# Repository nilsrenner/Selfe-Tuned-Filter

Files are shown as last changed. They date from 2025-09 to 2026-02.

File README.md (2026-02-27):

# Self-Tuned-Filter

## Kontext
Diese Bachelorarbeit wurde im März 2026 an der **Hochschule Bremen** (Fakultät 4: Elektrotechnik und Informatik) abgegeben. Ziel war das Design, die Simulation und die messtechnische Verifizierung eines analogen, selbsteinstellenden Filters auf Basis eines spannungsgesteuerten Biquad-Filters.

## Projektbeschreibung
Das System passt seine Resonanzfrequenz eigenständig an die anliegende Eingangsfrequenz an. Die zentrale Steuerung übernimmt ein **Raspberry Pi Pico 2 W**, der als digitale Schnittstelle dient.

* **Wissenschaftlicher Kern:** Eigenständige Herleitung und Verifikation der Gleichungen zur Resonanzfrequenz (Korrektur fehlerhafter Angaben im ASLK-PRO Manual).
* **Hardware:** Entwicklung eines PCB für die Umsetzung des Self-Tuned Systems.
* **Software:** MicroPython-Skript zur Steuerung des Filters über eine webbasierte Oberfläche. Nulldurchgangszähler für die Eingangsfrequenzdetektion.
* **Ergebnis:** Für frequenzgebende Widerstände von 1 kΩ wurde die Funktionalität im Bereich von ca. **240 Hz bis über 12 kHz** nachgewiesen. 

---

## Struktur des Repositoriums
Die Quelldaten sind wie folgt strukturiert:

| Ordner / Datei | Inhalt |
| :--- | :--- |
| **`001_Simulation_und_Schaltungsentwurf`** | Datenblätter, Simulationen und PCB-Entwürfe (V1 & V2). |
| **`002_3D_Modell`** | 3D-Modell der PCB-Halterung für den Versuchsaufbau. |
| **`003_Messdaten`** | Rohdaten der Messungen (Oszilloskop und Red Pitaya). |
| **`004_Code`** | MicroPython-Skripts für den Raspberry Pi Pico 2 W. |
| **`005_Dokumentation`** | LaTeX-Quellcode der Arbeit. |
| **`Bachelor_Thesis_Renner_2026.pdf`** | Die Bachelorarbeit in digitaler Form. |

---

## Autor & Prüfer
* **Autor:** Nils Renner
* **Prüfer:** Prof. Dr.-Ing. Mirco Meiners & Prof. Dr. Sören Peik

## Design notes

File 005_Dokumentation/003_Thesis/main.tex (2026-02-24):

\documentclass[a4paper,11pt]{book}

% Sprach- und Zeichencodierung
\usepackage[T1]{fontenc}       % korrekte Darstellung von Umlauten
\usepackage[utf8]{inputenc}    % UTF-8 Eingabekodierung
\usepackage[german]{babel}    % deutsche Spracheinstellungen
\usepackage{microtype}

% Mathematik
\usepackage{amsmath, amssymb, mathtools} % erweiterte Matheumgebungen
\usepackage{siunitx}                     % SI-Einheiten und Zahlenformatierung
\sisetup{per-mode=symbol}

% Layout und Formatierung
\usepackage{geometry}          % Seitenränder einstellen
\usepackage{graphicx}          % Grafiken einbinden
\usepackage{pdfpages}

\usepackage{float}             % präzise Positionierung von Bildern
\usepackage{fancyhdr}          % Kopf- und Fußzeilen
\usepackage{titlesec}          % Überschriftenformatierung
\usepackage{tocloft}           % Inhaltsverzeichnis anpassen
\usepackage{makecell}          % Zeilenumbrüche in Tabellenzellen
\usepackage{array}             % erweiterte Tabellenspalten
\usepackage{booktabs,tabularx} % schöne Tabellen
\usepackage{longtable}         % Tabellen über mehrere Seiten
\usepackage{caption}           % bessere Bild-/Tabellenunterschriften
\usepackage{subcaption}        % Subfigures
\usepackage{enumitem}          % flexible Listen
\usepackage{subfiles}           % Kapitel einzeln kompilierbar
\usepackage{tikz}
\usepackage{circuitikz}
\usetikzlibrary{arrows.meta, positioning}

\usepackage{pgfplots}
\pgfplotsset{compat=1.18}
%\newcommand{\datapath}{../../003_Messdaten}
\usepgfplotslibrary{groupplots}

% Literatur
\usepackage{csquotes}                           % saubere Anführungszeichen
\usepackage[backend=biber, style=ieee]{biblatex} % IEEE-Stil mit Biber
\addbibresource{Literaturverzeichnis.bib}       % Literaturdatenbank einbinden
\usepackage[acronym]{glossaries-extra}
\setabbreviationstyle[acronym]{long-short}
\input{acronyms.tex}
\makeglossaries

% Zusatzfunktionen
\usepackage{lastpage}    % für "Seite X von Y"
\usepackage{xcolor}      % Farben (für Listings etc.)
\usepackage{listings}    % Codeblöcke
\usepackage[hidelinks]{hyperref} % Hyperlinks (immer zuletzt)

% Einstellungen für Code
\lstset{
    basicstyle=\ttfamily\scriptsize, % Sehr kleine Schrift für Platzersparnis
    breaklines=true,                 % Automatische Zeilenumbrüche
    frame=tb,                        % Linien oben und unten
    tabsize=2,
    literate={Ω}{{\textOmega}}1,     % Ersetzt das Omega-Zeichen durch LaTeX-Befehl
    extendedchars=true,
    inputencoding=utf8
}

% Seitenlayout
\geometry{
  top=2cm,
  bottom=3cm,
  left=2.5cm,
  right=2.5cm
}
\setlength\parindent{0pt} % kein Absatzeinzug

% Kopf- und Fußzeilen
\setlength\headheight{55pt}%26
\setlength\headsep{15pt}%35
\addtolength{\topmargin}{-12pt}

\pagestyle{fancy}
\fancyhf{}
\lhead{\raisebox{-0.2cm}{}}
\chead{Bachelor Thesis\par Nils Renner}
\rhead{\raisebox{-0.2cm}{}}
\cfoot{\thepage}

% Dokumentbeginn
\begin{document}

\frontmatter
\pagenumbering{roman}
\pagestyle{empty} % unterdrückung des headers
\setcounter{page}{1}

% Titelseite
\begin{titlepage}
    \begin{center}
    \\[1cm]
    \vspace{0.5cm}
    {\huge\bfseries Implementierung eines selbsteinstellenden Filters auf Basis eines spannungsgesteuerten Biquad-Filters\par}
    \vspace{1.5cm}
    {\large\bfseries Implementation of a Self-Tuned Filter Based on a Voltage-Controlled Biquad Filter\par}
    
    \vspace{2cm}
    {\Large\bfseries Bachelor Thesis\par}
    {\large Fakultät 4: Elektrotechnik und Informatik\par} 
    {\large Studiengang: Elektrotechnik B. Eng.\par}
    {\large Vertiefungsrichtung: Informationstechnik\par}
    %Presented for Attainment of the Academic Degree of \par
    %Bachelor of Engineering at the City University of Applied Sciences Bremen\par
    \end{center}
    \vspace{2cm}

    \begin{tabular}{l l}
            \textbf{Autor:} & Nils Renner, Wulfhoopstraße 34a, 28201 Bremen \\
            \textbf{Matr.-Nr.:} & 5197659 \\
            \textbf{Abgabetermin:} & 2. März, 2026 \\ \\ \\
            \textbf{Prüfer:} & Prof. Dr.-Ing. Mirco Meiners,\\ & \small{Hochschule Bremen,}\\ & \small{Concept Engineering SoCs and Design}\\ \\
            \textbf{} & Prof. Dr. Sören Peik,\\ & \small{Hochschule Bremen,}\\ & \small{Microwave Technology and Satellite Communications} \\
    \end{tabular}

    \vfill
\end{titlepage}

\newpage
\null
\thispagestyle{empty} 

% Erklärung zur selbstständigen Arbeit
\clearpage{\pagestyle{empty}\cleardoublepage}
%\cleardoublepage % Sorgt dafür, dass das Kapitel auf einer neuen (rechten) Seite beginnt
\phantomsection 
\addcontentsline{toc}{chapter}{Erklärung über das Eigenständige Erstellen der Arbeit} 

\includepdf[pages={1}, scale=1, pagecommand={}]{KI-Eigenständigkeitserklärung_Renner.pdf}

% Acknowledgements / Danksagung
\clearpage{\pagestyle{empty}\cleardoublepage}
\chapter*{Danksagung}
\addcontentsline{toc}{chapter}{Danksagung}

An dieser Stelle möchte ich mich bei all jenen bedanken, die mich während der Erstellung dieser Bachelorarbeit unterstützt haben.\par
\medskip
Mein besonderer Dank gilt Herrn Prof. Dr.-Ing. Mirco Meiners für die Übernahme der Erstbetreuung sowie für die wertvollen Anregungen und konstruktiven Vorschläge während der Bearbeitungszeit.\par
\medskip
Ebenso bedanke ich mich herzlich bei Herrn Dipl.-Ing. Tim Ziemann für das Layout-Review und die damit verbundene Beratung.\par
\medskip
Für die technische Unterstützung danke ich Simon Cossens, der mir bei allen Fragen rund um die hardwaretechnischen Anforderungen stets als kompetenter Ansprechpartner zur Seite stand.\par
\medskip
Ein großes Dankeschön für das gründliche Korrekturlesen und das hilfreiche Feedback gebührt zudem Ali Mert Ackey, Alicia von Ahlen, Daniel Albinger, Janik Holland, Melia Keil, Finn Ringelsiep, Julian Scheeler und Jana Vogt.\par
\medskip
Abschließend möchte ich mich noch bei meinem Vater für den kontinuierlichen Austausch über meine Ideen und Pläne sowie für die wertvolle kritische Reflexion während des gesamten Prozesses bedanken. 

% Abstract
\clearpage{\pagestyle{empty}\cleardoublepage}
\chapter*{Abstrakt}
\addcontentsline{toc}{chapter}{Abstrakt}
Die vorliegende Bachelorarbeit befasst sich mit dem Design, der Simulation und der messtechnischen Verifizierung eines analogen, selbsteinstellenden Filters (Self-Tuned Filter). Ziel der Arbeit war die Entwicklung eines Systems, das seine Resonanzfrequenz eigenständig an die anliegende Eingangsfrequenz anpasst. \par
\medskip

Im Rahmen der Arbeit wurde ein PCB entwickelt, auf dem ein Raspberry Pi Pico 2 W als zentrale Steuereinheit und digitale Schnittstelle dient. Über eine webbasierte Benutzeroberfläche können die Filterparameter über Digitalpotentiometer gesteuert und die mithilfe des Nulldurchgangszählers ermittelte Frequenz systematisch erfasst und visualisiert werden. Ein wesentlicher Teil der Arbeit bestand in der eigenständigen Herleitung und Verifikation der Gleichungen zur Resonanzfrequenz des Systems, wodurch ein umfassendes Verständnis der physikalischen Zusammenhänge innerhalb des Self-Tuned Filters aufgebaut werden konnte.\par
\medskip

Ein zentrales Ergebnis der Arbeit ist der Nachweis der Funktionalität des Systems in einem Frequenzbereich von ca. \SI{240}{\hertz} bis über \SI{12}{\kilo\hertz}. Dabei konnte gezeigt werden, dass die Stabilität der Regelung maßgeblich von der Amplitude des Eingangssignals abhängt. Durch eine gezielte Pegelanpassung auf \SI{0.5}{\volt} wurde der störende AC-Anteil auf der Steuerspannung um über \SI{80}{\percent} reduziert, was den operativen Arbeitsbereich des Filters signifikant erweiterte. Die Arbeit belegt somit die erfolgreiche Realisierung eines stabilen, selbsteinstellenden Filtersystems.\par
\medskip

\section*{Abstract}
This bachelor thesis deals with the design, simulation, and metrological verification of an analog, self-tuning filter. The aim of the thesis was to develop a system that independently adjusts its resonance frequency to the applied input frequency. \par
\medskip

As part of the thesis, a PCB was developed on which a Raspberry Pi Pico 2 W serves as the central control unit and digital interface. Via a web-based user interface, the filter parameters can be controlled via digital potentiometers and the frequency determined using the zero-crossing counter can be systematically recorded and visualized. A significant part of the work consisted of independently deriving and verifying the equations for the resonance frequency of the system, which enabled a comprehensive understanding of the physical relationships within the self-tuned filter to be established.\par
\medskip

A key result of the work is the verification of the system's functionality in a frequency range from approximately \SI{240}{\hertz} to over \SI{12}{\kilo\hertz}. It was shown that the stability of the control depends significantly on the amplitude of the input signal. By specifically adjusting the level to \SI{0.5}{\volt}, the disruptive AC component on the control voltage was reduced by over \SI{80}{\percent}, which significantly expanded the filter's operational range. The work thus demonstrates the successful implementation of a stable, self-adjusting filter system.\par
\medskip

% Inhaltsverzeichnis
\clearpage{\pagestyle{empty}\cleardoublepage}
\tableofcontents

% Abbildungsverzeichnis
\clearpage{\pagestyle{empty}\cleardoublepage}
\listoffigures
\addcontentsline{toc}{chapter}{Abbildungsverzeichnis}

% Tabellenverzeichnis 
\clearpage{\pagestyle{empty}\cleardoublepage}
\listoftables
\addcontentsline{toc}{chapter}{Tabellenverzeichnis}

% Abkürzungsverzeichnis
\clearpage{\pagestyle{empty}\cleardoublepage}
\printglossary[type=\acronymtype, title=Abkürzungsverzeichnis, nonumberlist]
%\addcontentsline{toc}{chapter}{Abkürzungsverzeichnis}

\mainmatter
\pagestyle{fancy}
% Haupttext
% \newpage  
\pagenumbering{arabic}  
\setcounter{page}{1}

\subfile{Einleitung/Einleitung.tex}

% \newpage
\subfile{Tools/Tools.tex}

% \newpage
\subfile{Theorie/Theorie_alt.tex}
% \newpage
\subfile{Theorie/Theorie_neu.tex}

% \newpage
\subfile{Simulation/Simulation.tex}

% \newpage
\subfile{systemdesign/systemdesign.tex}

% \newpage
\subfile{Messung/Messung.tex}

% \newpage
\subfile{Auswertung/Auswertung.tex}

% \newpage
\subfile{Fazit/Fazit.tex}

\backmatter
\appendix
% \newpage
\printbibliography

\newpage
\chapter{Messmittel}
\begin{table}[h]
    \centering
    \begin{tabular}{c|c|c|c}
        \textbf{Messmittel} & \textbf{Hersteller} & \textbf{Bezeichnung} & \textbf{Gerätenummer} \\ \hline
        Oszilloskop & Rohde \& Schwarz & RTB2002 & 75669148 \\
        Signalgenerator & RIGOL & DG1032 & 75001816 \\
        Red Pitaya & Red Pitaya & STEMlab 125-14 & - \\
        Multimeter & Fluke & 175 & 1600 5357 \\
    \end{tabular}
\end{table}

\newpage
\chapter{KI-Prompt-Engineering}

\section{Erstellung einer python Simulation eines Slef-Tuned Filters anhand einer diskreten und proportionalen Regelung}

Für diesen Prompt wurde Le Chat von Mistral verwendet. \par
\medskip

\begin{enumerate}
\item \textbf{Rolle:} Experte für Python-Programmierung und Signalverarbeitung.
\item \textbf{Ziel:} Erstelle eine Python-Simulation eines Self-Tuned Filters (VCF), die exakt das Verhalten einer diskreten Stufenregelung auf Basis der Phasenlage abbildet.
\item \textbf{Logik:} Erzeuge ein Referenz-Sinussignal (\SI{1000}{\hertz}) und ein VCF-Signal (Start: \SI{1050}{\hertz}). Prüfe die Phase des VCF-Signals exakt an den positiven Nulldurchgängen der Referenz.
\item \textbf{Regelgesetz:} Befindet sich die Phase im Bereich von \SI{-90}{\degree} bis \SI{90}{\degree}, wird die Frequenz um \SI{10}{\hertz} erhöht; andernfalls wird sie um \SI{10}{\hertz} verringert.
\item \textbf{Implementierung:} Das VCF-Signal muss durch fortlaufende Integration der Phase berechnet werden , um Phasensprünge bei Frequenzänderungen zu vermeiden.
\end{enumerate}

Anschließend wird der Code erweitert, sodass die Frequenzsprünge proportional anhand der Phasenlage verändert werden.\par
\medskip

\begin{enumerate}
\item \textbf{Ziel:} Modifiziere die vorherige Simulation hin zu einer proportionalen Regelung (P-Regler).
\item \textbf{Setup:} Erhöhe die Simulationsdauer auf \SI{0.5}{\second}.
\item \textbf{Logik:} Die Frequenzänderung soll nun kontinuierlich erfolgen. Die Stärke der Korrektur  wird über eine trigonometrische Gewichtung (z. B. Absolutwert des Cosinus der Phase) gesteuert.
\item \textbf{Verhalten:} Dies stellt sicher, dass in der Umgebung von \SI{0}{\degree} und \SI{180}{\degree} maximale Frequenzänderungen resultieren, während die Korrektur an den Arbeitspunkten \SI{90}{\degree} und \SI{270}{\degree} gegen Null strebt.
\item \textbf{Richtung:} Ist die Phase im Bereich von \SI{-90}{\degree} bis \SI{90}{\degree} soll die Frequenz erhöht werden, andernfalls wird die Frequenz verringert.
\end{enumerate}

\newpage

\section{Erstellung des HTTP-Server und Erweiterung des Frequenzzählers}
\label{sec:prompt3}

Dieser Prompt dient der finalen Migration des Projekts auf Hardware-gestützte Frequenzmessung. Für diesen Prompt wurde Gemini 3 Flash von Google verwendet. \par
\medskip

\begin{enumerate}
    \item \textbf{Rolle:} Experte für Embedded Systems (RP2350) und Python-Webentwicklung.
    \item \textbf{Ziel:} Erweitere mein Python-Skript für einen Raspberry Pi Pico (RP2040). Der aktuelle Code enthält eine SPI-Ansteuerung für Digitalpotentiometer, einen Webserver im AP-Modus und einen IRQ-Frequenzzähler.
    \item \textbf{Upgrade:} Ersetze den IRQ-Zähler durch einen PIO-Zähler (Pin 21). Die CPU darf nicht blockiert werden. Implementiere einen \texttt{machine.Timer} (2s Intervall), der den Wert ausliest und auf 1 Hz rundet. Speichere die letzten 5 Messwerte.
    \item \textbf{UI:} Erstelle ein zweispaltiges HTML-Layout. Links: Eingabefelder für Frequenz, Güte und Verstärkung sowie aktuelle Zustände. Rechts: Tabelle der letzten 5 Messwerte. Auto-Refresh: 15s.
    \item \textbf{Performance:} Der Webserver muss sofort reagieren (Nutzung globaler Variablen).
    \item \textbf{Basis-Code:}
\end{enumerate}

\lstset{
    basicstyle=\ttfamily\scriptsize,
    breaklines=true,
    extendedchars=true,
    literate={-}{{-}}1 % Verhindert Probleme mit Bindestrichen
}

\begin{lstlisting}[caption={Basis-Code Teil 1: Setup und Logik}]
import math
from machine import Pin, SPI
import network, socket, time

led = Pin("LED", Pin.OUT)
for _ in range(5):
    led.value(1); time.sleep(0.1)
    led.value(0); time.sleep(0.1)
led.value(1)

# Parameter und Berechnungen
freq0, Q_val, H0_val = 160, 1, 1
max_step, r_ges, wiper_r = 255, 9650, 4

def clamp_and_round(x):
    return int(round(max(0, min(255, x))))

def freq_2_bit(f0):
    w0 = f0 * 2 * 3.14159
    r = 1/(w0 * 1e-6)
    wiper = max_step * (1 - r/r_ges) + wiper_r
    return clamp_and_round(wiper), r

def Q_2_bit(Q_val):
    r_opv = 1000
    Q_r = Q_val * r_opv
    Q_wiper = max_step * (1 - Q_r/r_ges) + wiper_r
    return clamp_and_round(Q_wiper), Q_r

def H0_2_bit(H0_val):
    r_opv = 1000
    H0_r = r_opv/H0_val
    H0_wiper = max_step * (1 - H0_r/r_ges) + wiper_r
    #H0_wiper = int(round(H0_wiper))
    return clamp_and_round(H0_wiper), H0_r

def bit_2_res(bit):
    res = r_ges * (1 - (bit-wiper_r)/max_step) 
    return res

\end{lstlisting}

\begin{lstlisting}[caption={Basis-Code Teil 2: Hardware-Schnittstellen}]
def update_filter(f, q, h):
    fw, fr = freq_2_bit(f)
    set_wiper0(cs1, fw); set_wiper1(cs1, fw)

# Hardware Konfiguration (SPI & Pins)
spi = SPI(0, baudrate=1000000, sck=Pin(18), mosi=Pin(19), miso=Pin(16))
cs1, cs2 = Pin(17, Pin.OUT, value=1), Pin(20, Pin.OUT, value=1)

def mcp_write(cs, cmd, val):
    cs.value(0)
    spi.write(bytes([cmd & 0xFF, val & 0xFF]))
    cs.value(1)

def set_wiper0(c, v): mcp_write(c, 0, v)
def set_wiper1(c, v): mcp_write(c, 16, v)

# WLAN Access Point starten
ap = network.WLAN(network.AP_IF)
ap.active(True)
ap.config(essid="Pico-Filter", password="filter123")
ap.ifconfig(("192.168.4.1", "255.255.255.0", "192.168.4.1", "8.8.8.8"))
\end{lstlisting}

\end{document}

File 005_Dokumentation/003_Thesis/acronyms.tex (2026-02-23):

\newacronym{pll}{PLL}{Phase-Locked Loop}%

%\newacronym{digipot}{DP}{Digitalpotentiometer}

\newacronym{opv}{OPV}{Operationsverstärker}%fertig

\newacronym{pd}{PD}{Phasendetektor}%

\newacronym{vco}{VCO}{Voltage-Controlled Oscillator}%

\newacronym{vcf}{VCF}{Voltage-Controlled Filter}%

\newacronym{pcb}{PCB}{Printed Circuit Board}%

\newacronym{mcu}{MCU}{Microcontroller Unit}%

\newacronym{gpio}{GPIO}{General Purpose Input Output}

\newacronym{spi}{SPI}{Serial Peripheral Interface}

\newacronym{adc}{ADC}{Analog Digital Converter}%

\newacronym{ui}{UI}{User Interface}

\newacronym{wlan}{WLAN}{Wireless Local Area Network}

\newacronym{eeprom}{EEPROM}{Electrically Erasable Programmable Read-Only Memory}

\newacronym{http}{HTTP}{Hypertext Transfer Protocol}

\newacronym{html}{HTML}{Hypertext Markup Language}

\newacronym{ip}{IP}{Internet Protocol}

\newacronym{ram}{RAM}{Random Access Memory}

\newacronym{gbw}{GBW}{Gain Bandwidth Product}

%\newacronym{sf}{SF}{Scale Factor}

\newacronym{ic}{IC}{Integrated Circuit}

\newacronym{dut}{DUT}{Device Under Test}

\newacronym{smd}{SMD}{Surface Mounted Device}

\newacronym{tht}{THT}{Through Hole Technology}

\newacronym{bnc}{BNC}{Bayonet Neill Concelman}

\newacronym{moscow}{MoSCoW}{Must-have, Should-have, Could-have, Won't-have}

\newacronym{llm}{LLM}{Large Language Model}

\newacronym{ecad}{ECAD}{Electronic Computer-Aided Design}

\newacronym{pio}{PIO}{Programmable Input/Output}

\newacronym{fsk}{FSK}{Frequency Shift Keying}

%fft

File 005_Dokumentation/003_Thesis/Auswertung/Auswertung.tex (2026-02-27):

\documentclass[../main_config.tex]{subfiles}
\begin{document}

\chapter{Auswertung}

In diesem Kapitel werden die Ergebnisse der Endmessungen präsentiert und analysiert. Da die zweite Platineniteration erst zwei Wochen vor der Abgabe eintraf, beziehen sich alle nachfolgenden Messwerte auf die Version 1 des \gls{pcb}.\par
\medskip

Die vorgestellten Ergebnisse basieren somit auf der erste Iteration, welche mit einer Versorgungsspannung von \SI{\pm11}{\volt} betrieben wird. Die resultierende Referenzspannung der Multiplizierer beträgt dabei anstatt der angestrebten \SI{10}{\volt} nur etwa \SI{9.74}{\volt}. Die Ergebnisse der zweiten Platineniteration werden im Rahmen der Verteidigung vorgestellt.\par
\medskip

\section{Kleinsingnalanalyse des Gesamtsystems}
Die Kleinsignalanalyse über den Red Pitaya liefert auch nach der Optimierung der einzelnen Bauteile des Systems keine neuen Ergebnisse. Der bisher ungeklährte Verlauf bleibt konsistent und ist in Abbildung \ref{fig:ac_final} dargestellt.\par
\medskip

\begin{figure} [H]
  \centering
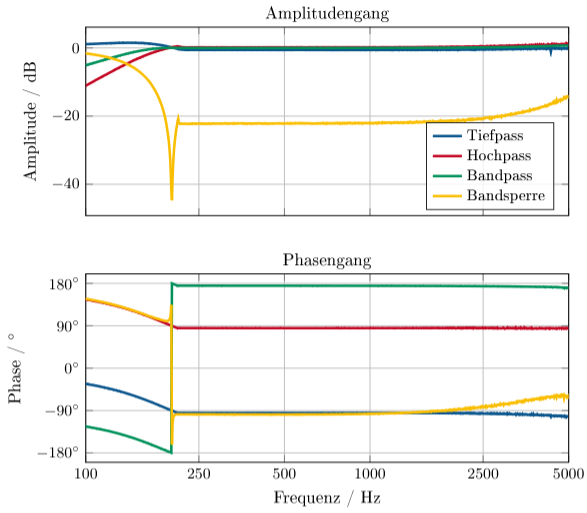
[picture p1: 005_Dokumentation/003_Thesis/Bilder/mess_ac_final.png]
    
    \caption{ac-Final}
    \label{fig:ac_final}
\end{figure}

%\begin{figure} [H]
%  \centering
%    \includegraphics[width=0.9\linewidth]{../Bilder/ac_final.png}
%    \caption{ac-Final}
%    \label{fig:ac_final}
%\end{figure}

Wie bereits in Kapitel \ref{sec:mess_ac} erläutert, stagnieren die Amplituden- und Phasenverläufe kurz nach Erreichen der Resonanzfrequenz. Eine Vermutung für dieses Verhalten hängt mit der Arbeitsweise des Self-Tuned Filters zusammen, der versucht seine Resonanzfrequenz immer auf die eingehende Frequenz einzustellen. \par
\medskip

Wird nun ein in der Frequenz kontinuierlich steigendes Eingangssignal angelegt, stellt sich der Filter erst in Richtung der geringen Startfrequenz ein. In Abbldung \ref{fig:ac_final} ist bei etwa \SI{200}{\hertz} zu sehen, wie Resonanzfrequenz und Eingangsfrequenz übereinstimmen. Anschließend versucht der Fitler der steigenden Eingangsfrequenz zu folgen, bleibt aber aufgrund der gerineren Änderungsrate hinter der Eingangsfrequenz zurück. In diesem Fall wäre die Kleinsignalanalyse nicht zur Charakterisierung des Filters geeignet.\par
\medskip

Um diese Hypothese zu überprüfen, wird die Anzahl der Messpunkte von \num{100} auf \num{1000} erhöht. Die höhere Anzahl führt zu einer langsameren Veränderung der Eingangsspannung, da der Red Pitaya die Frequenzpunkte nacheinander abarbeitet und jeder eine bestimmte Aufnahmezeit benötigt. Die dabei aufgenommenen Ergebnisse zeigen keine Veränderung zu vorherigen Messungen. Das Problem besteht also nicht in der zu geringen Änderungsrate des Systems. \par
\medskip

Das genaue Verhalten des Systems bei der Kleinsignalanalyse kann durch diese alleinige Beobachtung also nicht genau geklärt werden. \par
\medskip

\section{Frequenz-Sprungantworten des Gesamtsystems}
Um die Erkenntnisse aus Theorie und Simulation zu validieren, werden in diesem Abschnitt die experimentellen Ergebnisse der Sprungantwort ausgewertet und mit der Simulation verglichen.\par
\medskip

Dabei soll zunächst untersucht werden, inwieweit die Resonanzfrequenz des Filters der eingehenden Frequenz im stationären Zustand (ohne \gls{fsk}-Modulation) folgt. In Tabelle \ref{tab:ausw_mess_mfreq2} ist die gemessene Steuerspannung $V_c$ sowie die daraus berechnete Resonanzfrequenz $f_0$ für verschiedene Eingangsfrequenzen bei einer Eingangsamplitude von $V_{in_{pp}} = \SI{2}{\volt}$ aufgelistet.\par
\medskip

\begin{table}[h]
    \centering
    \begin{tabular}{c|c|c|c}
        \textbf{Eingang $f_{in}$ / \si{\hertz}} & \textbf{Messung $V_c$ / \si{\volt}} & \textbf{$f_0$ / \si{\hertz}} & \textbf{Abweichung / \%}  \\ \hline
        %230 & 8.9 & 174 & - \\
        250 & 7.61 & 204 & -18.4 \\
        500 & 3.62 & 428 & -14.4 \\
        750 & 2.42 & 641 & -14.5 \\
        1000 & 1.82 & 852 & -14.8 \\
        2000 & 0.92 & 1685 & -15.8 \\
        3000 & 0.6 & 2584 & -13,9 \\
        4000 & 0.42 & 3690 & -7,8 \\
    \end{tabular}
    \caption{Vergleich der Mittenfrequenz bei Variation von $f_{in}$}
    \label{tab:ausw_mess_mfreq2}
\end{table}

Die Ergebnisse zeigen eindeutig, dass das System über die Steuerspannung auf die eingehende Frequenz reagiert. Auffällig ist dabei die fast konstante Abweichung von etwa \SI{14}{\percent} bis \SI{16}{\percent} im Bereich zwischen \SI{500}{\hertz} und \SI{3000}{\hertz}. Dieser stabile Offset könnte bedeuten, dass kein Fehler in der Regelung vorliegt, sondern ein unbekannter systematischer Skalierungsfehler kompensiert wird. So werden auftretende Bauteiltolleranzen oder Abweichungen der realen Multipliziererkonstante von den theoretischen Idealwerten mit in das Regelverhalten einbezogen. Demnach weißt das System ein stabiles Einschwingverhalten auf, regelt sich selbst aufgrund von unbekannten Einflussfaktoren auf einen Arbeitspunkt mit konstantem Offset ein.\par
\medskip

\subsection{Analyse des AC-Anteils auf der Steuerspannung}
In Abbildung \ref{fig:sprung_mess_vc} ist das Einschwingverhalten über den Frequenzsprung von \SI{750}{\hertz} nach \SI{3}{\kilo\hertz} sowie den Rücksprung abgebildet. Dabei ist ersichtlich, dass der Gleichspannungsanteil von $V_c$ mit einer Wechselspannung hoher Amplitude überlagert wird. \par
\medskip

\begin{figure} [H]
  \centering
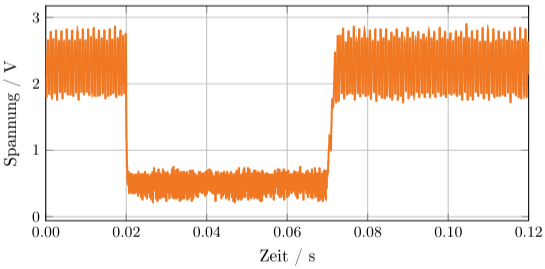
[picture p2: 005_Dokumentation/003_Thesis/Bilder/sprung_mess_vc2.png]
    
    \caption{Einschwingverhalten der Steuerspannung $V_c$ für $V_{in_{pp}} = \SI{2}{\volt}$}
    \label{fig:sprung_mess_vc}
\end{figure}

%\begin{figure} [H]
%  \centering
%    \includegraphics[width=0.9\linewidth]{../Bilder/sprung_mess_vc.png}
%    \caption{Einschwingverhalten der Steuerspannung $V_c$ für $V_{in_{pp}} = \SI{2}{\volt}$}
%    \label{fig:sprung_mess_vc}
%\end{figure}

Bei der Betrachtung der Tabelle \ref{tab:ausw_mess_vc} fällt auf, dass die Amplitude des AC-Anteils für geringe Eingangsfrequenzen deutlich zunimmt. Diese Beobachtung lässt sich anhand der Multiplikation im \gls{pd} erklären, da bei höheren Eingangsfrequenzen höherfrequente Mischprodukte erzeugt werden. Der Integrator im \gls{pd} weist Tiefpassverhalten auf, wodurch diese höheren Frequenzen deutlich besser unterdrückt werden können. Eine hohe AC-Komponente ist für das Filterverhalten ungünstig, da die nutzbare Bandbreite des Systems einschränkt wird.\par
\medskip

\begin{table}[h]
    \centering
    \begin{tabular}{c|c|c|c}
        \textbf{Eingang: $f_{in}$ / \si{\hertz}} & \textbf{$V_p+$ / \si{\volt}} & \textbf{$V_p-$ / \si{\volt}} & \textbf{AC-Anteil / \si{\volt}}  \\ \hline
        240 & 10.06 & 6.9 & 3.16 \\
        500 & 4.47 & 2.92 & 1.55 \\
        1000 & 2.28 & 1.37 & 0.91 \\
        2000 & 1.18 & 0.6 & 0.58 \\
        4000 & 0.66 & 0.16 & 0.5 \\
        4250 & 0.65 & 0.12 & 0.53 \\
    \end{tabular}
    \caption{Vergleich des AC-Anteils der Mittenfrequenz bei Variation von $f_{in}$}
    \label{tab:ausw_mess_vc}
\end{table}

Im Verlauf der Messungen wurde festgestellt, dass die Höhe der AC-Komponente direkt von der Amplitude des Eingangssignals abhängt. Da $V_{in}$ eine der beiden Eingangsgrößen des \gls{pd} ist, sinkt bei Verringerung der Amplitude somit auch der Pegel der AC-Komponente. Um die Stabilität zu erhöhen, wird für die finalen Messungen eine geringere Spitze-Spitze-Spannung von $V_{in_{pp}} = \SI{0.5}{\volt}$ gewählt. Einen Spannungswert unterhalb von \SI{0.3}{\volt} kann vom System nicht mehr als Eingangssignal detektieren. (System verhält sich als läge kein Signal an.)\par
\medskip

Bei der Gegenüberstellung der Messdaten fällt eine gewaltige Reduktion der AC-Komponente durch die Anpassung der Eingangsfrequenz auf. Die prozenzuale Reduktion dieses Störfaktors liegt bei den Vergleichsfrequenzen von \SI{240}{\hertz}, \SI{1000}{\hertz} und \SI{2000}{\hertz} konsistent bei über \SI{80}{\percent}. \par
\medskip

\begin{table}[h]
    \centering
    \begin{tabular}{c|c|c|c}
        \textbf{Eingang: $f_{in}$ / \si{\hertz}} & \textbf{$V_p+$ / \si{\volt}} & \textbf{$V_p-$ / \si{\volt}} & \textbf{AC-Anteil / \si{\volt}}  \\ \hline
        240 & 10.22 & 9.7 & 520 \\
        500 & 3.9 & 3.67 & 230 \\
        1000 & 1.99 & 1.84 & 150 \\
        2000 & 1 & 0.89 & 110 \\
        5000 & 0.42 & 0.33 & 90 \\
    \end{tabular}
    \caption{AC-Anteil bei reduzierter Eingangsspannung $V_{in_{pp}}=\SI{0.5}{\volt}$}
    \label{tab:ausw_mess_mfreq05}
\end{table}

%Für die Bestimmung der unteren Frequenzgrenze des Systems wird beobachtet, ab welcher Frequenz die positiven Spitzen der AC-Komponente $V_p+$ die Sättigungsgrenze des Integrators erreichen. Bei einer Versorgungsspannung von \SI{\pm11}{\volt} wird die Spannung bei etwa \SI{10.44}{\volt} gekappt. Demnach ist \SI{240}{\hertz} die unterste einstellbare Frequenz, die nicht durch die Sättigungsgrenze verfälscht wird. Interessanter weise gilt diese Frequenz sowohl für eine Eingangsspannung von $V_{in_{pp}}= \SI{2}{\volt}$ als auch für $V_{in_{pp}}= \SI{0.5}{\volt}$. \par
\medskip

%Auch für die Ermittlung der oberen Frequenzgrenze spielt die Größe der AC-Komponente eine wichtige Rolle. Da das System nicht beliebig kleine Spannungswerte für $V_c$ verarbeiten kann, ist es von Vorteil die untere Grenze der AC-Schwingung soweit wie möglich zu reduzieren. Der geringste stabile Wert liegt sowohl in der Simulation als auch in der Messung bei ca. \SI{90}{\milli\volt}. Durch die Anpassung der Eingangsspannung kann das System nun eine Frequenz von über \SI{12}{\kilo\hertz} erreichen. Oberhalb dieser Grenze treten ab \SI{12.3}{\kilo\hertz} massive Amplitudenüberhöhungen auf, die das System instabil werden lassen.\par
\medskip

Die Veränderung der Eingangsspannung stablisiert die Regelung also erheblich, da die Steuerspannung $V_c$ nun erst bei deutlich höheren Frequenzen in die Sättigungsgrenzen des Integrators läuft.

%Auch die Amplitude der AC-Anteile wird durch die verringerung der Eingangsspannung stark verringert. Das ist eideutig darauf zu erklären, dass Vin ein eingangssignal des PD ist und bei kleinerer Amplitude auch die Amplitude der ausgehenden hochfrequenzen geringer ausfallen. Dabei wird der Anteil bei hohen frequeunzen wieder sichtbar kleiner, startet aber auch schon bei einem deutlich geringeren wert. ab etwa \SI{5}{\kilo\hertz} treten kurzzeitig stärkerer Spannungsspitzen auf, die meisten werte der AC sind dabei aber um etwa 1/3 kleiner. Das könnte die Stagnation der kleiner werdenen AC-Amplitude erklären. 

Bei Vergleich des Einschwingverhaltens des realen Systems mit der optimierten Eingangsspannung mit der Simulation zeigt sich ein signifikanter Unterschied in der Einschwingzeit. Wie in Abbildung \ref{fig:sprung_mess_vc2} zusehen ist die Einschwingzeit der Messung beim positiven Sprung mit etwa \SI{20}{\milli\second} etwa doppelt so schnell wie die Simulation. Noch größer ist der Unterschied für den negativen Sprung von \SI{3000}{\hertz} auf \SI{750}{\hertz}. Hier ist das \gls{dut} ebenfalls nach etwa \SI{22}{\milli\second} eingeschwungen, die Simulation benötigt jedoch ca. \SI{80}{\milli\second}. \textbf{warum?}\par
\medskip
%Diese Abweichung deutet darauf hin, dass die reale Regelverstärkung des Systems, welche maßgeblich durch die Verstärkungskonstanten der analogen Multiplizierer im Phasendetektor bestimmt wird, höher ausfällt als im idealisierten Simulationsmodell hinterlegt. Zudem könnten parasitäre Effekte oder eine abweichende Charakteristik des Integrators in der Realität zu dieser beschleunigten Anpassung führen.

\begin{figure} [H]
  \centering
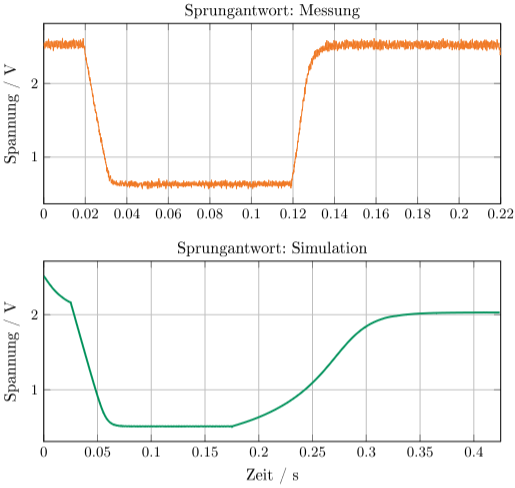
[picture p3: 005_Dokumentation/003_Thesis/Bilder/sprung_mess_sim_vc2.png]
    
    \caption{Verlauf der Steuerspannung $V_c$}
    \label{fig:sprung_mess_vc2}
\end{figure}

%\begin{figure} [H]
%  \centering
%    \includegraphics[width=0.9\linewidth]{../Bilder/sprung_mess_sim_vc.png}
%    \caption{Verlauf der Steuerspannung $V_c$}
%    \label{fig:sprung_mess_vc2}
%\end{figure}

\subsection{Betrachtung der Filterausgänge}
Nach der Untersuchung der Steuerspannung soll nun die Einschwingreaktion der einzelnen Filterausgänge analysiert werden.\par
\medskip

Der zuerst betrachtete Filtertyp ist der in Abbildung \ref{fig:sprung_mess_hp} zu sehende Hochpass. Beim positiven Frequenzsprung knickt die Amplitude interessanterweise kurzzeitig ein. Auch kann die in der Simulation sehr ausgeprägte Resonanzüberhöhung hier nicht detektert werden. Beim Rücksprung auf \SI{750}{\hertz} ist der Amplitudeneinbruch eindeutig erkennbar, da das Signal kurzzeitig im Sperrbereich des Filters liegt, bevor die Grenzfrequenz nachgeführt wird.\par
\medskip

\begin{figure} [H]
  \centering
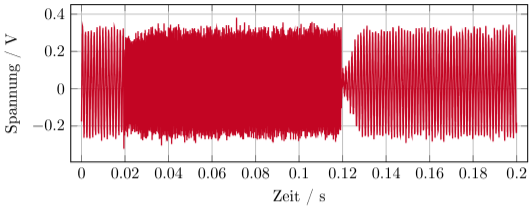
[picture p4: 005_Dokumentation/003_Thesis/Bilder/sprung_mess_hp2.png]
    
    \caption{HP}
    \label{fig:sprung_mess_hp}
\end{figure}

%\begin{figure} [H]
%  \centering
%    \includegraphics[width=0.9\linewidth]{../Bilder/sprung_mess_hp.png}
%    \caption{HP}
%    \label{fig:sprung_mess_hp}
%\end{figure}

Der Verlauf des Tiefpasses in Abbildung (Abb. \ref{fig:sprung_mess_tp}) verhält sich komplementär zum Hochpass. Der zu sehende Verlauf ist hierbei, abgesehen von der Einschwingzeit, sehr ähnlich zur Simulation. Durch den positiven Sprung erfährt die Amplitude eine starke Dämpfung. Beim negativen Sprung zeigt sich eine Amplitudenüberhöhung die ebenfalls an die in der Simulation zusehende Resonanzüberhöhung erinnert. \par
\medskip

\begin{figure} [H]
  \centering
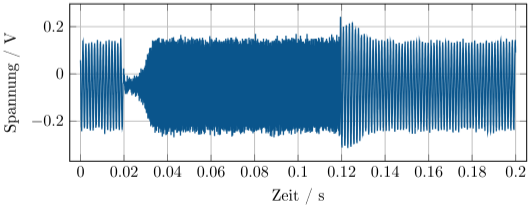
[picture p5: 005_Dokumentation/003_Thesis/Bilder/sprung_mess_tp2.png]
    
    \caption{TP}
    \label{fig:sprung_mess_tp}
\end{figure}

%\begin{figure} [H]
%  \centering
%    \includegraphics[width=0.9\linewidth]{../Bilder/sprung_mess_tp.png}
%    \caption{TP}
%    \label{fig:sprung_mess_tp}
%\end{figure}

Wie schon in der Simulation gesehen, erfährt der Bandpass (Abb. \ref{fig:sprung_mess_bp}) bei jedem Sprung einen kurzzeitigen Amplitudeneinbruch, da die Mittenfrequenz erst auf die neue Eingangsfrequenz einschwingen muss. Interessanterweise sind die Unterschiede in der Anpassungsgeschwindigkeit in der Realen Messung umgekehrt zu der in der Simulation prognostiziert. Der zweite, negative Sprung scheint in diesem Verlauf etwas schneller zu sein als der negative. Ein Zusammenhang kann dazu momentan nicht geschlossen werden aber vielleich hat das etwas mit dem kleinen Dent im HP Verlauf zutun\par
\medskip

\begin{figure} [H]
  \centering
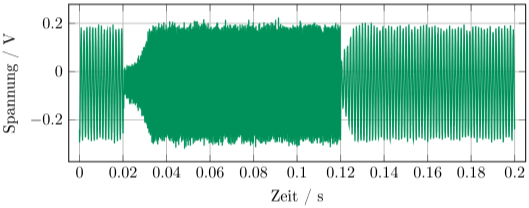
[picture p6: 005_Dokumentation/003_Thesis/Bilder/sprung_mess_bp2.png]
    
    \caption{BP}
    \label{fig:sprung_mess_bp}
\end{figure}

%\begin{figure} [H]
%  \centering
%    \includegraphics[width=0.9\linewidth]{../Bilder/sprung_mess_bp.png}
%    \caption{BP}
%    \label{fig:sprung_mess_bp}
%\end{figure}

Die Bandsperre in Abbildung \ref{fig:sprung_mess_bs} zeigt ein zum Bandpass komplementäres Verhalten. Bei Auftreten eines Sprungs wird die Amplitude des Signals erst stark erhöht und erst im Verlauf der Frequenzanpassung wieder gedämpft. Interessant ist hier der zweite Sprung bei dem die Amplitude nach dem einschwingen erst sehr klein wird, nur um im weiteren Einschwingverlauf wieder anzusteigen. (vielleich ist pendelt sich das system nicht auf den exakt richtigen wert ein sondern hat einen leichten offset zur eigendlichen Mittenfrequenz)\par
\medskip

\begin{figure} [H]
  \centering
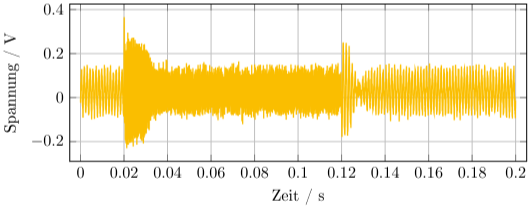
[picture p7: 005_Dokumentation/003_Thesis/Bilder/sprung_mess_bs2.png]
    
    \caption{BS}
    \label{fig:sprung_mess_bs}
\end{figure}

%\begin{figure} [H]
%  \centering
%    \includegraphics[width=0.9\linewidth]{../Bilder/sprung_mess_bs.png}
%    \caption{BS}
%    \label{fig:sprung_mess_bs}
%\end{figure}

Nach der Optimierung des Eingangsspannungslevels ähnlen alle Filterausgänge den Prognostizierten Verläufen sehr und die Signale sind sehr sauber. \par
\medskip

\subsection{Filterbereich des Gesamtsystems}
\label{sec:ausw_sprung}
\textbf{was zum sweep?}

Abschließend wird untersucht, innerhalb welcher Grenzen die Regelung des Gesamtsystems zuverlässig arbeitet und ab welchen Punkten das System versagt. Um den funktionierenden Frequenzbereich des Systems zu bestimmen, wird die Eingangsfrequenz über den Singalgenerator händisch verändert bis eine Grenze /Artefakte/ kappung der Steuerspannung zu erkennen sind. Die Ergebnisse sind in Tabelle \ref{tab:ausw_mess_grenz05} zusammengefasst. \par
\medskip

\begin{table}[h]
    \centering
    \begin{tabular}{c|c|c|c}
        \textbf{Eingang $f_{in}$ / \si{\hertz}} & \textbf{Messung $V_c$ / \si{\volt}} & \textbf{$f_0(V_c)$ / \si{\hertz}} & \textbf{Abweichung / \%} \\ \hline
        240 & 9.96 & 155 & -38  \\
        500 & 3.78 & 410 & -18 \\
        1000 & 1.9 & 816 & -18.4 \\
        2000 & 0.95 & 1637 & -18.2 \\
        5000 & 0.38 & 4101 & -18 \\
        7500 & 0.24 & 6596 & -12.1 \\
        10000 & 0.17 & 9338 & -6.6 \\
        12000 & 0.14 & 10765 & -10.3 \\
    \end{tabular}
    \caption{Optimierte Messreihe bei reduzierter Eingangsspannung $V_{in_{pp}}=\SI{0.5}{\volt}$}
    \label{tab:ausw_mess_grenz05}
\end{table}

Wie auch schon bei einer Eingangsspannung von $V_{in_{pp}}=\SI{2}{\volt}$ lässt sich auch an diesen Messwerten eine Konstante Abweichung von \SI{18}{\percent} zwischen \SI{500}{\hertz} und \SI{5000}{\hertz} beobachten. Im höheren Frequenzbereich wird die Abweichung geringer, verhält sich dabei aber nicht mehr so konsistent. Ausreißer bei dieser Messung ist die Aufnahme der Frequenz von \SI{240}{\hertz}, bei der eine Abweichung von \SI{-38}{\percent} festgestellt werden kann. \par
\medskip

Die Ursache für die massive Abweichung von \SI{-38}{\percent} am unteren Ende des Spektrums liegt in der Sättigung des Integrators im \gls{pd}. In der Abbildung \ref{fig:sprung_mess_uG} sind die Eingangsfrequenzen \SI{200}{\hertz} in rot und \SI{240}{\hertz} in blau gegenübergestellt. \par
\medskip

\begin{figure} [H]
  \centering
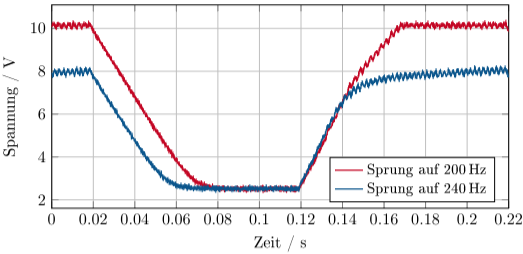
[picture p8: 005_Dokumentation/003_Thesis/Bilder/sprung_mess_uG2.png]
    
    \caption{Verhalten der Steuerspannung an der unteren Filtergrenze}
    \label{fig:sprung_mess_uG}
\end{figure}

%\begin{figure} [H]
%  \centering
%    \includegraphics[width=0.9\linewidth]{../Bilder/sprung_mess_uG.png}
%    \caption{Verhalten der Steuerspannung an der unteren Filtergrenze}
%    \label{fig:sprung_mess_uG}
%\end{figure}

Für die Bestimmung der unteren Frequenzgrenze des Systems wird beobachtet, ab welcher Frequenz die positiven Spitzen der AC-Komponente $V_p+$ die Sättigungsgrenze des Integrators erreichen. Bei einer Versorgungsspannung von \SI{\pm11}{\volt} wird die Spannung bei etwa \SI{10.44}{\volt} gekappt. Das ist gut im Verlauf der Steuerspannung für \SI{200}{\hertz} zu erkennen, bei dem der Verlauf mitten im Einschwingvorgang einen starken Knick erfährt. \par
\medskip

Bei der Betrachung der Spannungspegel für stationäre Eingangsfrequenzen stellt die in blau gezeigte Kennlinie mit \SI{240}{\hertz} die unterste einstellbare Frequenz da, bei der das Singal nicht durch die Sättigungsgrenze verfälscht wird. Für die in Abbildung \ref{fig:sprung_mess_uG} bedeutet das, dass die Steuerspannung für eine zeitlich längere obere Halbwelle noch eine weitere Steigung bis \SI{10}{\volt} erfahren sollte. Interessanter weise gilt dieser Grenzwert von \SI{240}{\hertz} sowohl für eine Eingangsspannung von $V_{in_{pp}}= \SI{2}{\volt}$ als auch für $V_{in_{pp}}= \SI{0.5}{\volt}$. \par
\medskip

Die obere Frequenzgrenze hingegen wird durch das Signal-Rausch-Verhältnis der Steuerspannung limitiert. Da das System nicht beliebig kleine Spannungswerte für $V_c$ verarbeiten kann, ist es von Vorteil die untere Grenze der AC-Schwingung soweit wie möglich zu reduzieren. Der geringste stabile Wert liegt in der Simulation bei etwa \SI{100}{\milli\volt} während es in der Messung mit ca. \SI{90}{\milli\volt} noch etwas weniger ist.\par
\medskip

Durch die Reduktion von $V_{in}$ auf \SI{0,5}{\volt} kann die obere Grenze erfolgreich auf über \SI{12}{\kilo\hertz} verschoben werden. In Abbildung \ref{fig:sprung_mess_oG} ist neben dem stabilen \SI{12}{\kilo\hertz}-Signal auch eine Eingangsfrequenz von \SI{13}{\kilo\hertz} dargestellt.\par
\medskip

\begin{figure} [H]
  \centering
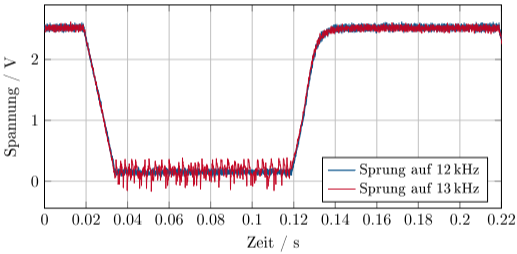
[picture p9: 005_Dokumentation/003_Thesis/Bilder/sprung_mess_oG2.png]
    
    \caption{Verhalten der Steuerspannung an der oberen Filtergrenze}
    \label{fig:sprung_mess_oG}
\end{figure}

%\begin{figure} [H]
%  \centering
%    \includegraphics[width=0.9\linewidth]{../Bilder/sprung_mess_oG.png}
%    \caption{Verhalten der Steuerspannung an der oberen Filtergrenze}
%    \label{fig:sprung_mess_oG}
%\end{figure}

Dabei ist deutlich zu erkennen, dass die Steuerspannung beim Versuch das System auf die höhere Frequenz zu regeln, anfängt wild umherzuspringen. Ab etwa \SI{12,3}{\kilo\hertz} treten massive Amplitudenüberhöhungen auf, die das Gesamtsystem instabil werden lassen. Zudem ist gut zu erkennen, dass sich das System beim Rücksprung auf die \SI{750}{\hertz} wieder fangen kann. \par
\medskip

\textbf{hier kann nochmal was zur einschwingschnelligkeit wie in der Sim geredet werden}

\section{Letzte Überlegungen für die auftretenden ungeklärten sachen}

Bei der Gesamtbetrachtung aller bisherigen Ergebnisse ist ein Muster zu erkennen, das eine gemeinsame Ursache für mehrere ungeklärte Phänomene liefert. In der Tabelle \ref{tab:ausw_mess_mfreq2} zeigte sich ein systematischer Offset der Steuerspannung zur Eingangsfrequenz, der bisher über unbekannte Einflussfaktoren erklärt wurde. Bei der genaueren Betrachtung der Ergebnisse fällt jedoch auf, dass Ungereimtheiten in der .ac-Analyse und bei den Frequenzsprungantworten der Bandsperre (BS) ein Verhalten aufweisen, das mit der gleichen Begründung erklärt werden kann. Das legt den Verdacht nahe, dass die Resonanzfrequenz des Systems nicht exakt auf die Eingangsfrequenz einstellt wird, sondern sich auf einen ungewollten negativen Offset regelt. \par
\medskip

Besonders deutlich wird dieses Verhalten am Bandsperr-Ausgang in Abbildung \ref{fig:sprung_mess_bs}, da dieser am empfindlichsten auf kleinste Frequenzänderungen reagiert. Beim negativen Frequenzsprung von \SI{3}{\kilo\hertz} auf \SI{750}{\hertz} verringert sich die Mittenfrequenz während des Einschwingvorgangs stark. Über den Einschwingverlauf wird dabei der Punkt passiert, an dem die Eingangsfrequenz exakt der Resonanzfrequenz entspricht. Dies entspricht dem Punkt der maximalen Dämpfung. In der Messung ist jedoch zu erkennen, dass die Amplitude nach diesem Minimum wieder leicht ansteigt, anstatt dort zu verbleiben. Das System regelt also ein kleines Stück über den optimalen Punkt hinaus. Ein einfaches Zurückschwingen der Regelung (positiver Offset) kann dabei ausgeschlossen werden, da beim positiven Frequenzsprung kein vergleichbares Dämpfungsartefakt auszumachen ist.\par
\medskip

Dieses Ergebnis lässt sich ebenso auf die .ac-Analyse in Abbildung \ref{fig:ac_final} übertragen. Zu Beginn der Messung startet der Filter mit einer hohen Resonanzfrequenz, während die Eingangsfrequenz noch sehr klein ist. Der Filter verringert daraufhin seine Resonanzfrequenz, bis sich beide Werte bei etwa \SI{200}{\hertz} annähern. Auch hier steuert die Regelung über den Punkt der maximalen Dämpfung hinaus, weshalb die Amplitude nach der starken Dämpfung wieder leicht ansteigt. Das kleine Artefakt, das kurz vor Erreichen der Stagnation im Plot zu sehen ist, könnte den Moment markieren, in dem der Filter versucht, der kontinuierlich steigenden Eingangsfrequenz des Sweeps wieder zu folgen. Da der Filter jedoch an seinem gewollten negativen Offset festhält, ändern sich Amplituden- und Phasenlage im weiteren Verlauf nicht mehr, was die beobachtete Stagnation erklärt.\par
\medskip

\section{Zusammenfassung}
Zusammenfassend lässt sich festhalten, dass das System trotz der festgestellten systematischen Offsets eine robuste und zuverlässige Funktionalität als Self-Tuned Filter aufweist. Die experimentelle Auswertung bestätigt, dass die Regelung über einen weiten Frequenzbereich von ca. \SI{240}{\hertz} bis über \SI{12}{\kilo\hertz} stabil arbeitet und die Mittenfrequenz der vier Filterausgänge präzise nachführt. Durch die gezielte Reduktion der Eingangsamplitude konnte die störende AC-Komponente auf der Steuerspannung um über \SI{80}{\percent} gesenkt werden, was die nutzbare Bandbreite des Filters signifikant vergrößert hat. Auch wenn das reale Einschwingverhalten deutlich schneller als in der Simulation prognostiziert abläuft und ein geringfügiger negativer Frequenz-Offset verbleibt, entsprechen die Filtercharakteristiken von Hoch-, Tief-, Bandpass und Bandsperre den theoretischen Erwartungen. Damit ist die grundsätzliche Funktionstüchtigkeit des entwickelten Gesamtsystems erfolgreich nachgewiesen.

\end{document}

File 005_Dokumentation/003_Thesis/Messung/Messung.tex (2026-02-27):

\documentclass[../main_config.tex]{subfiles}
\begin{document}

\chapter{Aufnahme der Messergebnisse}
Bevor die ersten Messungen am System gemacht werden können, muss diese ausreichend auf ihre Funktionsfähigkeit getestet werden. Aufgrund der langen Lieferzeit der bestellten Bauteile gab es im Vorfeld ausreichend Zeit ein kleines Testprotokoll zu erarbeiten.\par

\section{Funktionstest der Leiterplatte}
Nach Fertigstellung des \gls{pcb} wird zunächst der aufkommende Versorgungsstrom auf einen definierten Wert begrenzt. Anschließend wird kontrolliert, ob der Buck-Converter die \SI{3.3}{\volt} zuverlässig ausgibt. Sobald das funktioniert, kann die Ansteuerung der Digitalpotentiometer durch die \gls{mcu} programmiert werden. Mithilfe der zuvor geplanten Jumper kann der daraus resultierende Widerstandswert unabhängig von der Restschaltung gemessen und der Code dadurch validiert werden. \par
\medskip

Im nächsten Schritt könnten die fehlenden \glspl{ic} gesteckt werden um das Gesamtsystem zu vermessen. Da die Reaktion des Systems jedoch noch nicht genau bekannt ist, werden die Multiplizierer erst einmal überbrückt, um nur den bereits bekannten Biquad aufzunehmen. Der Phase-Detektor kann dabei vorerst vernachlässigt werden. Stimmen diese Ergebnisse mit den früheren Resultaten überein, kann anschließend das vollständige System vermessen werden. \par
\medskip

Auffällig ist, dass die \gls{mcu} bei anlegen der Versorgungsspannung nicht immer zuverlässig bootet. Ein möglicher Grund hierfür könnte eine nicht ausreichend stabilisierte Versorgungsspannung sein. Lösungsansätze sind zum Beispiel das Einsetzen eines Stützkondensators am $V_{sys}$-Eingang oder das Hinzufügen eines Schalters am \SI{3.3}{\volt}-Jumper. Sobald die \SI{\pm15}{\volt} erst einmal anliegen kann der Schalter gesetzt werden wonach die \gls{mcu} zuverlässig startet. Um auf Anhieb zu erkennen, dass der Pico ordnungsgemäß hochfährt, wird das Skript erweitert, sodass die Onboard-LED als Statusindikator fungiert.\par
\medskip

\subsection{Kompensation der Widerstandsabweichungen in den Digitalpotentiometern}

Bei der ersten Messung des herkömmlichen Biquads ohne Self-Tune-System zeigt sich eine deutliche Abweichung der Mittenfrequenz von der in der \gls{ui} eingestellten Frequenz. Dabei gibt es sowohl eine Diskrepanz zwischen dem theoretischen Sollwert \text{soll\_R} und dem durch den Wiper eingestellten Istwert \text{ist\_R}, als auch eine Abweichung zwischen dem Istwert und dem real abfallenden Widerstandswert. \par
\medskip

Die Abweichung zwischen dem Ist- und Sollwert ist recht einfach zu erklären. Das verwendete Potentiometer wird über ein \num{8}-Bit Steuerregister angesteuert, dass nur $2 ^8= 256$ diskrete Zustände annehmen kann. Diese Zustände sind gleichmäßig über den gesamten Widerstandsbereich verteilt, was zu einer konstanten Schrittweite führt. Die Gleichung\par
\medskip

\begin{equation}
    R_{step} = \frac{R_{max}-R_{min}}{2^{n}-1} = \frac{\SI{9980}{\ohm}-\SI{150}{\ohm}}{255} = \SI{38.5}{\ohm}
\end{equation}

beschreibt die Zusammensetzung der Schrittweite, wobei
\begin{itemize}
    \item $R_{max}$ den größt möglichen Widerstand darstellt,
    \item $R_{min}$ den kleinst möglichen Widerstand angibt.
\end{itemize}

Der Abstand zwischen zwei einstellbaren Widerstandswerten beträgt also $R_{step}=\SI{38}{\ohm}$. Bei der Umrechung eines gewünschten Widerstandswerts in einen \num{8}-Bit Wert, muss dieser auf den Bereich von \num{0} bis \num{255} normiert werden. Da der normierte Wert seltenst einer Ganzzahl entspricht, wird dieser im Skript anschließend noch gerundet. So addieren sich zur Abweichung durch die Schrittweite zusätzlich Rundungsfehler, die die Differenz zwischen Ist- und Sollwert erhöhen. \par
\medskip

%Dies beeinträchtigt stark die Differenz zwischen dem Idealwert und dem aus den Funktionen errechneten Wert. Wenn nun also ein bestimmter widerstandswert, zum Beispiel \SI{1}{\kilo\ohm}, eingestellt werden, muss dieser wert erst auf die \num{255} Steps normiert werden, die über den \gls{spi}-Bus übertragen werden können. Dabei kann es passieren, das der Wert nicht als Ganzzahl ausgegeben werden kann. Die zweite Fehlerquelle basiert also auf dem Ruden des Bitwerts für die Einstellung des Widerstandswerts. Diese addiert sich zu der ersten fehlerqelle.

Die Diskrepanz zwischen dem eingestellten Istwert und dem tatsächlich gemessenen Realwert ist nicht so einfach zu ermitteln. Darum wird im Folgenden kurz untersucht, ob die anfallenden Abweichungen durch Anpassungen im Skript kompensiert werden können. Dafür werden die Widerstände für den Ist- und Sollwert über das \gls{ui} ausgegeben. Gleichzeitig wird der Widerstand des Potentiometers \num{1} über ein Multimeter gemessen. Auf eine Messung der anderen Potentiometer wird hierbei verzichtet, da ihre Werte immer innerhalb von \SI{10}{\ohm} übereinstimmten. Die gemessenen Werte sind in der Tabelle \ref{tab:digipot_r_val} dokumentiert.

\begin{table}[h]
    \centering
    \begin{tabular}{c|c|c|c|c}
        \textbf{UI-Werte / \si{\hertz}} & \textbf{Ist-R / \si{\ohm}} & \textbf{Soll-R / \si{\ohm}} & \textbf{Real-R / \si{\ohm}} & \textbf{Differenz / \si{\ohm}} \\ \hline
        50 & 3178 & 3183 & 3244 & +61 \\
        100 & 1589 & 1591 & 1668 & +77 \\
        160 & 983 & 994 & 1067 & +73 \\
        200 & 794 & 795 & 877 & +82 \\
        300 & 529 & 530 & 611 & +81 \\
        500 & 302 & 318 & 387 & +69 \\
        750 & 227 & 212 & 310 & +98 \\
        1000 & 151 & 159 & 233 & +74 \\ 
    \end{tabular}
    \caption{Vergleich der Ist-, Soll- und Realwiderstandswerte für verschiedene Zielmittenfrequenzen}
    \label{tab:digipot_r_val}
\end{table}

Auffallend ist, dass die Differenz zwischen Real- und Sollwert immer positiv ist, was auf eine generelle Überschreitung des gewollten Werts hindeutet. Über diese Messreihe beträgt die durchschnittliche Abweichung \SI{78,2}{\ohm}. Bei Aufnahme der Widerstandswerte für $f_0 > \SI{1}{\kilo\hertz}$ zeigt sich zudem, dass der Realwiderstand des Digitalpotentiometers phyisch nicht unter ca. \SI{150}{\ohm} fallen kann. Daraus folgt, dass die Mittenfrequenz mit diesen Bauteilparametern \SI{1060}{\hertz} nicht überschreiten kann. \par
\medskip

Durch die zuvor berechnete minimale Schrittweite von \SI{38.5}{\ohm} lässt sich zudem ein weiterer interessanter Aspekt ableiten. Die minimal korrigierbare Abweichung beträgt \SI{19.25}{\ohm}. Abweichungen unterhalb dieses Fehlers können durch diese Potentiometer also nicht weiter kompensiert werden. Die durchschnittliche Differenz von Soll- und Realwert liegt mit \SI{78,2}{\ohm} deutlich höher, sodass diese durch eine Anpassung des Wiperwiderstands in Skript von \num{2} auf \num{4} Bit um $2 \cdot \SI{38.5}{\ohm} = \SI{77}{\ohm}$ verringert wird. Die Ergebnisse dieser Anpassung werden in Tabelle \ref{tab:digipot_r_val2} dokumentiert.\par
\medskip
%Die minimale Schrittweite begrenzt sich also auf \SI{38.5}{\ohm}, sodass eine Abweichung von unter \SI{19.25}{\ohm} über diesen Digitalpotentiometer nicht korrigiert werden kann. Sie ist jedoch ein vielfaches von der durchschnittlichen Abweichung wodurch der aktuelle Wiperwiderstand im Skript von \num{2} Bit auf \num{4} Bit angehoben werden kann. \par

\begin{table}[h]
    \centering
    \begin{tabular}{c|c|c|c|c}
        \textbf{\makecell{UI-Werte \\ / \si{\hertz}}} & \textbf{\makecell{Soll-R \\ / \si{\ohm}}} & \textbf{\makecell{Real-R (neu) \\ / \si{\ohm}}} & \textbf{\makecell{Differenz (neu) \\ / \si{\ohm}}} & \textbf{\makecell{Differenz (alt) \\ / \si{\ohm}}} \\ \hline
        50 & 3183 & 3064 & -115 & +61 \\
        100 & 1591 & 1566 & -25 & +77 \\
        160 & 994 & 971 & -23 & +73 \\
        200 & 795 & 784 & -11 & +82 \\
        300 & 530 & 532 & +2 & +81 \\
        500 & 318 & 298 & -20 & +69 \\
        750 & 212 & 221 & +9 & +98 \\
        1000 & 159 & 145 & -14 & +74 \\ 
    \end{tabular}
    \caption{Messwerte des Digitalpotentiometers nach Anpassung}
    \label{tab:digipot_r_val2}
\end{table}

Diese Anpassung führt zu einer deutlichen Annäherung von Soll- und Realwert. Die duchschnittliche Abweichung verbessert sich auf etwa \SI{27.4}{\ohm}. Die neuen Werte für die Differenz weisen dabei sowohl positive als auch negative Vorzeichen auf, weshalb eine erneute Anpassung des Wiperwiderstands die Abweichung nicht weiter reduziert. Die größte Abweichung tritt bei \SI{50}{\hertz} mit \SI{-115}{\ohm} Differenz auf, während die Differenzen für höhere Frequenzen deutlich kleiner werden.\par
\medskip

Diese Werte können natürlich durch eine Anpassung des Kondensatorwerts weiter erhöht werden. Zudem ändert sich die Zusammensetzung der Resonanzfrequenz für das Self-Tune-System erheblich, wodurch ebenfalls höhere Frequenzen beziehungsweise ein breiterer Frequenzbereich erreicht werden kann. \par
\medskip

\section{Messverfahren}

Im Folgenden wird die Vorgehensweise der verschiedenen Messungen am Self-Tuned Filter dokumentiert. Zunächst soll dabei mithilfe einer Bode-Analyse das allgemeine Übertragungsverhalten des Filters charakterisiert werden. Um ein tieferes Verständnis über den Einschwingvorgang des Systems zu gewinnen, wird im weiteren Verlauf zudem die Sprungantwort analysiert.\par
\medskip

Dieses Kapitel widmet sich primär dem Versuchsaufbau sowie den getroffenen Maßnahmen zur Verbesserung der Messgenauigkeit, während die detaillierten Ergebnisse in der abschließenden Auswertung besprochen werden.\par
\medskip

\subsection{Kleinsignalanalyse}
\label{sec:mess_ac}

Nach der Aktualisierung des Red Pitaya Betriebsystems auf die stabile Version 2.07-48 funkioniert die Messwertaufnahme mit der eingesteckten \gls{mcu} schließlich. Die Charakterisierung des Systems erfolgt über einen Frequenzsweep (Bode-Analyse), um den Amplituden- und Phasengang mit einem herkömmlichen Biquad-Filter zu vergleichen. Der interne Funktionsgenerator des Red Pitaya steuert das \gls{dut}, einen der Filter des Biquads, mit einem vorgegebenen Eingangssignal an. Dabei wird der Eingang 1 (IN1) des Red Pitaya zusammen mit Ausgang 1 (OUT1) des Generators an den Eingang des \gls{dut} angeschlossen, während Eingang 2 (IN2) das Ausgangssignal erfassen soll. Die gemeinsame Masseverbindung zwischen Red Pitaya und \gls{dut} sorgt für eine stabile Messumgebung.\par
\medskip

\begin{figure} [H]
    \centering
    \begin{tikzpicture}[
    node distance=2cm,
    box/.style={draw, minimum width=2.5cm, minimum height=2cm, thick},
    port/.style={draw, rounded corners=2pt, minimum width=0.8cm, inner sep=2pt, font=\small\sffamily},
    line/.style={thick}
]

%red pitaya
\node[box, minimum width=3cm, minimum height=5.5cm] (RP) {Red Pitaya};
\node[port, left=0cm of RP.north west,  yshift=-0.5cm] (IN1) {IN1};
\node[port, left=0cm of RP.west,  yshift=0.8cm] (IN2) {IN2};
\node[port, left=0cm of RP.west,  yshift=-0.8cm] (OUT1) {OUT1};
\node[port, left=0cm of RP.south west,  yshift=0.5cm] (OUT2) {OUT2};

%dut
\node[box, left=4cm of RP] (DUT) {DUT};
\node[port, left=0cm of DUT.west] (DUT_IN) {IN};
\node[port, right=0cm of DUT.east] (DUT_OUT) {OUT};
\node[port, below=0cm of DUT.south] (DUT_GND) {GND};

%linien
\draw[line, yellow!80!orange] (DUT_IN.west) -- ++(-0.4,0) |- (IN1.west);

\draw[line, orange!80!black] (DUT_OUT.east) -- ++(0.5,0) |- (IN2.west);

\draw[line, red!80!black] (OUT1.west) -- ++(-0.6,0) -- ++(0,-1.7) -| ([xshift=-0.4cm]DUT_IN.west) -- (DUT_IN.west);

\draw[line] (DUT_GND.south) -- ++(0,-1.3) -| ([xshift=-0.4cm]OUT1.south west) -- (OUT1.south west);

\draw[line] (DUT_GND.south) -- ++(0,-0.8) -| ([xshift=-1.2cm]IN1.south west) -- (IN1.south west);

    \end{tikzpicture}
    \caption{Messaufbau zur Charakterisierung des DUT mit dem Red Pitaya \cite{LabANS}}
    \label{fig:messaufbau}
\end{figure}

Vor Beginn der Messung sollte der Red Pitaya kalibriert werden, indem Ein- und Ausgang des \gls{dut} überbrückt werden, um eventuelle Offset-Fehler zu kompensieren. Interessanterweise zeigte sich in den Versuchen jedoch, dass die Messergebnisse nach dieser Kalibrierung inkonsistent waren, während die Aufnahmen ohne vorherige Kalibrierung  besser dem erwarteten Verlauf entsprachen. Da dieses Problem kurzfristig nicht gelöst werden konnte, wurde das Betriebssystem des Red Pitaya neu aufgesetzt und die weiteren Messungen an einem unkalibrierten System durchgeführt.\par
\medskip

Zudem fiel bei den ersten Messungen auf, dass die Messung bei der Verwendung von drei herkömmlichen Oszilloskop-Tastköpfen fehlschlug. Bei genauerer Beobachtung zeigte sich, dass ein im Red Pitaya eingestellter Sinus auf der Platine nicht zu sehen ist. Die Verwendung eines Kabels zwischen dem  Red Pitaya und dem \gls{dut} löst dieses Problem. \par
\medskip

Anschließend wird ein Frequenzsweep über den relevanten Frequenzbereich durchgeführt. Dabei verändert der Funktionsgenerator die Frequenz des Eingangssignals schrittweise, während gleichzeitig Amplitudenverhältnis (in dB) und Phasenverschiebung (in Grad) zwischen Ein- und Ausgangssignal aufgenommen werden. Die Ergebnisse werden als Bode-Diagramm dargestellt, das sowohl den Amplitudengang als auch den Phasengang des Filters abbildet.\par
\medskip

Über diese Analyse soll zudem auch festgestellt werden, welche der beiden Gleichungen für die Mittenfrequenz die korrekte ist. \par
\medskip

\subsection*{Erste Messungen am Gesamtsystem}
Bei der ersten Aufnahme des Gesamtsystems treten mehrere unerwartete Phänomene auf. Trotz mehrfacher Überprüfung der Widerstandswerte der Digitalpotentiometer und aller relevanten Spannungen verhält sich das System nicht wie erwartet. Obwohl die Filterparameter konstant gehalten werden zeigen die Ergebnisse der Bode-Analyse starke Inkonsistenzen. So schwankt die Mittenfrequenz $\omega_0$ am Bandsperrausgang über mehrere Messreihen hinweg stark und zeigt eine steigende Tendenz (von ca. 430 Hz bis hin zu 1519 Hz).(Die Bandsperre wird hier hauptsächlich verwendet um die Mittenfrequenz leichter beobachten zu können)\par
\medskip

\begin{figure} [H]
  \centering
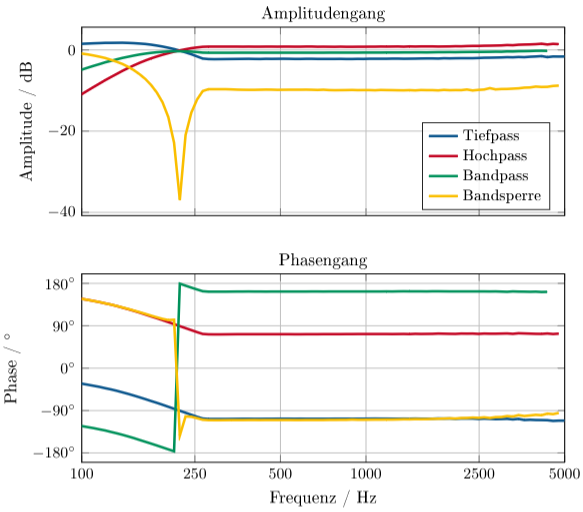
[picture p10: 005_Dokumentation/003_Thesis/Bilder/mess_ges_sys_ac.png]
    
    \caption{Amplituden und Phasenverläufe der Filter im Gesamtsystem}
    \label{fig:ges_sys_out_ac}
\end{figure}

%\begin{figure} [H]
%  \centering
%    \includegraphics[width=0.8\linewidth]{../Bilder/Messung_ges_sys_ac.png}
%    \caption{Amplituden und Phasenverläufe der Filter im Gesamtsystem}
%    \label{fig:ges_sys_out_ac}
%\end{figure}

Zusätzlich weichen die Frequenzverläufe von den charakterischtischen Verläufen ab. Der Amplitudenverlauf der Bandsperre zeigt im zweiten Durchlassbereich eine Dämpfung von etwa 8 bis \SI{10}{\decibel}. Der Phasenverlauf zeigt zudem kurz vor dem Sprung an der Mittenfrequenz eine starke Erhöhung anstatt wie in der Simulation weiter zu fallen. Am Bandpass tritt im höheren Frequenzbereich keine Dämpfung mehr auf und verhält sich entsprechend eines Hochpasses. Die Flankensteilheit am Tiefpass ist deutlich zu gering, sodass dieser eher einem Allpass entspricht.\par
\medskip

Zusammenfassend lässt sich feststellen, dass dem System die notwendige Dämpfung im höheren Frequenzbereich fehlt, wobei lediglich der Hochpass (HP) einen korrekten Verlauf beibehält.\par
\medskip

\textbf{Hypothese: diese Messmethode kann nicht mit einem solchen system gemessen werden. es sieht etwas so aus, als ob der Filter versucht hinter der eingehenden frequenz herzukommen nach erreichen der Resonanzfrequenz}\par
\medskip

Um die Ursache für die Inkonsistenzen einzugrenzen, soll der \gls{vcf} ohne Einfluss durch den Phasendetektor betrachtet werden. Durch das Entfernen von $R_{10}$ wird der Regelkreis von der Phasendetektion getrennt. Die Steuerspannung $V_c$ wird auf ein definiertes Potential von \SI{1}{\volt} gesetzt. \par
\medskip

\begin{figure} [H]
  \centering
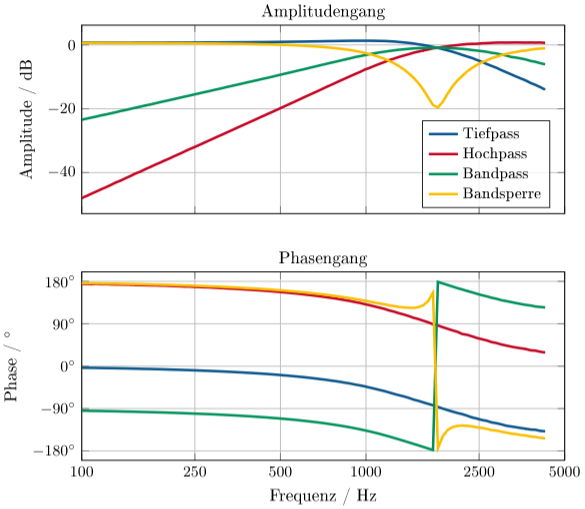
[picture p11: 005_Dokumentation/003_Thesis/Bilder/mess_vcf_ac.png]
    
    \caption{Amplituden und Phasenverläufe der Filter des VCF}
    \label{fig:vcf_out_ac}
\end{figure}

%\begin{figure} [H]
%  \centering
%    \includegraphics[width=0.8\linewidth]{../Bilder/Messung_vcf_ac.png}
%    \caption{Amplituden und Phasenverläufe der Filter des VCF}
%    \label{fig:vcf_out_ac}
%\end{figure}

Auf den ersten Blick scheinen die Verläufe der Ausgänge korrekt zu sein, sodass mit der tieferen Analyse der Mittenfrequenz begonnen werden kann.\par
\medskip

\subsection*{Experimentelle Verifizierung der Mittenfrequenzgleichung}
\label{sec:veri_omega0}
Für den herkömmlichen Biquad ligt die Mittenfrequenz für $R= \SI{1}{\kilo\ohm}$ und $C= \SI{1}{\micro\farad}$ bei etwa \SI{160}{\hertz}. Bei gleichen Parametern liegt $f_0$ für den \gls{vcf} deutlich höher. Das liegt daran, dass mit der Veränderung des Schaltungsaufbaus auch die Zusammensetzung der Mittenfrequenz beeinflusst wird. Die Mittenfrequenz des herkömmlchen Biquads ist als $\omega_0 = \frac{1}{RC}$ (Gleichung \ref{eq:w_0}) definiert, während für den \gls{vcf}-Aufbau die Referenzspannung $V_r$ und Steuerspannung $V_c$ berücksichtigt werden müssen. \par
\medskip

Die in Kapitel \ref{sec:theorie_w0} hergeleiteten Mittenfrequenzen werden hier im Folgenden nocheinmal betrachtet, um zu verifizieren welche korrekt ist. Die Gleichung \par
\medskip

\begin{equation}
    \omega_0 = \frac{V_r}{V_cRC}
    \tag{\ref{eq:filtergrenzfrequenz}}
\end{equation}

wurde dabei eigenständig hergeleitet, während die Gleichung 

\begin{equation}
    \omega_0 = \frac{V_c}{V_r \cdot RC} 
    \tag{\ref{eq:freq-vcf}}
\end{equation}

aus dem ASLK-PRO Manual stammt. Wie schon zuvor erwähnt unterscheiden sich diese beiden Gleichungen nur in dem hinzugefügten Faktor aus Referenzspannung $V_r$ und Steuerspannung $V_c$. Bei Messung dieser Signale fällt auf, dass das Potential für $V_r$ bei einer Versorgungsspannung von \SI{\pm15}{\volt} auf \SI{-13.73}{\volt} liegt und nicht wie im Datenblatt angegeben auf \SI{-10}{\volt} lasergetrimmt ist. Bei Änderung der negativen Versorgungsspannung ist zudem zu erkennen, dass $V_r$ immer etwa \SI{1.27}{\volt} unter dieser liegt. Aus diesem Grund wird die Versorgungsspannung von \SI{\pm15}{\volt} zeitweise auf \SI{\pm11}{\volt} reduziert, um mit \SI{-9.73}{\volt} deutlich näher an den angegebenen \SI{-10}{\volt} zu liegen. In der zweiten Iteration des \gls{pcb} soll der SF Pin über einen Trimmer angepasst werden können, die erste Iteration bietet diese Funktion noch nicht.\par
\medskip  

%Bei Annahme von $V_c=\SI{1}{\volt}$ und $V_r=\SI{9.73}{\volt}$ können nun die Modelle auf Richtigkeit getestet werden. 

Für die Vermessung des \gls{vcf} werden die Filterparameter wie gewohnt gewählt. Die Widerstände liegen bei etwa \SI{1}{\kilo\ohm}, die Steuerspannung $V_c$ wird auf \SI{1}{\volt} und die Referenzspannung $V_r$ auf \SI{9.73}{\volt} eingestellt. Die visuelle Auswertung der Filterverläufe zeigt zunächst einen korrekten Verlauf, weshalb die frequenzbestimmenden Widerstände im nächsten Schritt über den gesamten Filterbereich variiert werden. Die Mittenfrequenz wird dabei über den Nulldurchgang der Phase im Bandsperrenausgang ermittelt. Die Ergebnisse sind in Tabelle \ref{tab:mittenfrequenzen} zusammengefasst.\par
\medskip

\begin{table}[h]
    \centering
    \begin{tabular}{c|c|c|c}
        \textbf{Soll-R / \si{\ohm}} & \textbf{Messung: $\omega_0$ / \si{\hertz}} & \textbf{Theorie: $\omega_0$ / \si{\hertz}} & \textbf{Abweichung / \%} \\ \hline
        1591 & 1116.22 & 973.34 & 12.8 \\
        994 & 1776.34 & 1557.93 & 12.3 \\
        796 & 2140.18 & 1945.45 & 9.1 \\
        531 & 3253.12 & 2916.34 & 10.35 \\
        318 & 5789.74 & 4869.74 & 15.89 \\
        212 & 7653.34 & 7304.61 & 4.56 \\
        159 & 11570.81 & 9739.48 & 15.83 \\
    \end{tabular}
    \caption{Mittenfrequenzen und Abweichungen mit Elektrolytkondensatoren}
    \label{tab:mittenfrequenzen}
\end{table}

Die theoretischen Werte basieren auf der eigenständig hergeleiteten Gleichung \ref{eq:filtergrenzfrequenz}. Es zeigt sich, dass das System zwar grob der theoretischen Gleichung folgt. Die Abweichungen sind mit bis zu \SI{15.89}{\percent} jedoch noch sehr hoch. Um diese Abweichungen zu kompensieren, wird die Berechnungsfunktion für die theoretische Mittenfrequenz in Python an die gemessenen Werte angepasst. Durch die Multiplikation der Widerstandswerte mit einem Faktor von \num{0.9} lässt sich die Abweichung für die gemessenen Werte auf \SI{\pm7.5}{\percent} reduzieren, statt der ursprünglichen \SI{\pm15.89}{\percent}.\par
\medskip

Um die Ursache für diese starken Abweichungen zu verstehen, wird die Schaltung nochmals detailliert betrachtet. Dabei fällt auf, dass die verbauten Elektrolytkondensatoren eine Toleranz von bis zu \SI{20}{\percent} aufweisen. Obwohl die Bauteiltoleranzen in einem Self-Tuned Filter theoretisch nur eine untergeordnete  Rolle spielen sollten, ist es für präzise Messungen an Teilsystemen wie dem \gls{vcf} vorteilhaft, geringere Toleranzen zu haben. Aus diesem Grund werden die Elektrolytkondensatoren gegen Folienkondensatoren ausgetauscht, die eine Toleranz von nur \SI{5}{\percent} aufweisen.\par
\medskip

\begin{table}[h]
    \centering
    \begin{tabular}{c|c|c|c}
        \textbf{Soll-R / \si{\ohm}} & \textbf{Messung: $\omega_0$ / \si{\hertz}} & \textbf{Theorie: $\omega_0$ / \si{\hertz}} & \textbf{Abweichung / \%} \\ \hline
        1591 & 1038.04 & 973.34 & 6.23 \\
        994 & 1656.58 & 1557.93 & 5.95 \\
        796 & 1993.77 & 1945.45 & 2.42 \\
        531 & 2960.54 & 2916.34 & 1.49 \\
        318 & 5327.21 & 4869.74 & 8.59 \\
        212 & 6863.27 & 7304.61 & -6.43 \\
        159 & 9930.13 & 9739.48 & 1.92 \\
    \end{tabular}
    \caption{Mittenfrequenzen und Abweichungen mit Folienkondensatoren}
    \label{tab:mittenfrequenzen2}
\end{table}

Wie in Tabelle \ref{tab:mittenfrequenzen2} dargestellt verbessert sich die Abweichung zwischen den Theorie- und Praxiswerten nach Austausch der Kondensatoren deutlich. Für die betrachteten Datenpunkte reduziert sich die maximale Abweichung auf unter \SI{8.6}{\percent}, was fast einer Halbierung der vorherigen maximalen Abweichung entspricht. Die verbleibende Abweichung lässt sich nicht einfach durch Skalierung eines Filterparameters verringern, da die größte negative Abweichung bei \SI{-6.43}{\percent} liegt. So wird diese auf die Bauteiltoleranzen, besonders die Digitalpotentiometer zurückzuführen sein. \par
\medskip

\textbf{vielleich ist es besser diesen teil vor den anderen zu packen. in dem davor wird ja schon von der selbst hergeleiteten gleicung ausgegangen}

Zuletzt sollen nun noch die gegensätzlichen Mittenfrequenzgleichung überprüft werden. Für die Steuerspannung wird dabei ein Wert von $V_c = \SI{1}{\volt}$ eingesetzt, die Referenzspannung beträgt $V_r = \SI{9.73}{\volt}$. Werden diese Werte nun in die beiden Gleichungen eingesetzt ergibt sich folgendes Bild:\par
\medskip

\begin{equation}
    f_0 = \frac{V_r}{V_c \cdot 2\pi RC} = \frac{\SI{9.73}{\volt}}{\SI{1}{\volt} \cdot 2\pi \cdot \SI{994}{\ohm} \cdot \SI{1}{\micro\farad}} = \SI{1557.93}{\hertz}
\end{equation}

\begin{equation}
    f_{0\_ASLK} =  \frac{V_c}{V_r \cdot 2\pi RC} = \frac{\SI{1}{\volt}}{\SI{9.73}{\volt} \cdot 2\pi \cdot \SI{994}{\ohm} \cdot \SI{1}{\micro\farad}} = \SI{16.46}{\hertz}
\end{equation}

Während die Gleichung aus dem ASLK-PRO Manual eine Mittenfrequenz von nur \SI{16.46}{\hertz} vorhersagt, liefert die eigenständig hergeleitete Gleichung einen Wert von \SI{1557.93}{\hertz}, der besser mit dem gemessenen Wert von \SI{1657}{\hertz} übereinstimmt.\par
\medskip

Um die Abhängigkeit der Mittenfrequenz von der Steuerspannung endgültig zu bestätigen, wird $V_c$ im Experiment von \SI{1}{\volt} auf \SI{2}{\volt} erhöht. Nach der Rechenvorschrift \ref{eq:filtergrenzfrequenz} sollte sich die Mittenfrequenz dadurch halbieren. Die Ergebnisse sind in Tabelle \ref{tab:mittenfrequenzen3} zusammengefasst:\par
\medskip

\begin{table}[h]
    \centering
    \begin{tabular}{c|c|c|c}
        \textbf{$V_c$ / \si{\volt}} & \textbf{Theorie: $\omega_0$ / \si{\hertz}} & \textbf{Messung: $\omega_0$ / \si{\hertz}} & \textbf{Abweichung / \%} \\ \hline
        1 & 1557.93 & 1656.58 & 5.95 \\
        2 & 778.96 & 824.39 & 5.51\\
    \end{tabular}
    \caption{Vergleich der Mittenfrequenz bei Variation von $V_c$}
    \label{tab:mittenfrequenzen3}
\end{table}

Dadurch kann bestätigt werden, dass die eigenständig hergeleitete Gleichung \ref{eq:filtergrenzfrequenz} die Mittenfrequenz für diesen \gls{vcf} korrekt beschreibt. Die Abweichungen zwischen Theorie und Messung liegen im akzeptablen Bereich und sind vermutlich auf die Toleranzen der verwendeten Bauteile zurückzuführen.\par
\medskip

(\textbf{Überleitung zu den ergebnissen aus der Sim}
Auch die Simulation des Filters in LTspice kommt auf eine andere Mittenfrequenz. diese liegt bei etwa \SI{1.76}{\kilo\hertz}. dabei sind alle schaltungsteile gleich, nur die Versorgungs und Hilfsspannungen müssen nochmals überprüft werden. \textbf{überarbeiten})\par
\medskip

\subsection*{Charakterisierung des Phasendetektors}
Nach der Vermessung des spannungsgesteuerten Filters folgt nun die Einzelbetrachtung des Phasendetektors. Dabei werden wie schon in Kapitel \ref{sec:theorie_pd} zwei Signale auf die Eingänge des \gls{pd} gegeben. Das Referenzsignal mit \SI{1000}{\hertz} und ein Messsignal mit \SI{1100}{\hertz}. Am Ausgang des Multiplizierers ergibt sich das in Abbildung \ref{fig:mult_out_osc} dargestellte Signal.\par
\medskip

\begin{figure} [H]
  \centering
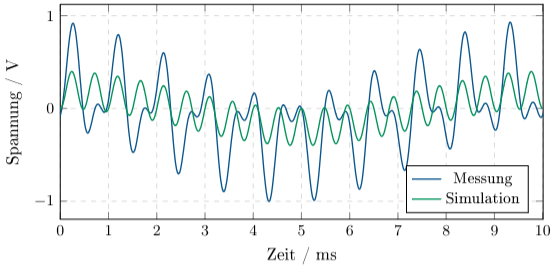
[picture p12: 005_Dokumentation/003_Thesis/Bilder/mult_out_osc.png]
    
    \caption{Ausgangssignal des Mulitplizierers im Phasendetektor}
    \label{fig:mult_out_osc}
\end{figure}

%\begin{figure} [H]
%  \centering
%    \includegraphics[width=0.8\linewidth]{../Bilder/mult_out_osc2.png}
%    \caption{Ausgangssignal des Mulitplizierers im Phasendetektor}
%    \label{fig:mult_out_osc}
%\end{figure}

Zu Beginn haben die Eingangssignale eine Phasendrehung von \SI{0}{\degree} zu einander. Wie schon in der Simulation betrachtet weist das Ausgangssignal dabei einen positiven Offset auf, der jedoch mit zunehmender Phasendifferenz stetig kleiner wird. Bei einer Verschiebung von etwa \SI{90}{\degree} geht der Offset in den negativen Bereich über. \par
\medskip

Die hochfrequente Welligkeit (Ripple) des realen Signals ist hingegen ungleichmäßiger als im idealisierten Modell. Dies lässt sich auf Nichtlinearitäten des analogen Multiplizierers zurückführen, die neben der Summenfrequenz und der Differenzfrequenz (\SI{100}{\hertz}) zusätzliche Oberschwingungen generieren. Da für die Funktion des Phasendetektors vor allem der niederfrequente Anteil relevant ist, werden diese höherfrequenten Störungen durch das Tiefpassverhalten des nachfolgenden Integrators gedämpft. Des Weiteren ist die Amplitude des Messsignals deutlich höher als in der Simulation, was auf die unterschiedlichen Eingangsamplituden (\SI{5}{\volt_{pp}} in der Messung gegenüber \SI{4}{\volt_{pp}} in der Simulation) zurückzuführen ist. \par 
\medskip

Im Allgemeinen zeigt der zeitliche Verlauf der Steuerspanung $V_c$ eine hohe Übereinstimmung zwischen Messung und Simulation.\par
\medskip

\begin{figure} [H]
  \centering
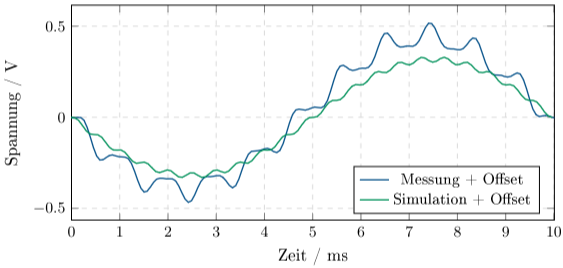
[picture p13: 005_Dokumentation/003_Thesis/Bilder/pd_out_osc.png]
    
    \caption{Ausgangssignal des Phasendetektors (AC-Betrachtung)}
    \label{fig:pd_out_osc}
\end{figure}

%\begin{figure} [H]
%  \centering
%    \includegraphics[width=0.8\linewidth]{../Bilder/pd_out_osc2.png}
%    \caption{Ausgangssignal des Phasendetektors (AC-Betrachtung)}
%    \label{fig:pd_out_osc}
%\end{figure}

Der allgemeine Vergleich der Signalverläufe nach dem Integrator zeigt eine hohe Übereinstimmung zwischen Simulation und Messung. Die restliche Welligkeit ist auf die zuvor beschriebene unsaubere Multiplikation zurückzuführen. Der signifikanteste Unterschied zwischen den beiden Signalen liegt im DC-Offset. Das Simulationssignal besitzt einen Gleichanteil von \SI{2.528}{\volt}, während die Messung mit \SI{13.68}{\volt} DC belegt ist. \textbf{Dieser Versatz ist mit  xxx zu erklären. warum?}. Zudem ist eine geringe Phasenverschiebung zwischen den Funktionen erkennbar.\par
\medskip

Trotz dieser Abweichungen ist die grundlegende Funktionalität des Phasendetektors gegeben, da die Signalform dem Idealverlauf entspricht. Somit ist belegt, dass beide Teilschaltungen, der spannungsgesteuerte Filter sowie der Phasendetektor, einzeln betrachtet funktionstüchtig sind. Im Folgenden kann daher das Gesamtsystem untersucht werden. \par
\medskip

\subsection{Sprungantwort des Self-Tuned Filters}
Die in der Simulation analysierte Frequenz-Sprungantwort soll nun durch eine experimentelle Messung am realen System widerholt werden. Dabei soll das Signal am Eingang des \gls{dut} schnell zwischen zwei Frequenzen wechseln, um die Reaktion des Systems auf diesen plötzlichen Frequenzwechsel zu beobachten. \par
\medskip

Dazu wird das \gls{dut} mit einem Signalgenerator angesteuert, der über die \gls{fsk}-Modulation einen automatischen Frequenzwechsel ausgibt. Bei dieser Modulationsart werden eine Grundfrequenz und eine Carrierfrequenz festgelegt, zwischen denen Ausgangssignal des Generators in einem vorgegebenen Takt umschaltet.\par
\medskip

Da der genaue Stabilitätsbereich für die Frequenzsprünge am realen System unbekannt ist, gibt der Signalgenerator anfangs die Frequenzen \SI{750}{\hertz} und \SI{3}{\kilo\hertz} aus. Die nach der Einschwingphase gemessenen Potentiale der Steuerspannung $V_c$ und die daraus resultiertende Resonanzfrequenz $f_0$ liegen bei \SI{620}{\hertz} und \SI{2770}{\hertz}. Trotz dieser Abweichung folgt das System der eingehenden Frequenz. Eine detaillierte Analyse dieser Ergebnisse erfolgt in Kapitel \ref{sec:ausw_sprung}.\par
\medskip

Bei der Messung der Sprungantwort fällt zudem auf, dass je nach Taktrate des Frequenzwechsels Atefakte entstehen. Dabei übersteuert die Amplitude des Filterausgangssignals stark, sodass statt einer Spitzenspannung von $V_p= \SI{1}{\volt}$ Werte von \SI{9.5}{\volt} erreicht werden. Dieses Verhalten tritt immer beim Sprung von der niedrigen auf die hohe Frequenz auf, wobei die Amplitude entweder nach kurzer Zeit wieder auf den Normalwert fällt oder sich über mehrere Perioden streckt. Das Fallen auf den Normalwert erfolgt dabei ebenso aprupt wie das Auftreten der Überhöhung. Bei geringer Taktfrequenz (\SI{1}{\hertz}) treten diese Überhöhungen kaum auf. Wird der Takt jedoch auf beispielsweise \SI{10}{\hertz} erhöht, können auch die Amplitudenübersteuerungen häufiger beobachtet werden.\par
\medskip

\begin{figure} [H]
  \centering
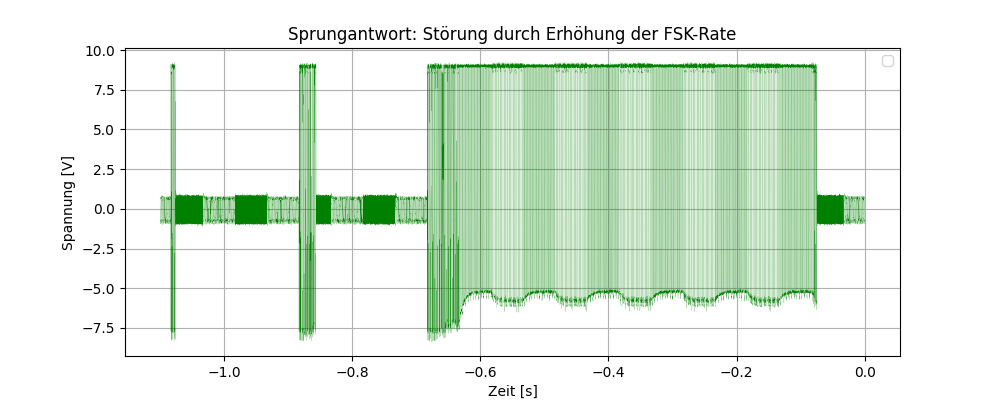
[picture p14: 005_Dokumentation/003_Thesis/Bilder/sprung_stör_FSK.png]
    
    \caption{Bild der Störung}
    \label{fig:sprung_mess_FSK}
\end{figure}

Um die Ursache für die Amplitudenübersteuerungen besser einzugrenzen, wird die Platine mittels Druckluft heruntergekühlt. Damit soll eine Temperaturabhängigkeit, wie beispielsweise die Überhitzung einzelner Bauteile, ausgeschlossen werden. Das Abkühlen zeigte anfangs einen positiven Effekt auf die Häufigkeit der Artefakte, jedoch konnte dies bei wiederholter Kühlung nicht reproduziert werden. \par
\medskip

Um zudem die \glspl{opv} als Fehlerquelle ausschließen zu können, wurden die ursprünglichen TL082B gegen pinkompatible LM358 ausgetauscht. Diese besitzen eine geringere Slew-Rate sowie ein kleineres \gls{gbw}, reagieren also langsamer als der TL082. In der Messung stieg die Fehlerrate durch den Austausch der \glspl{opv} noch weiter an. \textbf{Es fehlt noch ein kurzer Grund für die Maßnahme. Evtl. in Richtung um das Verhalten anderer Vergleichbarer OPVs zu testen. Ob das BAuteil oder das System die Schwingungen erzeugt.  }\par
\medskip

Für einen weiteren Test mit einem AD8062 wurde die Versorgungsspannung der Platine auf \SI{\pm8}{\volt} gesenkt, um die Grenzwerte des Bauteils einzuhalten. Leider liefert auch diese Messung keine konsitstenten Ergebnisse. Dabei zeigte sich, dass der \gls{opv} das Ausgangssignal stark zum schwingen bringt. Eine mögliche Ursache dafür ist, dass die Schaltung nicht für einen so schnellen \gls{opv} ausgelegt ist.\par
\medskip 

Die auf die tatsächliche Ursache wird ausführlich in der Auswertung eingegangen.\par
\medskip

\subsection{Einschwingbereich des Filters}

Trotz der geringen Aussagekraft der Simultationsergebnisse soll zur Vervollständigung auch das reale System über einen Frequenzsweep vermessen werden. Dafür wird der Signalgenerator im entsprechenden Betriebsmodus verwendet, wobei nur die Start- und Stoppfrquenz sowie die Dauer des Sweeps angegeben werden müssen. Das Ergebnis kann dann über das Oszilloskop mit einer entsprechned eingestellten Sample Time aufgenommen werden.\par
\medskip

Zusätzlich wird der Einschwingbereich über den Aufbau für die Sprungantwort vermessen. Durch die schrittweise Erhöhung beziehungsweise Verringerung der Eingangsfrequenz kann so die Frequenz ermittelt werden bei der sich das System nicht mehr selbständig einfangen kann. \par
\medskip

%Aufnahme über spektrum analysator? Herausfinden wie groß der Filter/ Einstellungsbereich des Filters ist. Also bis zu welcher abweichung von eingehender Freq und bauteilbedingter Mittenfreq. der filter noch die win=w0 schafft. 

\end{document}

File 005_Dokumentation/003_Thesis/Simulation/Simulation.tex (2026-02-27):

\documentclass[../main_config.tex]{subfiles}
\begin{document}

\chapter{Simulation}

Nachdem die einzelnen Teilsysteme im vorangegangenen Kapitel isoliert betrachtet wurden, widmet sich dieses Kapitel der Gesamtsimulation des Filters. Dabei soll das Zusammenspiel der Komponenten genauer untersucht und das idealisierte Verhalten des Systems ohne Bauteiltoleranzen, parasitäre Effekte oder Messungenauigkeiten nachvollzogen werden. So soll eine Referenz für die physikalische Umsetzung des Filters geschaffen werden.\par
\medskip

Beim Aufbau der Teil- und Gesamtsimulation stellte die Implementierung eines Simulationsmodells für den Analog-Multiplizierer das größte Hindernis da. Die Simulation sollte in der Spice-Simulationsumgebung von KiCad erfolgen, weshalb eine kompatible Simulationsdatei gefunden werden musste. Der Hersteller des Multiplizierers Texas Instruments stellt die Simulationsdatei allerdings nur für die eigene Simulationssoftware Tina TI bereit, sodass aus der ursprünglichen \text{.tsc}-Datei die für die Simulation wichtigen Funktionen herausgesucht und in einer \text{.lib}-Datei abgespeichert werden müssen. Bei der Übersetzung wird zudem darauf geachtet, dass nur Spice kompatible Befehlssätze verwendet werden. Anschließend kann die \text{.lib}-Datei mit dem Schaltsymbol des Multiplizierers verknüpft werden. \cite{sim_modell_multi}\par
\medskip

Nach der Implementierung dieser in KiCad zeigte die erste Transientanalyse (\text{.tran}) konstante Ergebnisse, während bei der Kleinsignalanalyse (\text{.ac}) aufgrund von Konvergenzproblemen in der Ngspice-Umgebung keine validen Werte ausgegeben werden konnten.
Da für die Betrachtung der Teilschaltungen nur die Transientanalyse verwendet wurde, konnten alle Simulationen aus dem letzten Kapitel in KiCad durchgeführt werden. \par
\medskip

Dabei zeigt sich, dass die Verschaltung des Multiplizierers in KiCad etwas anders verläuft als in der Realität. Laut Datenblatt kann der SF-Pin des Multiplizierers offen gelassen werden, da dieser Pin automatisch auf \SI{-10}{\volt} lasergetrimmt ist. In der Simulation ist diese Spannung positiv und muss über eine externe Quelle an das Schaltsymbol angeschlossen werden. \par
\medskip

Aus den zuvor genannten Gründen werden die finalen Gesamtsimulationen in LTspice durchgeführt. Hier funktioniert die \text{.ac}-Simulation des Gesamtsystems trotz des identischen Simulationsmodells einwandfrei. Das könnte daran liegen, dass diese Simulationsumgebung sehr stark optimert wurde und dadurch stabiler funktioniert und Simulationen seltener wegen Konvergenzproblemen abbrechen. \par
\medskip

Das in der Simualtion in LTspice verwentete Schaltsymbol für den Analogmultiplizierer wurde dabei aus dem ASLK-PRO GitHub Repositorium \cite{gith_meiners_aslk} von Prof. Meiners übernommen. Die sonstige Schaltung und Simulationsdateien stammen aus den angegebenen Quellen oder wurden selber erarbeitet.\par
\medskip

\section{Kleinsignalanalyse}

Da die Kleinsignalanalyse bereits ein wesentlicher Bestandteil der Vermessung des herkömmlichen Biquad-Filters im Modul ANS war, sollte auch der Self-Tuned Filter über diese Messmethode aufgenommen werden. \par
\medskip

\begin{figure} [H]
  \centering
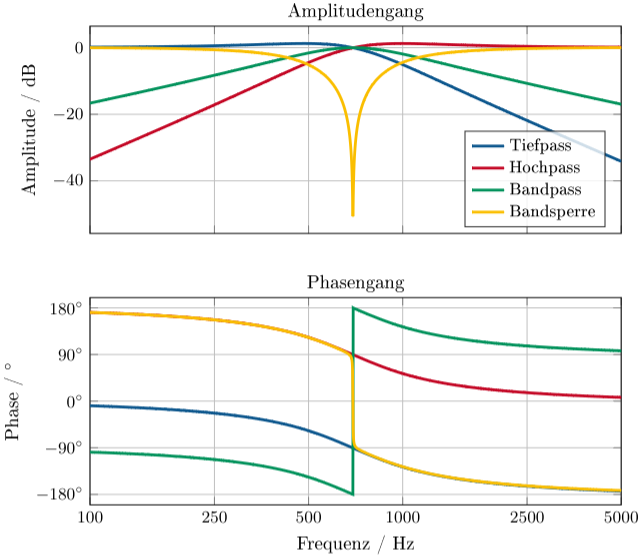
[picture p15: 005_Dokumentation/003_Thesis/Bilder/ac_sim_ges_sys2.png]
    
    \caption{Kleinsignalanalyse des Gesamtsystems}
    \label{fig:ac_sim_ges_sys}
\end{figure}

%\begin{figure} [H]
%  \centering
%    \includegraphics[width=0.8\linewidth]{../Bilder/ac_sim_ges_sys.png}
%    \caption{Kleinsignalanalyse des Gesamtsystems}
%    \label{fig:ac_sim_ges_sys}
%\end{figure}

Die Ergebnisse in Abbildung \ref{fig:ac_sim_ges_sys} zeigen keine Unregelmäßigkeiten im Filterverlauf. Einzig die Mittenfrequenz liegt mit etwa \SI{700}{\hertz} deutlich über dem Vergleichswert des Standard-Biquads mit \SI{160}{\hertz}. Dieser Unterschied ergibt sich vermutlich durch die verschiedenen Definitionen für die Resonanzfrequenzen der beiden Filter. \par
\medskip 

Zudem soll der Einfluss des Widerstandsnetzwerks um die Hilfsspannung  $V_H$ untersucht werden. In der \text{.ac}-Simulation zeigt sich, dass diese Widerstandswerte einen starken Einfluss auf die Mittenfrequenz haben. Je kleiner $R_{10}$ und je größer $R_{11}$ dimensioniert werden, desto kleiner wird die Resonanzfrequenz des Filters. Eine genauere Analyse anhand dieses Simulationstyps führt dabei zu keinen weiteren Ergebnissen. \par
\medskip

Auf die Ermittlung der Mittenfrequenz wird in Kapitel \ref{sec:veri_omega0} genauer eingegangen, da die Untersuchung der beiden sich wiedersprechenden Gleichungen primär an dem realen System durchgeführt wurden.\par
\medskip

\section{Sprungantwort des Self-Tuned Filters}

Um das dynamische Verhalten des selbsteinstellenden Filters bei Frequenzänderungen besser nachvollziehen zu können, soll das System über eine Simulation genauer analysiert werden. Dafür wird die aus der Regelungstechnik bekannte Sprungantwort aufgenommen. Da die Mittenfrequenz des Filters der Eingangsfrequenz folgen soll, wird in diesem Fall ein Frequenzsprung als Eingangsgröße gewählt.\par
\medskip

Da LTspice keine Standardkomponente für eine veränderbare Frequenzquelle besitzt, wird diese als spannungsgesteuerte Frequenzquelle aus zwei Teilmodellen zusammengebaut.\par
\medskip

Das erste Teilmodell ist eine PULSE-Spannungsquelle, die zu einem definierten Zeitpunkt sprunghaft zwischen zwei Potentialen wechseln kann. Sie dient so gesehen als Steuerspannung für den Sprung. Das zweite Teilmodell ist eine verhaltensbasierte Spannungsquelle (Arbitrary Behavioral Voltage Source), die die Steuerspannung mathematisch in ein Ausgangssignal umwandeln kann. Wird nun die Gleichung\par
\medskip

\begin{equation}
    V_{out}=0.1\cdot sin(2\pi \cdot (750+1250 \cdot V_{PULSE}) \cdot t)
    \label{eq:sim_bv}
\end{equation}

in der verhaltensbasierten Quelle implementiert, ergibt sich für den Output der Quelle\par
\medskip

\begin{itemize} 
    \item $V_{PULSE} = \SI{0}{\volt} \implies f_{in} = \SI{750}{\hertz}$ 
    \item $V_{PULSE} = \SI{1}{\volt} \implies f_{in} = \SI{2000}{\hertz}$ 
\end{itemize}

abhängig von der Ausgangsspannung der PULSE-Quelle. In dieser Konfiguration wirkt die verhaltensbasierte Spannungsquelle wie ein \gls{vco}, da die Ausgangsfrequenz proportional zur Eingangsspannung ist. \par
\medskip 

Bei der ersten Analyse der Simulationsergebnisse zeigt sich, dass das Eingangs- und das Hochpasssignal keine \SI{90}{\degree}-Phasenverschiebung zu einander aufweisen. Dieses Verhältnis ändert sich auch im zeitlichen Verlauf der Simulation nur marginal, was sich im Ausgang des Multiplizierers im \gls{pd} widerspiegelt. Der Gleichspannungsanteil des Ausgangssignals bleibt nahezu konstant, zeigt aber eine geringe abfallende Tendenz. Das deutet darauf hin, dass ein Regelprozess stattfindet. Jedoch scheint die \textbf{Änderungsrate/Anpassungsrate} des Filters zu gering für das gewählte Zeitfenster zu sein.\par
\medskip

Die Anpassungsrate des Systems wird stark durch die Zeitkonstante des Integrators beeinflusst. Wie bereits in Kapitel \ref{sec:anpassungsrate} erläutert, lässt sich die Änderungsrate der Ausgangsspannung über die äußere Beschaltung des Integrators beeinflussen. Während eine Erhöhung des Widerstandes (z. B. von \SI{1}{\kilo\ohm} auf \SI{5}{\kilo\ohm}, Abbildung~\ref{fig:pd_op_out}) zu einer flacheren Integrationsrampe und somit zu einer langsameren Regelung führt, kann das System durch eine Reduktion der Bauteilwerte beschleunigt werden.\par
\medskip

Neben der Veringerung der Bauteilwerte der äußeren Beschaltung des Integrators kann zudem die Dauer der Transientenanalyse von \SI{50}{\milli\second} auf \SI{435}{\milli\second} erweitert werden. So soll sichergestellt werden, dass der gesamte Einschwingvorgang aufgenommen wird.\par
\medskip

Das Ergebnis dieser Anpassung ist, dass $V_{HP}$ und $V_{in}$ nach einer gewissen Einschwingzeit eine Phasenlage von \SI{90}{\degree} erreichen. Der DC-Offset am Ausgang des Multiplizierers konvergiert, wie in Abbildung \ref{fig:sprung_mult_out} zu sehen, gegen \SI{0}{\volt}, was den eingeschwungenen Zustand des Systems bestätigt.\par
\medskip

Nach den vorgenommenen Anpassungen liefern die Amplitudenverläufe physikalisch schlüssige Ergebnisse, was in Abbildung \ref{fig:sprung_HP_TP} anhand der Hüllkurven zu erkennen ist. Die Simulation umfasst dabei zwei Frequenzsprünge, bei dem der Erste nach einer kurzen Einschwingphase von \SI{10}{\milli\second} von \SI{750}{\hertz} auf \SI{2}{\kilo\hertz} springt. Nach weiteren \SI{150}{\milli\second} fällt die Eingangsfrequenz wieder auf den Anfangswert ab. Die Ausschläge der Hüllkurve um die Frequenzsprünge liegen wahrscheinlich an dem abrupten Frequenzsprung und der damit verbundenen Phasenbeeinflussung. \par
\medskip

\begin{figure} [H]
  \centering
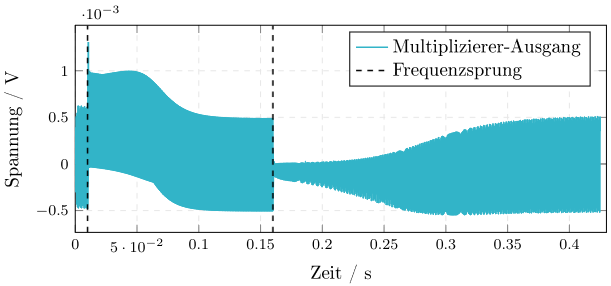
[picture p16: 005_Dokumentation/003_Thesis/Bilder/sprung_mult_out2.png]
    
    \caption{Signalverlauf am Multiplizierer im Phasendetektor }
    \label{fig:sprung_mult_out}
\end{figure}

%\begin{figure} [H]
%  \centering
%    \includegraphics[width=0.8\linewidth]{../Bilder/sprung_mult_out.png}
%    \caption{Signalverlauf am Multiplizierer im Phasendetektor }
%    \label{fig:sprung_mult_out}
%\end{figure}

Trotz der Optimierung der Integratorparameter scheint die Einschwingzeit immernoch lange zu dauern (keine referenz). Um bei der Simulation einen merklichen Effekt zu haben wurde ein Frequenzsprung zwischen \SI{750}{\hertz} und \SI{2000}{\hertz} gewählt. Dabei wurde die Signalamplitude auf \SI{0.1}{\volt} begrenzt, da höhere Werte die Simulation instabiler werden lassen. Eine Begründung dafür könnte die Slew-Rate der \glspl{opv} sein, da die Steilheit der Flanken bei geringerer Amplitude nicht so hoch ist wie bei hoher Amplitude. Auch könnte es an einer Übersteuerung der Multiplizierer im \gls{vcf} liegen, weswegen die Signalamplitude einfach begrenzt wird.\par
\medskip

\begin{figure} [h!]
  \centering
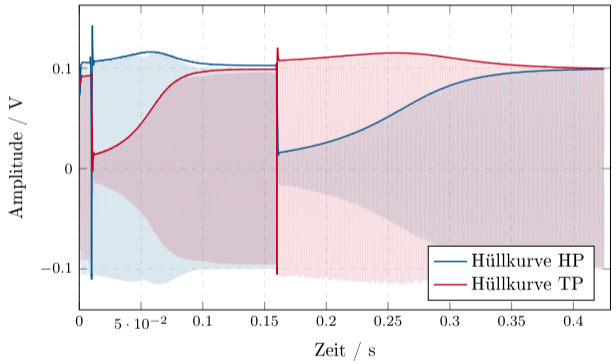
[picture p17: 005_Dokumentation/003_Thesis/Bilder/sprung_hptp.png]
    
    \caption{Amplituden-Einschwingverhalten des Biquads für Hoch- und Tiefpass}
    \label{fig:sprung_HP_TP}
\end{figure}

%\begin{figure} [h!]
%  \centering
%    \includegraphics[width=0.8\linewidth]{../Bilder/sprung_HP_TP.png}
%    \caption{Amplituden-Einschwingverhalten des Biquads für Hoch- und Tiefpass}
%    \label{fig:sprung_HP_TP}
%\end{figure}

Der Hochpass-Verlauf zeigt beim ersten Sprung einen Amplitudenanstieg, da die neue Frequenz tiefer im Durchlassbereich liegt. Während des Einschwingens auf die neue Frequenz durchläuft das System einen Amplitudenpeak. Dieser Effekt ist auf eine Filtergüte von $Q>\frac{1}{\sqrt{2}}$ zurückzuführen, die eine Resonanzüberhöhung zwischen dem Durchlassbereich und der Sperrgrenze verursacht. Sobald sich der Filter auf die neue Frequenz eingestellt hat, stabilisiert sich die Amplitude wieder auf den Nennwert. Beim negativen Frequenzsprung auf \SI{750}{\hertz} springt das Signal zunächst in den Sperrbereich des Hochpasses, woraufhin die Amplitude einbricht und erst durch die langsame Nachführung der Grenzfrequenz wieder ansteigt.\par
\medskip

Die Amplitude des Tiefpasses verhält sich dazu komplementär. Der positive Frequenzsprung führt kurzzeitig zu einer starken Dämpfung, während beim Amplitudenverlauf des negativen Sprungs die Resonanzüberhöhung des Durchlassbereichs zu erkennen ist. \par
\medskip

Zudem fällt auf, dass die Anpassung des Systems bei höheren Frequenzen beziehungsweise positiven Frequenzsprüngen weniger Zeit benötigt als bei negativen Sprüngen. Um dieses Ungleichgewicht besser zu verstehen wird zunächst die Kennlinie der Steuerspannung gemäß der selbst hergeleiteten Gleichung für die Resonanzfrequnez \ref{eq:filtergrenzfrequenz}  untersucht. \par
\medskip

\begin{table}[h]
    \centering
    \begin{tabular}{c|c|c}
        \textbf{Eingangsfrequenz} & \textbf{$V_c$ / \si{\volt}} & \textbf{$\Delta V_c$ zu $V_{c_{\SI{750}{\hertz}}}$ / \si{\volt}} \\ \hline
        500 & 3.18 & 1.06 \\
        750 & 2.12 & - \\
        1000 & 1.59 & 0.56 \\
    \end{tabular}
    \caption{Erforderliche Steuerspannung $V_c$ für verschiedene Eingangsfrequenzen}
    \label{tab:sim_einschwingzeit}
\end{table}

Wie in Tabelle \ref{tab:sim_einschwingzeit} ersichtlich, ist der Zusammenhang zwischen Frequenz und Steuerspannung nicht linear. Ein Frequenzsprung um \SI{250}{\hertz} nach unten erfordert mit \SI{1.06}{\volt} eine deutlich größere Spannungsänderung als ein betraglich gleich großer Sprung nach oben mit \SI{0.56}{\volt}. Dies würde theoretisch zu asymmetrischen Einschwingzeiten führen. Da in der vorliegenden Simulation jedoch zwischen zwei festen Frequenzen hin- und hergesprungen wird, ist der Spannungsunterschied für den Hin- und Rückweg der selbe, weshalb dieser Effekt die beobachtete Differenz in der Anpassungsrate nicht erklären kann.\par
\medskip

Die Ursache lässt sich stattdessen über Amplitudengang des Hochpasses erklären, der einer der beiden Eingangsgrößen des Phasendetektors ist. Bei einem Sprung zu kleineren Frequenzen wird die Hochpassamplitude vorerst stark gedämpft. Da sich die Amplitude des Multipliziererausgangs proporitional zur Amplitude der Eingangssignale verhält, verringert sich der Pegel des Ausgangssignals ebenso, was zu einem geringeren DC-Offset am Integratioreingang führt (Siehe Abbildung \ref{fig:sprung_mult_out}). Dies resuliert wiederum in einer geringeren Änderungsrate der Steuerspannung $V_c$ und somit in einer langsameren Frequenzanpassung. Bei einem positiven Frequenzsprung bleibt das Singal im Durchlassbereich des Hochpasses, wodurch die Änderungsrate nicht einbricht, sondern durch die Resonanzüberhöhung sogar leicht steigen kann. In der Theorie müsste sich dieses Verhalten exakt umkehren, wenn der Phasendetektor statt des Hochpasssignals das Signal des Tiefpasses abgreifen würde, da dort die Dämpfung bei hohen Frequenzen am stärksten ausgeprägt ist.\par
\medskip 

\begin{figure} [h!]
  \centering
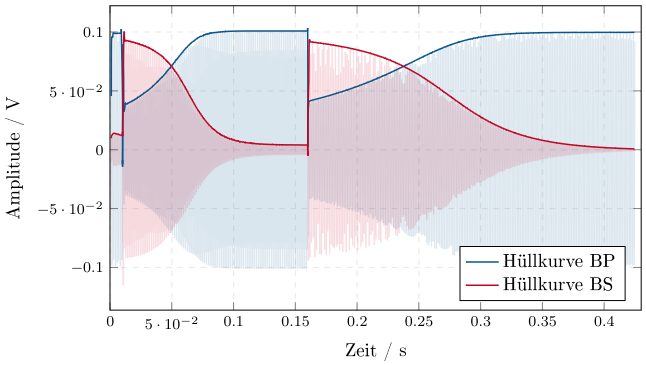
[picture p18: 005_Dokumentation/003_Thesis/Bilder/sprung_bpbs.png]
    
    \caption{Amplituden-Einschwingverhalten für Bandpass und Bandsperre}
    \label{fig:sprung_BP_BS}
\end{figure}

%\begin{figure} [H]
%  \centering
%    \includegraphics[width=0.8\linewidth]{../Bilder/sprung_BP_BS.png}
%    \caption{Amplituden-Einschwingverhalten für Bandpass und Bandsperre}
%    \label{fig:sprung_BP_BS}
%\end{figure}

In Abbildung \ref{fig:sprung_BP_BS} sind die Verläufe des Bandpass- und Bandsperrausgangs dargestellt. Auffällig ist, dass die Amplitude des Bandpasses bei einem Frequenzsprung, unabhängig vom Vorzeichen, zunächst einbricht und sich anschließend im Laufe der Frequenzanpassung wieder aufbaut. Die Bandsperre verhält sich komplementär dazu. Bei einem Sprung tritt eine starke Amplitudenerhöhung auf, die im Verlauf über die Anpassung wieder gedämpft wird. Dieses Verhalten ist durch die Symmetrie der Filtertypen zu begründen, denen Amplitudengang auf beiden Seiten der Resonanzfrequenz ähnlich verläuft.\par
\medskip

Im Folgenden wird die in Kapitel \ref{sec:herleitung_vcf} aufgestellte Hypothese überprüft, dass die Einschwingdauer direkt von der durch den Sprung erzeugten Frequenzabweichung abhängt. Dafür wird das Systemverhalten für verschiedene Startfrequenzen (\SI{250}{\hertz}, \SI{500}{\hertz} und \SI{750}{\hertz}) auf die Zielfrequenz von \SI{1000}{\hertz} simuliert. Dieser Frequenzbereich wurde gewählt, da die Änderung der Steuerspannung im niederen Frequenzbereich am höchsten ist und somit die Änderung am sichtbarsten sein sollte. \par
\medskip

Die Abbildung \ref{fig:sim_fallhöhe} zeigt die resultierenden Spannungsverläufe. Der alleinige Vergleich der blauen (\SI{500}{\hertz}) und roten (\SI{750}{\hertz}) Kennlinien scheint die Hypothese zu widerlegen. Die blaue Kurve startet anfangs zwar mit einem größeren Potential, erreicht die Zielspannung aber durch eine höhere Änderungsrate zeitgleich mit der roten Kurve nach etwa \SI{0.08}{\second}.
\medskip

\begin{figure} [H]
  \centering
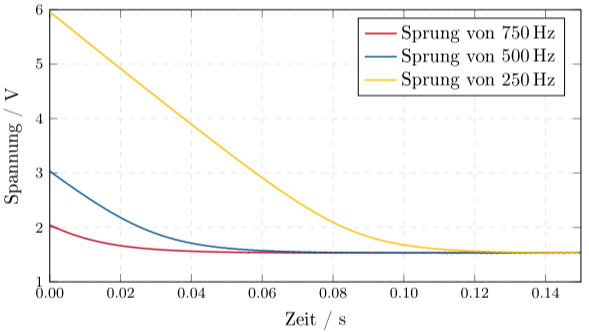
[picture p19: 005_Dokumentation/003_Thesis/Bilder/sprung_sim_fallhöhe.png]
    
    \caption{Validierung der Hypothese zur Einschwingdauer}
    \label{fig:sim_fallhöhe}
\end{figure}

%\begin{figure} [H]
%  \centering
%    \includegraphics[width=0.8\linewidth]{../Bilder/sim_fallhöhe.png}
%    \caption{Validierung der Hypothese zur Einschwingdauer}
%    \label{fig:sim_fallhöhe}
%\end{figure}

Bei der Untersuchung des Sprungs von \SI{250}{\hertz} ist jedoch zu erkennen, dass die Änderungsrate nach oben hin limitiert ist. So ist die Einschwingzeit des Systems bei dem größeren Frequenzsprung mit etwa \SI{0.13}{\second} deutlich länger. Diese Beobachtung lässt sich auf die maximale Änderungsrate des Systems zurückführen, wobei große Sprünge in eine Sättigung der Änderungsrate geraten. Dies ist in Abbildung \ref{fig:sim_fallhöhe} deutlich an dem nahezu linearen, rampenförmigen Abfall der gelben Kurve zu erkennen.\par
\medskip

So kann gesagt werden, dass die Hypothese für große Frequenzsprünge korrekt ist. Bei geringen Frequenzabweichungen und im höheren Frequenzbereich wird das Limit der Änderungsrate jedoch nicht erreicht. Zusammengefasst gilt, dass die Einschwingzeit erst ab dem Erreichen der maximalen Änderungsrate des Systems direkt proportional zur Frequenzabweichung ansteigt.\par
\medskip 

% wenn noch zeit hier die Steuerspannungsänderungsrate und frequenzänderungsrate des systems

\subsection{Analyse der Hilfsspannungsquelle über die Sprungfunktion}

Bei der genaueren Untersuchung der Hilfsspannungsquelle $V_H$ und des vorgeschalteten Widerstandsnetzwerks wird der Ausgang des Integrators im Phasendetektor $V_{int}$ mit der Steuerspannung $V_c$ verglichen. Für den bisher betrachteten Fall mit $R_{10}= R_{11} = \SI{1}{\kilo\ohm}$ zeigt Abbildung \ref{fig:sprung_int_pd_out} das Zeitverhalten von $V_{int}$ und $V_c$.\par
\medskip

\begin{figure} [H]
  \centering
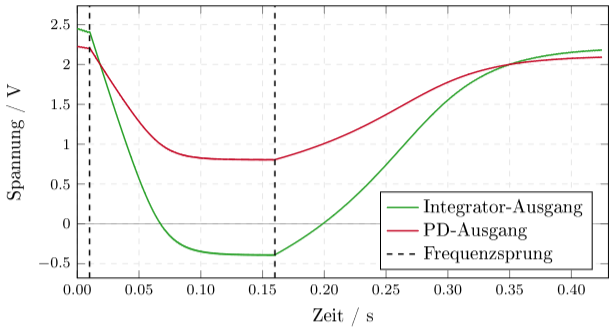
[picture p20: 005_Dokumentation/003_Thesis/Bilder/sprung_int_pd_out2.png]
    
    \caption{Spannungsvergleich am Integrator- und Phasendetektorausgang}
    \label{fig:sprung_int_pd_out}
\end{figure}

%\begin{figure} [H]
%  \centering
%    \includegraphics[width=0.8\linewidth]{../Bilder/sprung_int_pd_out.png}
%    \caption{Spannungsvergleich am Integrator- und Phasendetektorausgang}
%    \label{fig:sprung_int_pd_out}
%\end{figure}

Dabei ist deutlich zu erkennen, dass $V_{int}$ stark in den negativen Spannungsbereich geht, während die Steuerspannung positiv bleibt. Bei eingeschwungenem System auf \SI{2}{\kilo\hertz} hat $V_c$ einen DC-Anteil von \SI{0.799}{\volt}. Wird dieser Wert in die selbstständig hergeleitete Mittenfrequenzgleichung eingesetzt, ergibt sich \par

\begin{equation*}
  f_0 = \frac{V_r}{V_c \cdot R \cdot C \cdot 2\pi} = \frac{\SI{10}{\volt}}{\SI{0.799}{\volt}\cdot \SI{1}{\kilo\ohm} \cdot \SI{1}{\micro\farad} \cdot 2\pi} = \SI{1.992}{\kilo\hertz},
\end{equation*}

was sehr Nahe an den am Eingang eingespeisten \SI{2}{\kilo\hertz} liegt. Gleiches gilt für den zweiten Sprung auf \SI{750}{\hertz}, bei dem $V_c$  ein Spannungslevel erreicht, was rechnerisch einer Frequenz von \SI{737}{\hertz} entspricht.\par
\medskip

Wie in Abbildung \ref{fig:sprung_pd_out_diff_r} zu sehen ist, gleicht sich $V_{int}$ dem Potential der Steuerspannung $V_c$ für den eingeschwungenen Zustand immer weiter an, bis sie für eine Kombination von $R_{10} = \SI{100}{\ohm}$ und $R_{11} = \SI{100}{\kilo\ohm}$ nahezu identisch sind. \par
\medskip

\begin{figure} [H]
  \centering
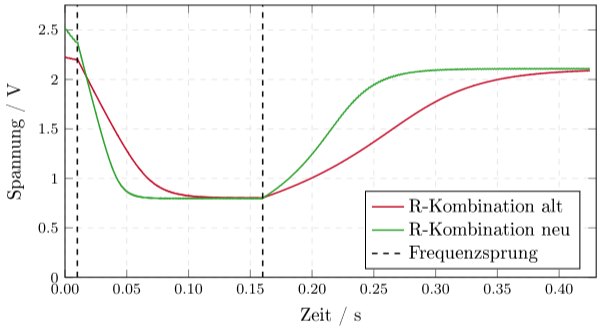
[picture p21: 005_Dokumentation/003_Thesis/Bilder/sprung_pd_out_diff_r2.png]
    
    \caption{PD-Ausgang für verschiedene Widerstandskombinationen}
    \label{fig:sprung_pd_out_diff_r}
\end{figure}

%\begin{figure} [H]
%  \centering
%    \includegraphics[width=0.8\linewidth]{../Bilder/sprung_pd_out_diff_r.png}
%    \caption{PD-Ausgang für verschiedene Widerstandskombinationen}
%    \label{fig:sprung_pd_out_diff_r}
%\end{figure}

Zudem ist zu erkennen, dass der Ausgangswert des Integrators für die neue Widerstandskombination deutlich schneller an die Steuerspannung weitergegeben wird. So kann das System die Zielspannung nach einem Frequenzsprung wesentlich schneller erreichen. Bei der Dimensionierung von $R_{10}$ muss allerdings auch der Ausgangsstrom des \gls{opv} berücksichtigt werden, weshalb der Widerstandswert, besonders im realen System, nicht beliebig klein angenommen werden darf. \par
\medskip

\section{Einschwingbereich des Filters}

Ziel dieser Untersuchung ist die simulative Bestimmung der Filtergrenzen, innerhalb derer die Regelschleife stabil einschwingt und die Resonanzfrequenz des Filters  der Eingangsfrequenz folgen kann. Hierbei soll die Eingangsfrequenz linear erhöht werden, um die Mittenfrequenz zu ermitteln, an der das System die Synchonisation verliert. \par
\medskip

Für die Simulation wird der Schaltungsaufbau der Sprungantwort leicht modifiziert. Die PULSE-Quelle generiert eine lineare Rampe, die durch die verhaltensbasierte Spannungsquelle kontinuierlich über einen vorgegebenen Frequenzbereich sweept. Die Transient-Analyse wird dabei so eingestellt, dass diese der Dauer der Rampenzeit entspricht. Um herauszufinden, ab welcher Frequenz sich das System nicht selbst wieder einstellen kann, wird die Steuerspannung $V_c$ sowie die Signale innerhalb des \gls{pd} beobachtet. Dabei wird angenommen, dass Oszillationen oder ein Abreißen der Regelung zu erkennen sind, sobald das System der Eingangsspannung nicht weiter folgen kann. \par
\medskip

Bei der Simulation wird zudem auch die Geschwindigkeit der Frequenzänderung variiert. Dabei zeigt sich, dass die Verläufe der Steuerspannung von schnellem und langsamen Sweep sehr unterschiedlich ausfallen. Bei einem schnellen Sweep verläuft $V_c$ bis zum Erreichen der Zielspannung nahezu linear, während der Verlauf  für einen langsamen Sweep eher an den exponentiellen Verlauf der abklingenden Ladekurve eines Kondensators erinnert. Genauer ist das in Abbildung \ref{fig:ramp_vgl} dokumentiert.\par
\medskip

\begin{figure} [H]
  \centering
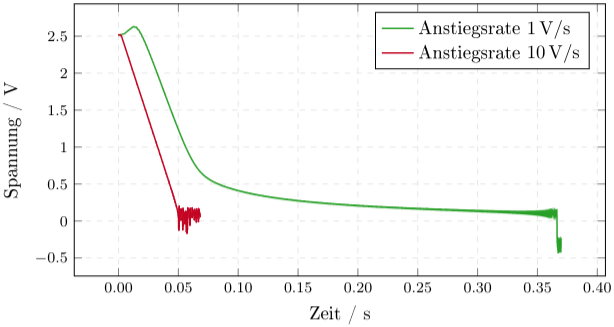
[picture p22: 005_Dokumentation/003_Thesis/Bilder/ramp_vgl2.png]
    
    \caption{Vergleich der Steuerspannung bei unterschiedlchen Frequenzanstiegsraten}
    \label{fig:ramp_vgl}
\end{figure}

%\begin{figure} [H]
%  \centering
%    \includegraphics[width=0.8\linewidth]{../Bilder/ramp_vgl.png}
%    \caption{Vergleich der Steuerspannung bei unterschiedlchen Frequenzanstiegsraten}
%    \label{fig:ramp_vgl}
%\end{figure}

\textbf{die max steigung der beiden verläufe ist nahezu gleich. auch dokumentieren bitte}
Ebenfalls auffällig ist die große Diskrepanz zwischen der Eingangsfrequenz und der aus der Größe von $V_c$ resultierenden Resonanzfrequenz des Filters. Die Mittenfrequenz scheint der Eingangsfrequenz nicht zu folgen, sondern ihr um einen Faktor von >10 vorrauszueilen. Eine mögliche Erklärung hierfür wäre, dass die Phase durch die kontinuierliche Frequenzänderung dauerhaft verschoben oder komplett verfälscht wird. Das würde dann zu einer fehlerhaften Auswertung und somit zu einer Übersteuerung von $V_c$ führen. \par
\medskip

Bei einem erneuten Vergleich der verschiedenen Widerstandskombinationen aus $R_{10}$ und $R_{11}$ zeigt sich, dass die Artefakte bei langsamen und schnellen Sweep für die neuen Werte deutlich näher aneinander liegen als für die alte Verschaltung. Das deutet auf eine höhere Robustheit hin. \par
\medskip

Zusätzlich wurde geprüft, ob der Filterbereich über die Simulation der Sprungfunktionen ermittelt werden kann. Dabei zeigt die Simulation, dass sich das System bis zu einer Eingangsfrequenzen von \SI{13}{\kilo\hertz} selbst stabilisieren kann. Die rechnerisch ermittelte Resonanzfrequenz liegt mit \SI{13.550}{\kilo\hertz} in der Nähe des Sollwerts. \par
\medskip

\begin{figure} [H]
  \centering
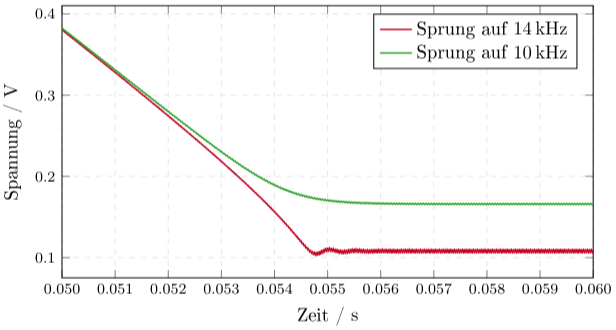
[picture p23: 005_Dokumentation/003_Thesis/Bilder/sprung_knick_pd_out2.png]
    
    \caption{Einschwingverhalten der Steuerspannung für unterschiedliche Frequenzen}
    \label{fig:sprung_knick_pd_out}
\end{figure}

%\begin{figure} [H]
%  \centering
%    \includegraphics[width=0.8\linewidth]{../Bilder/sprung_knick_pd_out.png}
%    \caption{Einschwingverhalten der Steuerspannung für unterschiedliche Frequenzen}
%    \label{fig:sprung_knick_pd_out}
%\end{figure}

Wie in Abbildung \ref{fig:sprung_knick_pd_out} zu erkennen ist, schwingt sich das System auch bei einer Frequenz von \SI{14}{\kilo\hertz} noch korrekt ein. Im Vergleich zu der Einschwingkurve auf \SI{10}{\kilo\hertz} zeigt sich jedoch, dass der Verlauf für hohe Frequenzen immer weniger dem einer Kondensatorentladekurve gleicht. Vielmehr sind daraus zwei Geraden geworden, die über einen harten Knick miteinander verbunden sind. Zudem bilden sich nach diesem Knick erste kleine Schwingungen. Ab einem Sprung von \SI{15}{\kilo\hertz} verliert das System seine Stabilität vollständig und kann den eingeschwungenen Zustand nicht mehr erreichen. Die Simulation zeigt somit, dass die Steuerspannung $V_c$ ein unteres Limit von \SI{0.1}{\volt} nicht unterschreiten kann, was die obere Frequenzgrenze des Filters festlegt. \textbf{gründe für diese 0.1V?} \par
\medskip
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

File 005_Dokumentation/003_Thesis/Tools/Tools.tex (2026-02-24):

%\documentclass[../main_config.tex]{subfiles}
%\begin{document}

\chapter{Tools}

Im Rahmen dieser Bachelorarbeit kommen viele verschiedene Softwerkzeuge für Simulation, Messung, Schaltungsdesign und Darstellung von Messergebnissen zum Einsatz.\par
\medskip
Zu den wichtigsten Tools zählt die \gls{ecad}-Software KiCad 9. Dieses Open-Source-Programm wird unter anderem vom CERN und einer internationalen Entwicklergemeinschaft weiterentwickelt. Die Software umfasst eine umfangreiche Komponentenbibliothek, einen integrierten Schaltplan- und Leiterplatten-Editor, 3D-Visualisierung, zahlreiche Exportformate sowie einen eingebetteten ngspice-Simulator für die Analyse analoger Schaltungen. \par
\medskip

Im Rahmen dieser Thesis wird KiCad hauptsächlich für den Schaltplanentwurf, das PCB-Design sowie für die Simulation der Teilsysteme eingesetzt. Obwohl der integrierte ngspice-Simulator ein breites Spektrum an Analysetypen abdeckt, erweist sich dieser bei komplexeren, nichtlinearen Schaltungsstrukturen als anfällig für Konvergenzprobleme. Dies führt, wie im Fall des verwendeten Multiplizierermodells, insbesondere bei der Kleinsignalanalyse zu Simulationsabbrüchen.\par
\medskip
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

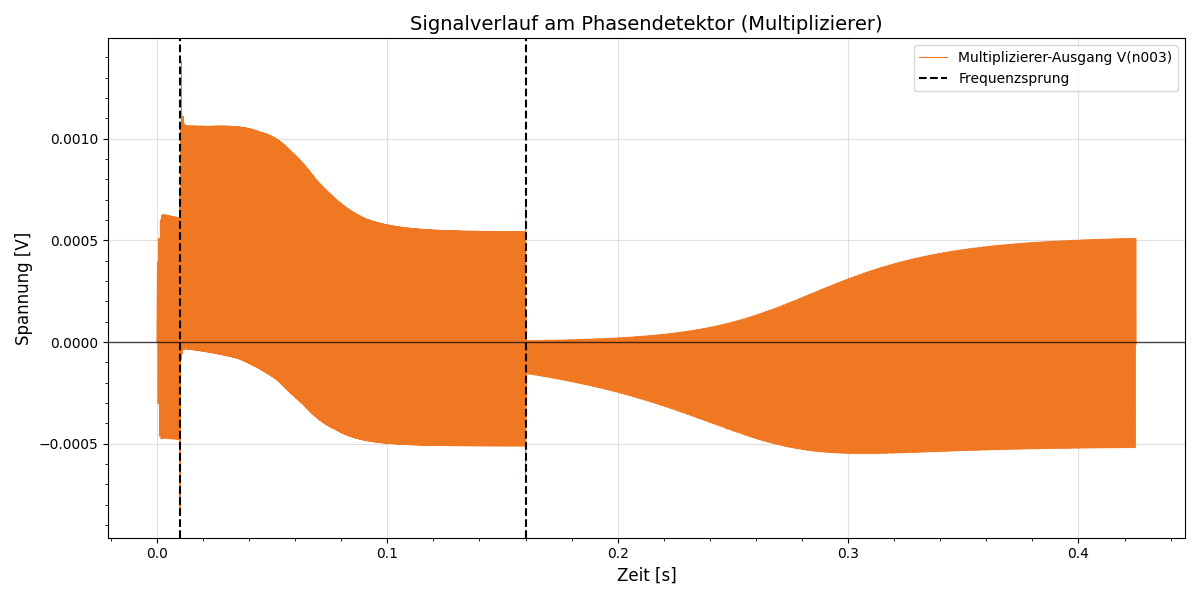
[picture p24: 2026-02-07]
005_Dokumentation/003_Thesis/Bilder/sprung_mult_out.png

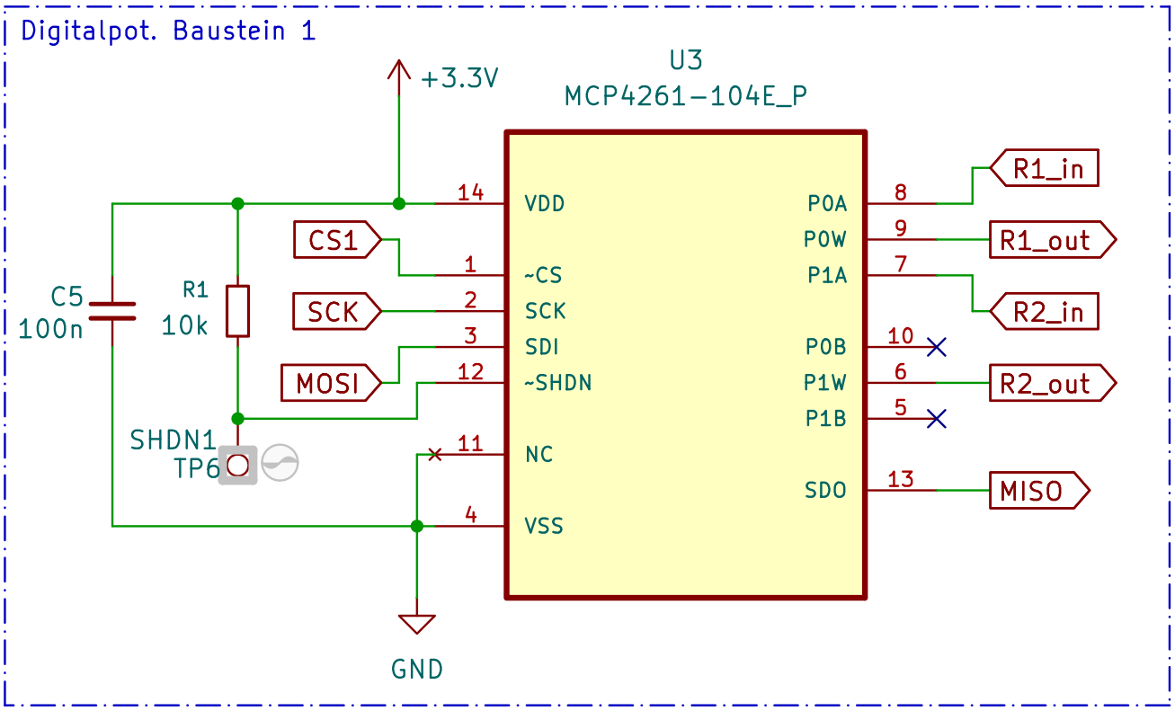
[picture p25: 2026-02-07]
005_Dokumentation/003_Thesis/Bilder/schaltplan_digipot.png

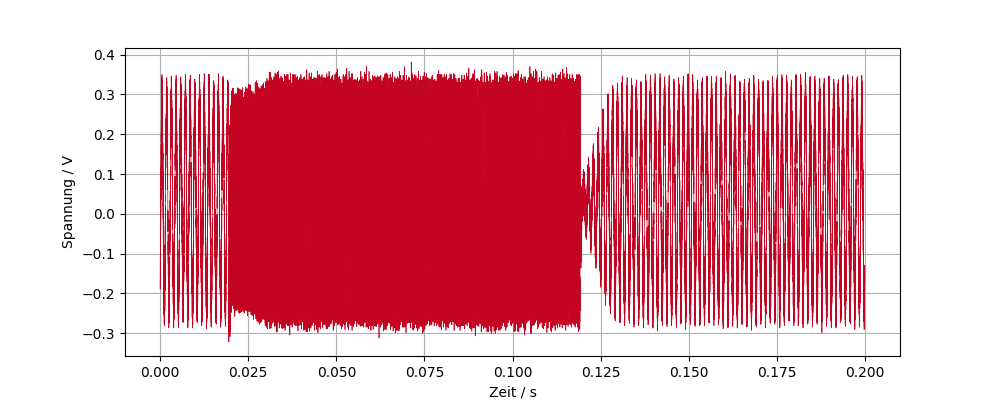
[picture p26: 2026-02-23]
005_Dokumentation/003_Thesis/Bilder/sprung_mess_hp.png

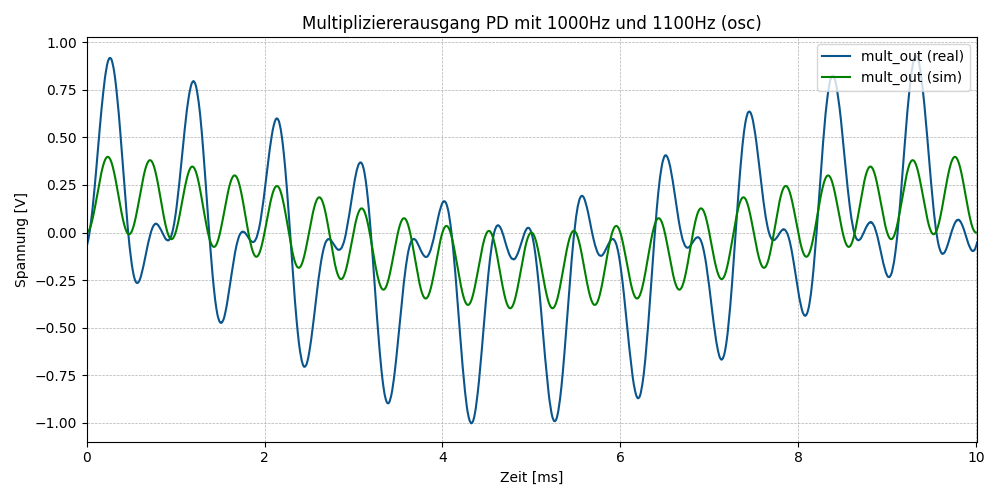
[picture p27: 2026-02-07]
005_Dokumentation/003_Thesis/Bilder/mult_out_osc2.png

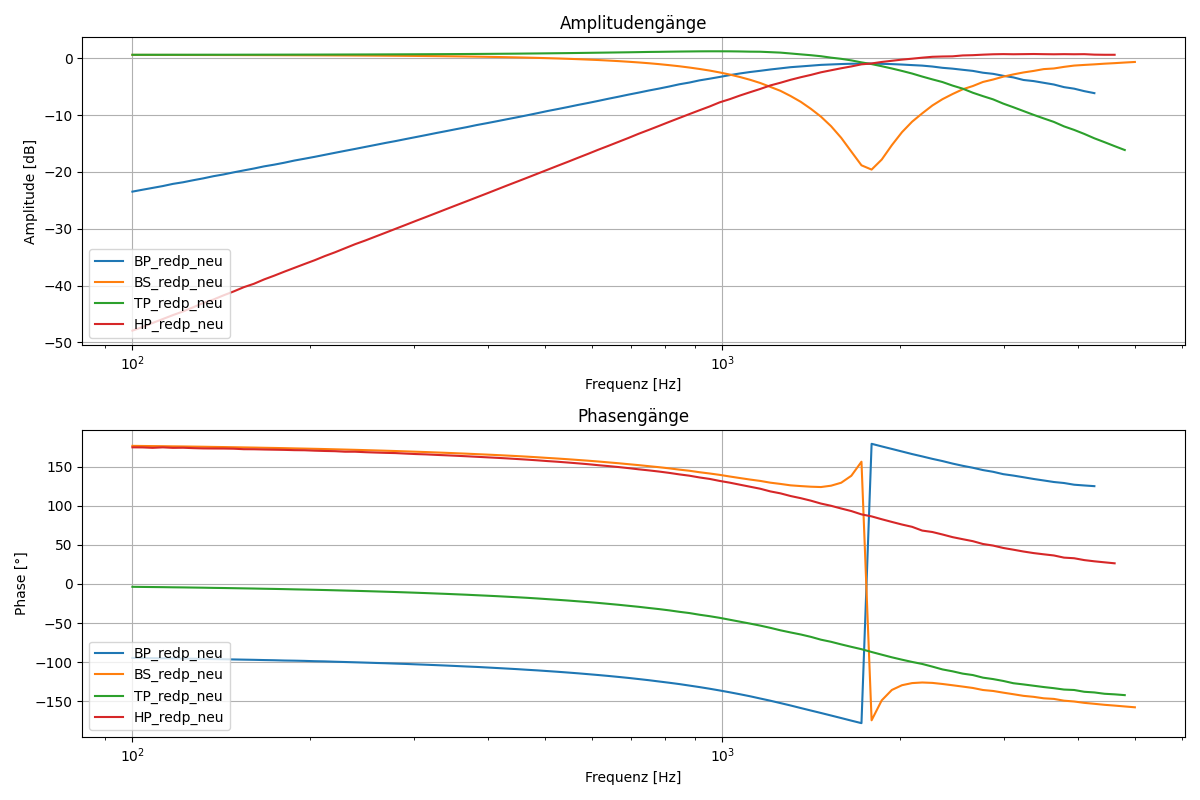
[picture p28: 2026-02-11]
005_Dokumentation/003_Thesis/Bilder/Messung_vcf_ac.png

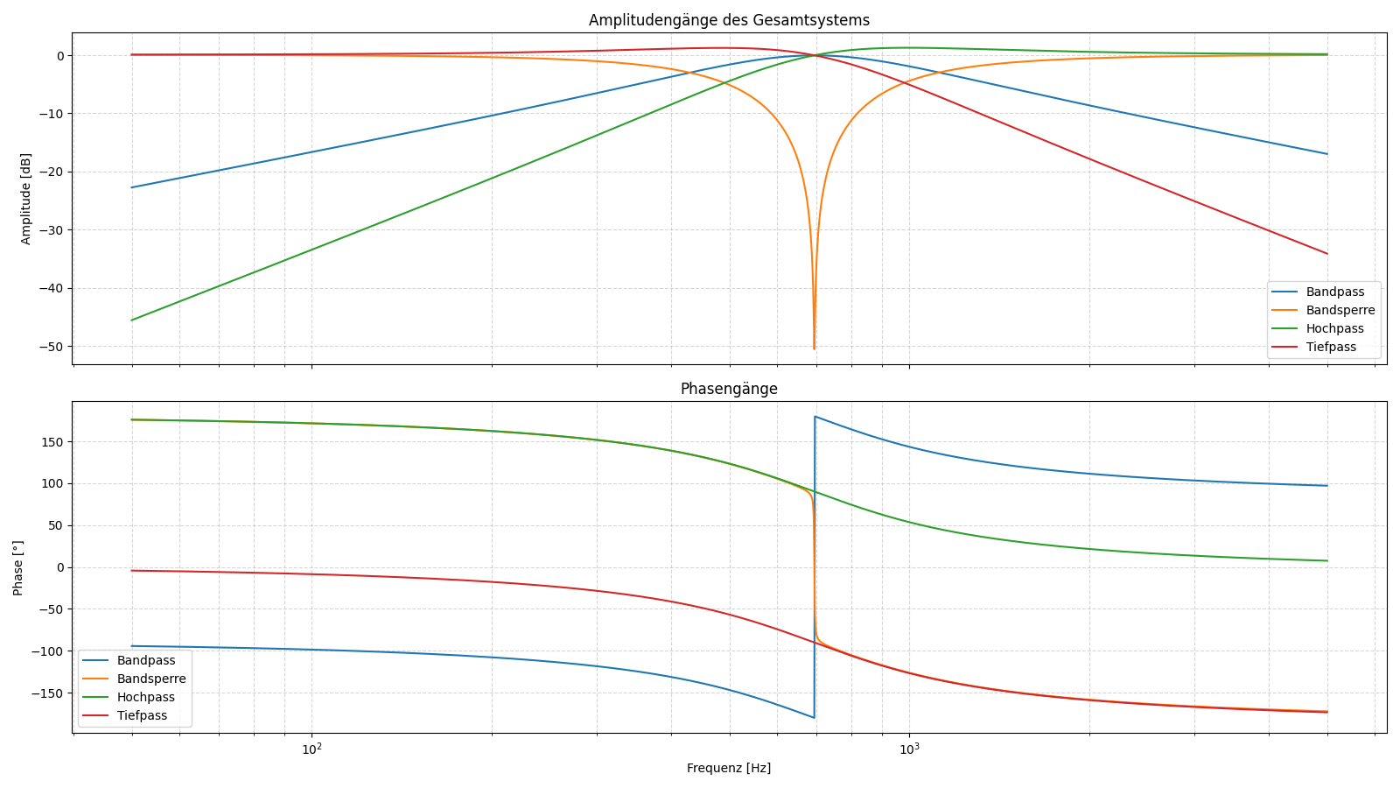
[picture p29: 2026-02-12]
005_Dokumentation/003_Thesis/Bilder/ac_sim_ges_sys.png

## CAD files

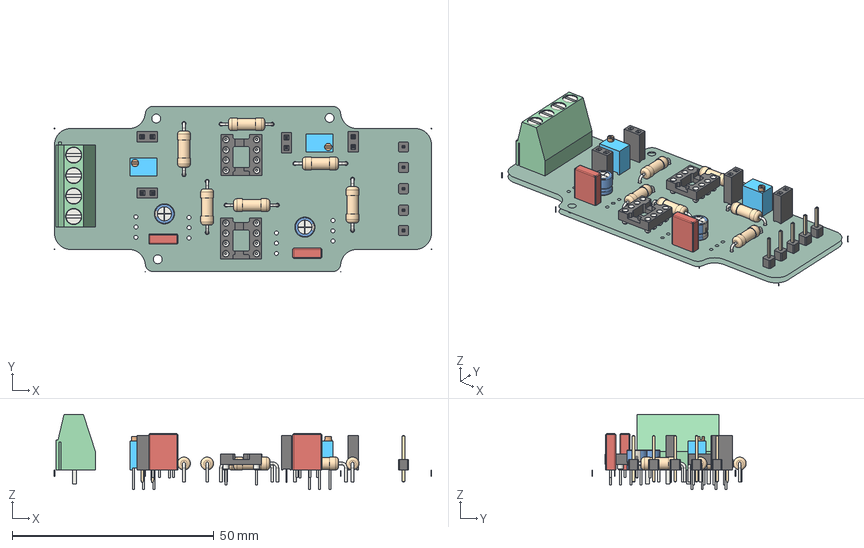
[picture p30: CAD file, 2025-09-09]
001_Analoge_Schaltungen/KiCad_Biquad/pcb_design_nils/pcb_design.step
93.5 x 41.0 x 18.7 mm
DIP-8_W7.62mm_Socket x 2
R_Axial_DIN0309_L9.0mm_D3.2mm_P12.70mm_Horizontal x 6
PinHeader_1x01_P2.54mm_Vertical x 5
CP_Radial_D5.0mm_P2.50mm x 2
TerminalBlock_Phoenix_MKDS-1,5-4-5.08_1x04_P5.08mm_Horizontal
PinSocket_1x02_P2.54mm_Vertical x 4
Potentiometer_Bourns_3266W_Vertical x 2
C_Rect_L7.2mm_W2.5mm_P5.00mm_FKS2_FKP2_MKS2_MKP2 x 2
pcb_design_soldermask
pcb_design_PCB_1
pcb_design_PCB_2
pcb_design_PCB_3
pcb_design_PCB_4
pcb_design_PCB_5
pcb_design_PCB_6

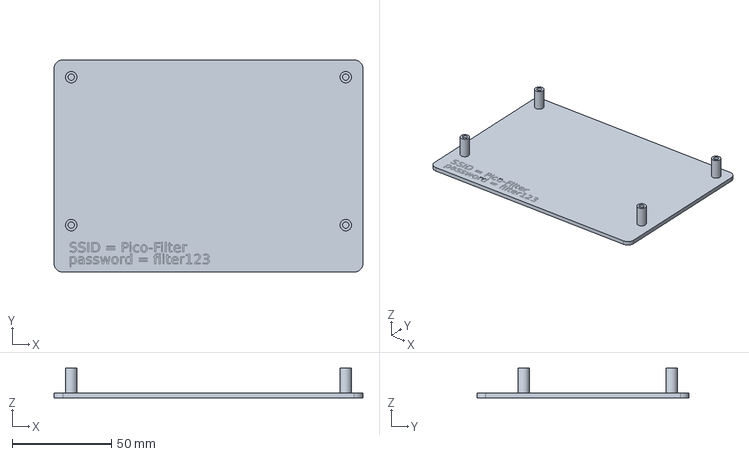
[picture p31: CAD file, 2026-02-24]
002_3D_Modell/pcb_holder.FCStd
156.0 x 107.2 x 15.0 mm

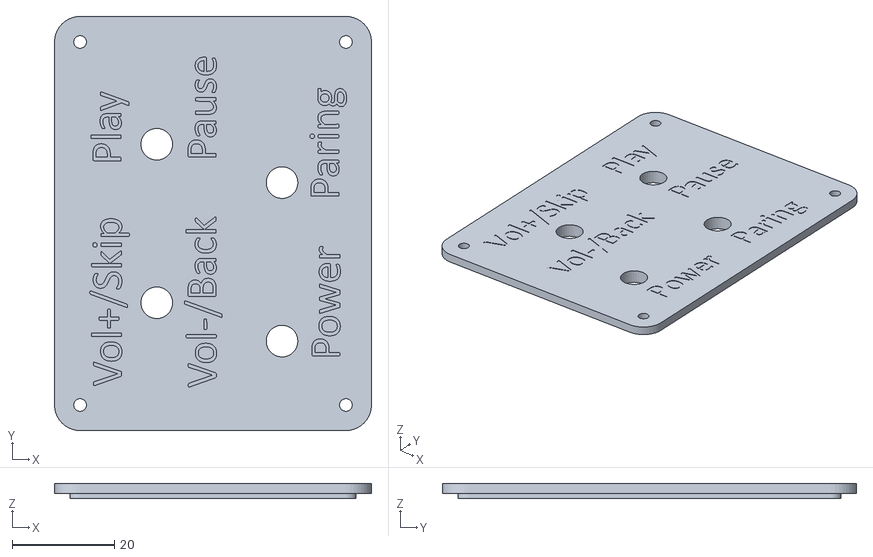
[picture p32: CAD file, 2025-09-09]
001_Analoge_Schaltungen/3D_print/Blue_con v12_deckel.stl
62.0 x 81.0 x 3.00

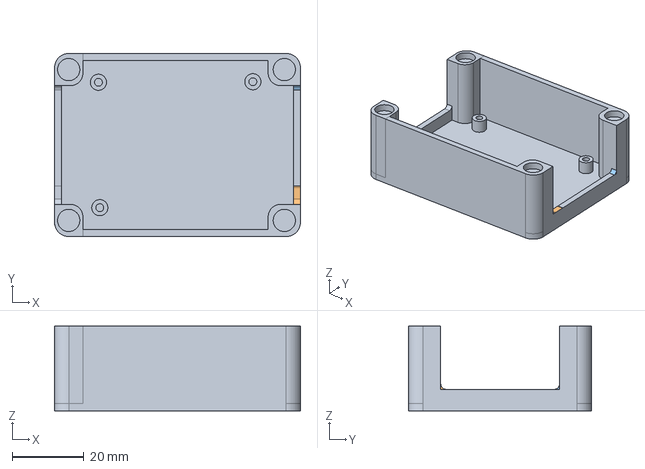
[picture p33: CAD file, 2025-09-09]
001_Analoge_Schaltungen/3D_print/Biquad v8_boden.step
68.5 x 51.0 x 23.6 mm

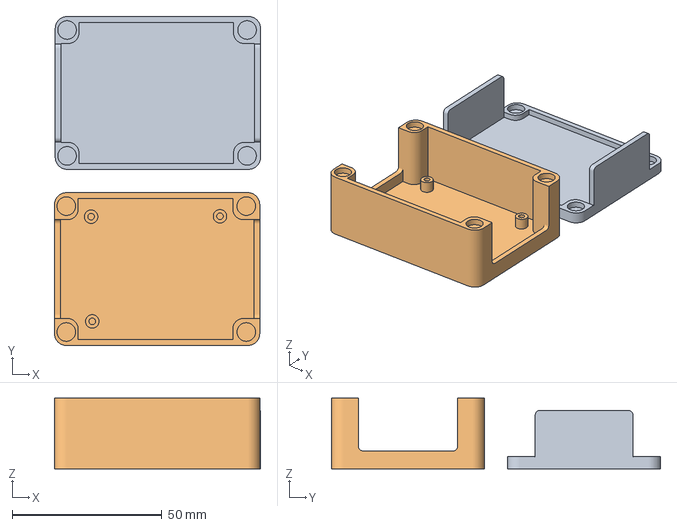
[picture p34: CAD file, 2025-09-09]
001_Analoge_Schaltungen/3D_print/Biquad v8.3mf
68.8 x 109.8 x 23.6 mm
Biquad v8.step
Biquad v8_boden.step

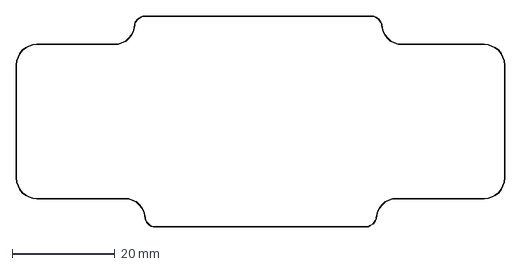
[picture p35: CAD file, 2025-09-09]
001_Analoge_Schaltungen/3D_print/EdgeCut_V3.dxf
95.0 x 41.0 mm

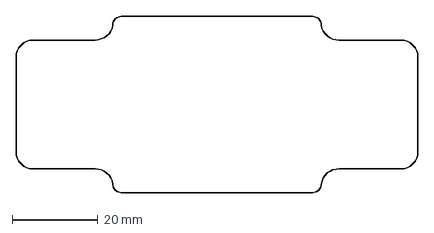
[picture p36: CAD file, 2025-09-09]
001_Analoge_Schaltungen/3D_print/Edge_cut_V5.dxf
93.5 x 41.0 mm

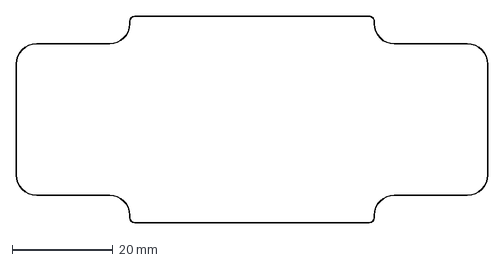
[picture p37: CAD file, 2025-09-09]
001_Analoge_Schaltungen/3D_print/e_cut_v6.dxf
93.5 x 41.0 mm

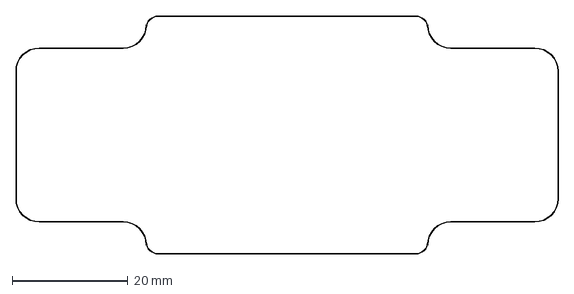
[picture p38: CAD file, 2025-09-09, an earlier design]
001_Analoge_Schaltungen/3D_print/Edge_Cut_V4.dxf
93.5 x 41.0 mm

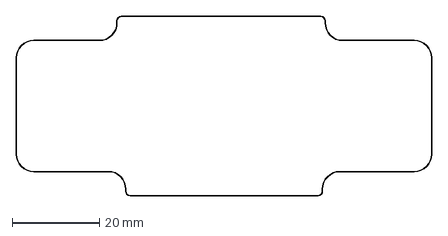
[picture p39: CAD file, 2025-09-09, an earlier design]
001_Analoge_Schaltungen/3D_print/EdgeCut_V2.dxf
95.0 x 41.0 mm

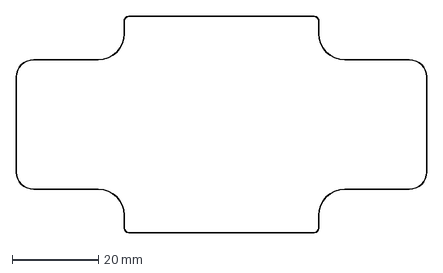
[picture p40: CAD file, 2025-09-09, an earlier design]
001_Analoge_Schaltungen/3D_print/EdgeCut_V1.dxf
95.0 x 50.0 mm

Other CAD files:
001_Analoge_Schaltungen/3D_print/gehäuse_unten.step
002_3D_Modell/pcb_holder.stl

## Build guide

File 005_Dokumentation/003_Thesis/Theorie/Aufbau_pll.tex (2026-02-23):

\begin{tikzpicture}
    [%
    block/.style={draw, fill=white, rectangle, minimum height=2em, minimum width=3em},
    block2/.style={draw, fill=white, rectangle, minimum height=4em, minimum width=6em},
    sum/.style={draw, fill=white, circle, minimum size=2.5em, inner sep=0pt},
    bcircle/.style={draw, fill=black, circle, minimum size= 0.5em, inner sep=0pt},
    lcircle/.style={draw, fill=white, circle, minimum size= 0.5em, inner sep=0pt},
    connector/.style={-Latex, thick},
    node distance=2cm and 2cm
    ]

  \node[lcircle] (input1) at (0,0) {};
\node[block2] (prod) at (3.5,-0.3) {$\text{PD}$};
\coordinate[left=0cm of prod] (stütze);

\coordinate[above=0.3cm of stütze] (mult_int1);
\coordinate[below=0.3cm of stütze] (mult_int2);
\node[lcircle, right=of prod] (mult_out) {};

\node[block2, align=center] (loopfilt) at (7,-0.3) {$\text{Schleifen-}$\\$ \text{filter}$};
\node[block2] (VCO) at (10.5,-0.3) {$\text{VCO}$};

\node[bcircle] (loop) at (12.5,-0.3) {};
\node[lcircle] (out) at (14,-0.3) {};
\coordinate[below=2cm of loop] (loop_stütz1);
\coordinate[left= 11cm of loop_stütz1] (loop_stütz2);

\draw[connector] (input1) -- (mult_int1) node[near start,above] {$V_{in}$};
\draw[connector] (prod) -- (loopfilt) node[midway, above] {$V_{d}$};
\draw[connector] (loopfilt) -- (VCO) node[midway, above] {$V_{c}$};
\draw[connector] (VCO) -- (out) node[near end,above] {$V_{out}$};
\draw(loop) -- (loop_stütz1);
\draw(loop_stütz1) -- (loop_stütz2);
\draw[connector] (loop_stütz2) |- (mult_int2);

\end{tikzpicture}

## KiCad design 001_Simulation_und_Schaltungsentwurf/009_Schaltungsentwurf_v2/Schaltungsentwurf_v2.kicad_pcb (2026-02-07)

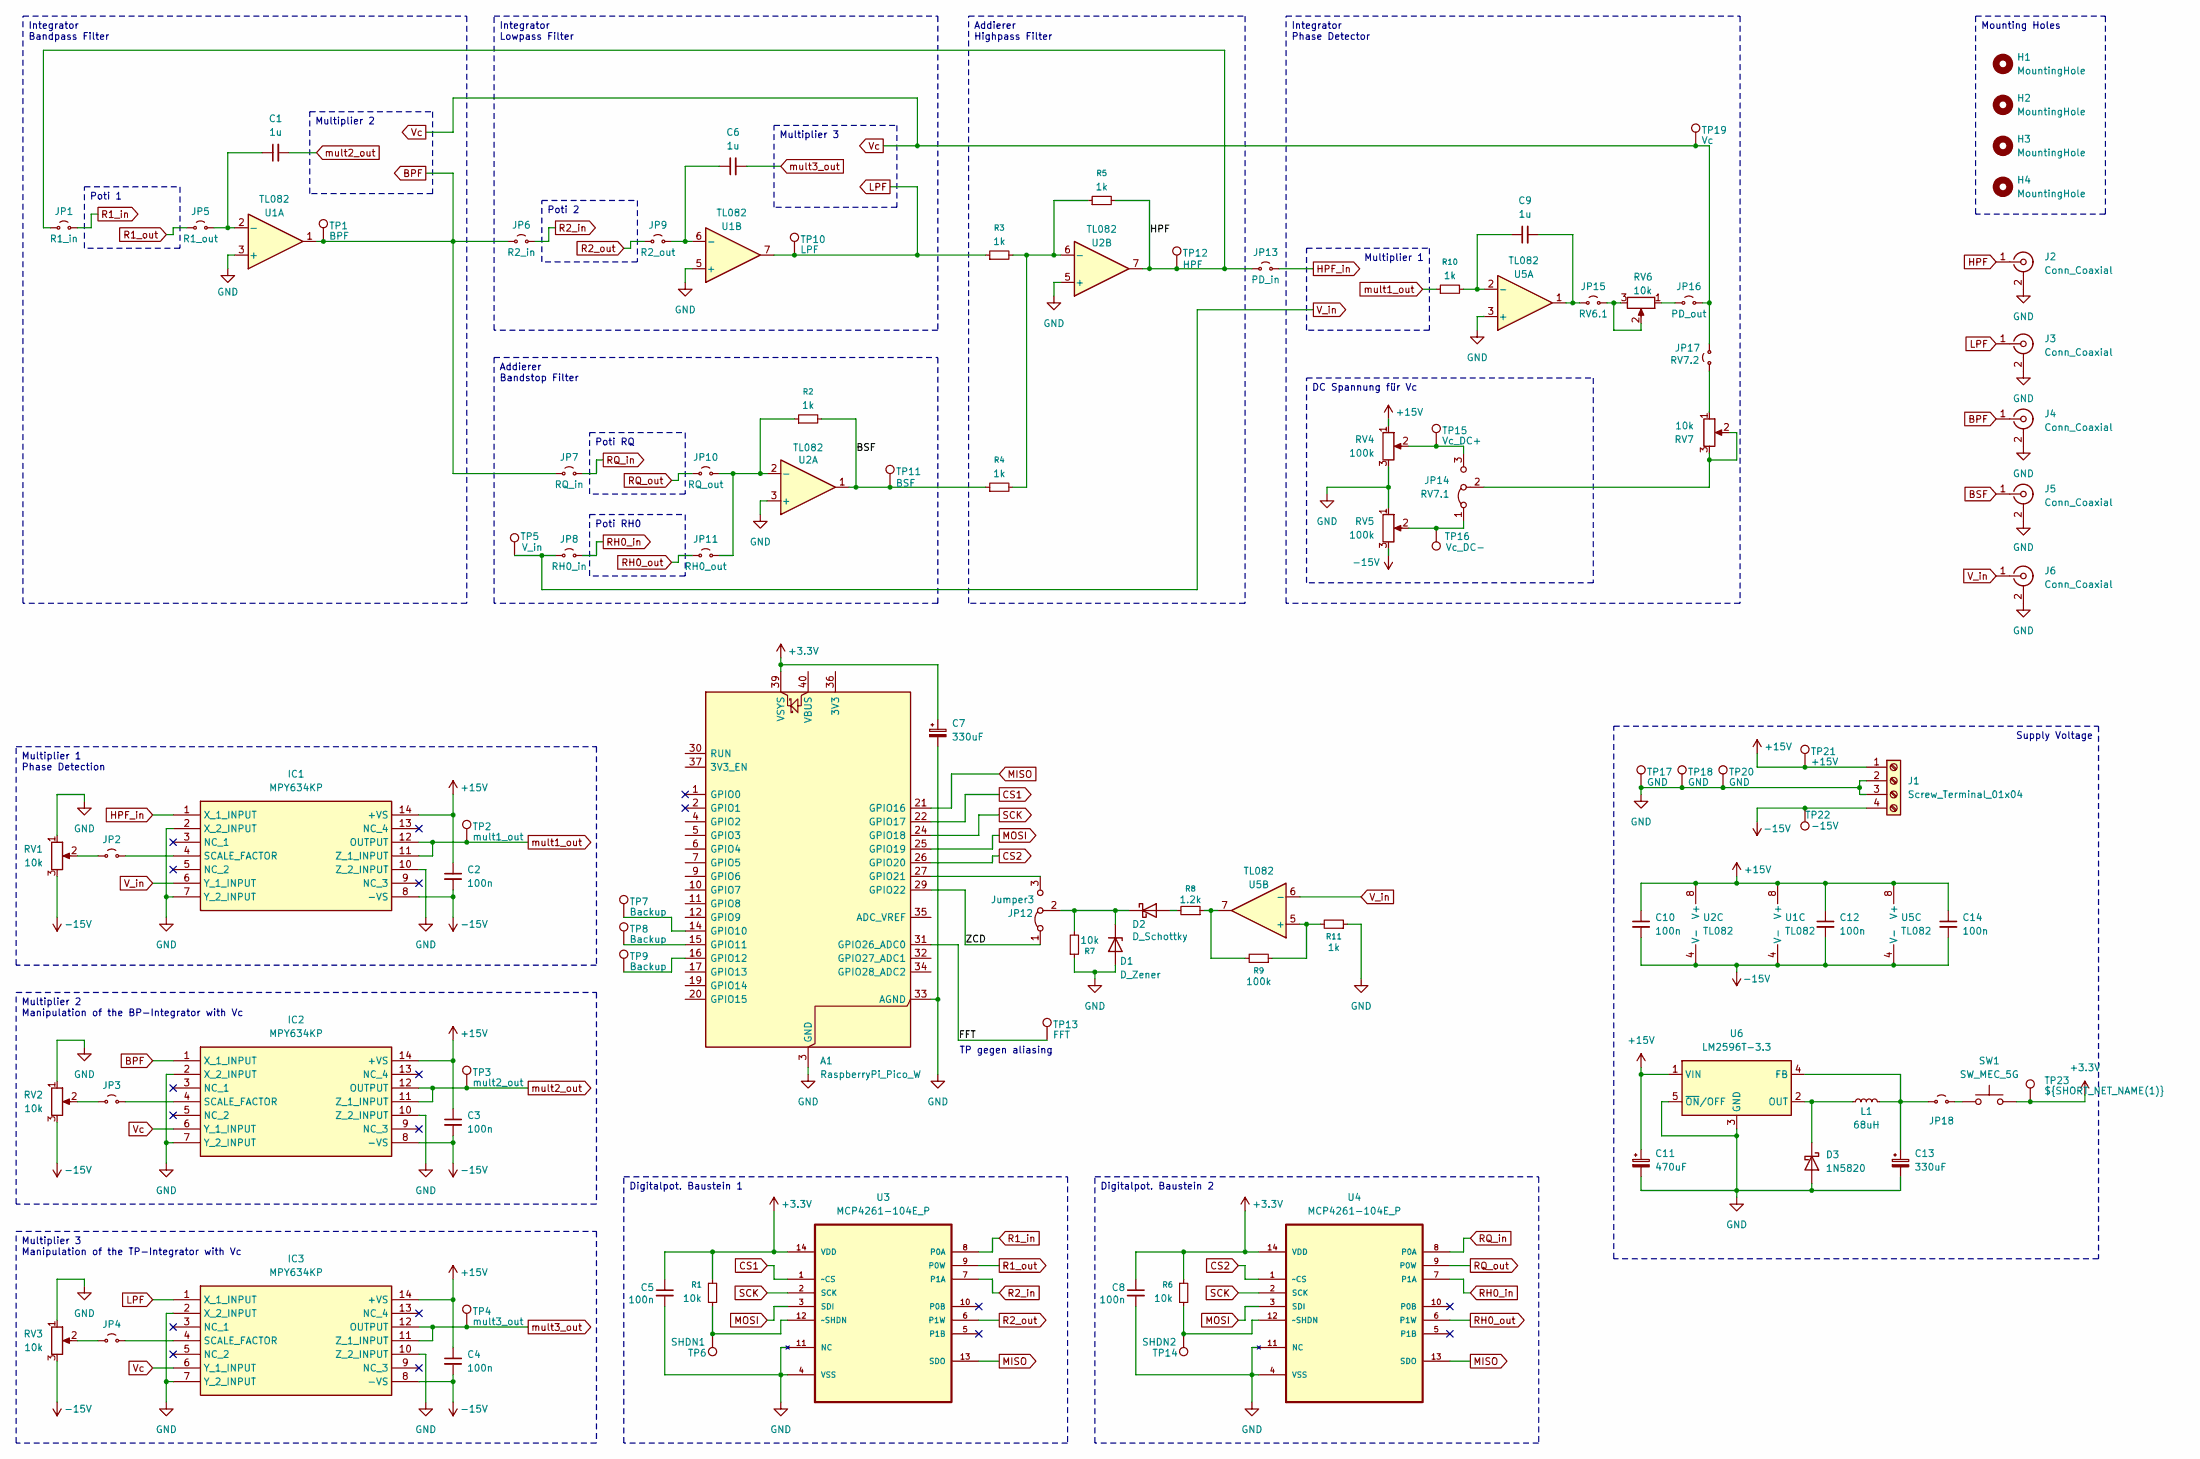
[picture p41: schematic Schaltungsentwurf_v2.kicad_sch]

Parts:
A1: RaspberryPi_Pico_W; RaspberryPi_Pico_W_THT
C1, C6, C9: 1u; 100nF
C2, C3, C4, C5, C8, C10, C12, C14: 100n; 100nF
C7, C13: 330uF; C_Radial_D10.0mm_H16.0mm_P5.00mm
C11: 470uF; C_Radial_D10.0mm_H16.0mm_P5.00mm
D1: D_Zener; 1N4001
D2: D_Schottky; 1N4001
D3: 1N5820; D_DO-27_P15.24mm_Horizontal
H1, H2, H3, H4: MountingHole; MountingHole_2.2mm_M2_DIN965
IC1, IC2, IC3: MPY634KP; DIP_14; Mouser Part Number 595-MPY634KP
J1: Screw_Terminal_01x04; Terminal 4 Pol
J2, J3, J4, J5, J6: Conn_Coaxial; BNC Edge Mount
JP1: R1_in; Connector 2 Pin 2.54mm
JP2, JP3, JP4, JP18: Connector 2 Pin 2.54mm
JP5: R1_out; Connector 2 Pin 2.54mm
JP6: R2_in; Connector 2 Pin 2.54mm
JP7: RQ_in; Connector 2 Pin 2.54mm
JP8: RH0_in; Connector 2 Pin 2.54mm
JP9: R2_out; Connector 2 Pin 2.54mm
JP10: RQ_out; Connector 2 Pin 2.54mm
JP11: RH0_out; Connector 2 Pin 2.54mm
JP12: Jumper3; Connector 3 Pin 2,54mm
JP13: PD_in; Connector 2 Pin 2.54mm
JP14: RV7.1; Connector 3 Pin 2,54mm
JP15: RV6.1; Connector 2 Pin 2.54mm
JP16: PD_out; Connector 2 Pin 2.54mm
JP17: RV7.2; Connector 2 Pin 2.54mm
L1: 68uH; L_Radial_D8.7mm_P5.00mm_Fastron_07HCP
R1, R6, R7: 10k; Resistor
R2, R3, R4, R5, R10, R11: 1k; Resistor
R8: 1.2k; Resistor
R9: 100k; Resistor
RV1, RV2, RV3, RV6, RV7: 10k; Potentiometer_Bourns_3296Y_Vertical
RV4, RV5: 100k; Potentiometer_Bourns_3296Y_Vertical
SW1: SW_MEC_5G; SW_DIP_SPSTx03_Piano_10.8x9.18mm_W7.62mm_P2.54mm
TP1: BPF; TestPoint; Mouser Part Number 534-5015
TP2: mult1_out; TestPoint; Mouser Part Number 534-5015
TP3: mult2_out; TestPoint; Mouser Part Number 534-5015
TP4: mult3_out; TestPoint; Mouser Part Number 534-5015
TP5: V_in; TestPoint; Mouser Part Number 534-5015
TP6: SHDN1; TestPoint; Mouser Part Number 534-5015
TP7, TP8, TP9: Backup; TestPoint; Mouser Part Number 534-5015
TP10: LPF; TestPoint; Mouser Part Number 534-5015
TP11: BSF; TestPoint; Mouser Part Number 534-5015
TP12: HPF; TestPoint; Mouser Part Number 534-5015
TP13: FFT; TestPoint; Mouser Part Number 534-5015
TP14: SHDN2; TestPoint; Mouser Part Number 534-5015
TP15: Vc_DC+; TestPoint; Mouser Part Number 534-5015
TP16: Vc_DC-; TestPoint; Mouser Part Number 534-5015
TP17, TP18, TP20: GND; TestPoint; Mouser Part Number 534-5015
TP19: Vc; TestPoint; Mouser Part Number 534-5015
TP21: +15V; TestPoint; Mouser Part Number 534-5015
TP22: -15V; TestPoint; Mouser Part Number 534-5015
TP23: ${SHORT_NET_NAME(1)}; TestPoint
U1, U2, U5: TL082; DIP_8
U3, U4: MCP4261-104E_P; DIP_14; MPN MCP4261-104E/P
U6: LM2596T-3.3; TO-220-5_P3.4x3.7mm_StaggerOdd_Lead3.8mm_Vertical

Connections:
+3.3V: A1.39 (VSYS), C5.1, C7.1, C8.1, R1.1, R6.1, SW1.3 (B), SW1.4 (B), TP23.1, U3.14 (VDD), U4.14 (VDD)
+15V: C2.1, C3.1, C4.1, C10.1, C11.1, C12.1, C14.1, IC1.14 (+VS), IC2.14 (+VS), IC3.14 (+VS), J1.1, RV4.1, TP21.1, U1.8 (V+), U2.8 (V+), U5.8 (V+), U6.1 (VIN)
-15V: C2.2, C3.2, C4.2, C10.2, C12.2, C14.2, IC1.8 (-VS), IC2.8 (-VS), IC3.8 (-VS), J1.4, RV1.3, RV2.3, RV3.3, RV5.3, TP22.1, U1.4 (V-), U2.4 (V-), U5.4 (V-)
/FFT: A1.31 (GPIO26_ADC0), TP13.1
/ZCD: A1.29 (GPIO22), JP12.1 (A)
BPF: IC2.1 (X_1_INPUT), J4.1 (In), JP6.1 (A), JP7.1 (A), TP1.1, U1.1
BSF: J5.1 (In), R2.2, R4.1, TP11.1, U2.1
CS1: A1.22 (GPIO17), U3.1 (~CS)
CS2: A1.26 (GPIO20), U4.1 (~CS)
GND: A1.3 (GND), A1.8 (GND), A1.13 (GND), A1.18 (GND), A1.23 (GND), A1.28 (GND), A1.33 (AGND), A1.38 (GND), C5.2, C7.2, C8.2, C11.2, C13.2, D1.2 (A), D3.2 (A), IC1.2 (X_2_INPUT), IC1.7 (Y_2_INPUT), IC1.10 (Z_2_INPUT), IC2.2 (X_2_INPUT), IC2.7 (Y_2_INPUT), IC2.10 (Z_2_INPUT), IC3.2 (X_2_INPUT), IC3.7 (Y_2_INPUT), IC3.10 (Z_2_INPUT), J1.2, J1.3, J2.2 (Ext), J3.2 (Ext), J4.2 (Ext), J5.2 (Ext), J6.2 (Ext), R7.1, R11.1, RV1.1, RV2.1, RV3.1, RV4.3, RV5.1, TP17.1, TP18.1, TP20.1, U1.3 (+), U1.5 (+), U2.3 (+), U2.5 (+), U3.4 (VSS), U3.11 (NC), U4.4 (VSS), U4.11 (NC), U5.3 (+), U6.3 (GND), U6.5 (~ON/OFF)
HPF: J2.1 (In), JP1.1 (A), JP13.1 (A), R5.2, TP12.1, U2.7
HPF_in: IC1.1 (X_1_INPUT), JP13.2 (B)
LPF: IC3.1 (X_1_INPUT), J3.1 (In), R3.1, TP10.1, U1.7
MISO: A1.21 (GPIO16), U3.13 (SDO), U4.13 (SDO)
MOSI: A1.25 (GPIO19), U3.3 (SDI), U4.3 (SDI)
unnamed: A1.14 (GPIO10), TP7.1
unnamed: A1.15 (GPIO11), TP8.1
unnamed: A1.16 (GPIO12), TP9.1
unnamed: A1.27 (GPIO21), JP12.3 (B)
unnamed: D1.1 (K), D2.1 (K), JP12.2 (C), R7.2
unnamed: D2.2 (A), R8.2
unnamed: D3.1 (K), L1.1, U6.2 (OUT)
unnamed: IC1.4 (SCALE_FACTOR), JP2.2 (B)
unnamed: IC2.4 (SCALE_FACTOR), JP3.2 (B)
unnamed: IC3.4 (SCALE_FACTOR), JP4.2 (B)
unnamed: JP2.1 (A), RV1.2
unnamed: JP3.1 (A), RV2.2
unnamed: JP4.1 (A), RV3.2
unnamed: C1.1, JP5.2 (B), U1.2 (-)
unnamed: C6.1, JP9.2 (B), U1.6 (-)
unnamed: JP10.2 (B), JP11.2 (B), R2.1, U2.2 (-)
unnamed: JP14.1 (A), RV5.2, TP16.1
unnamed: JP14.3 (B), RV4.2, TP15.1
unnamed: JP14.2 (C), RV7.2, RV7.3
unnamed: C9.2, JP15.1 (A), U5.1
unnamed: JP15.2 (B), RV6.2, RV6.3
unnamed: JP16.1 (A), RV6.1
unnamed: JP17.1 (A), RV7.1
unnamed: C13.1, JP18.1 (A), L1.2, U6.4 (FB)
unnamed: JP18.2 (B), SW1.1 (A), SW1.2 (A)
unnamed: R8.1, R9.2, U5.7
unnamed: R3.2, R4.2, R5.1, U2.6 (-)
unnamed: R1.2, TP6.1, U3.12 (~SHDN)
unnamed: R6.2, TP14.1, U4.12 (~SHDN)
unnamed: C9.1, R10.2, U5.2 (-)
unnamed: R9.1, R11.2, U5.5 (+)
R1_in: JP1.2 (B), U3.8 (P0A)
R1_out: JP5.1 (A), U3.9 (P0W)
R2_in: JP6.2 (B), U3.7 (P1A)
R2_out: JP9.1 (A), U3.6 (P1W)
RH0_in: JP8.2 (B), U4.7 (P1A)
RH0_out: JP11.1 (A), U4.6 (P1W)
RQ_in: JP7.2 (B), U4.8 (P0A)
RQ_out: JP10.1 (A), U4.9 (P0W)
SCK: A1.24 (GPIO18), U3.2 (SCK), U4.2 (SCK)
V_in: IC1.6 (Y_1_INPUT), J6.1 (In), JP8.1 (A), TP5.1, U5.6 (-)
Vc: IC2.6 (Y_1_INPUT), IC3.6 (Y_1_INPUT), JP16.2 (B), JP17.2 (B), TP19.1
mult1_out: IC1.11 (Z_1_INPUT), IC1.12 (OUTPUT), R10.1, TP2.1
mult2_out: C1.2, IC2.11 (Z_1_INPUT), IC2.12 (OUTPUT), TP3.1
mult3_out: C6.2, IC3.11 (Z_1_INPUT), IC3.12 (OUTPUT), TP4.1

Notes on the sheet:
TP gegen aliasing
Poti 2
Supply Voltage
Digitalpot. Baustein 1
Poti RH0
Multiplier 2
Multiplier 2 Manipulation of the BP-Integrator with Vc
Multiplier 1 Phase Detection
Mounting Holes
Poti 1
Multiplier 3 Manipulation of the TP-Integrator with Vc
Digitalpot. Baustein 2
Addierer Highpass Filter
Integrator Bandpass Filter
DC Spannung für Vc
Multiplier 3
Multiplier 1
Addierer Bandstop Filter
Integrator Lowpass Filter
Poti RQ
Integrator Phase Detector

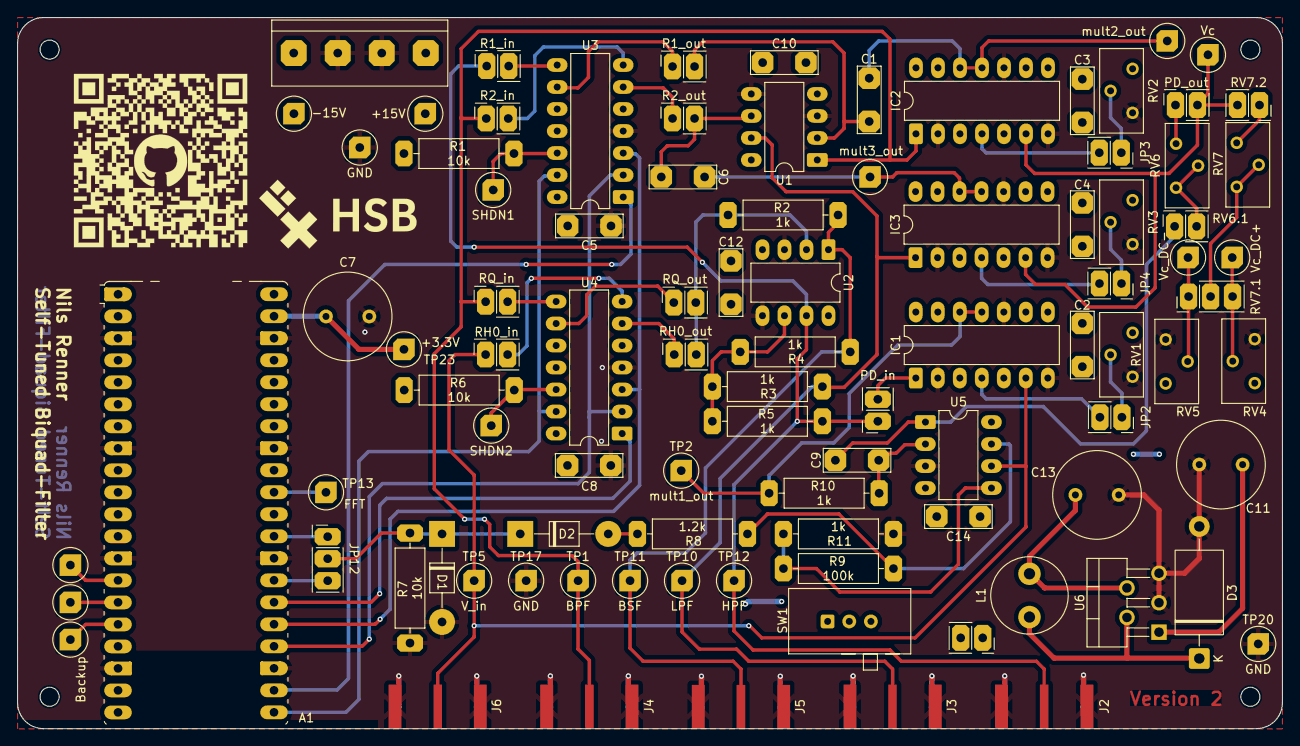
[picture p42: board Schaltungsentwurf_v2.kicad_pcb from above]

Board: 4 copper layers, 146.0 x 82.1 mm, 100 parts (1 on the bottom side), 60 nets.

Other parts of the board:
Ref**: Val**; git_qr
Ref**#2: Val**; logo_nils

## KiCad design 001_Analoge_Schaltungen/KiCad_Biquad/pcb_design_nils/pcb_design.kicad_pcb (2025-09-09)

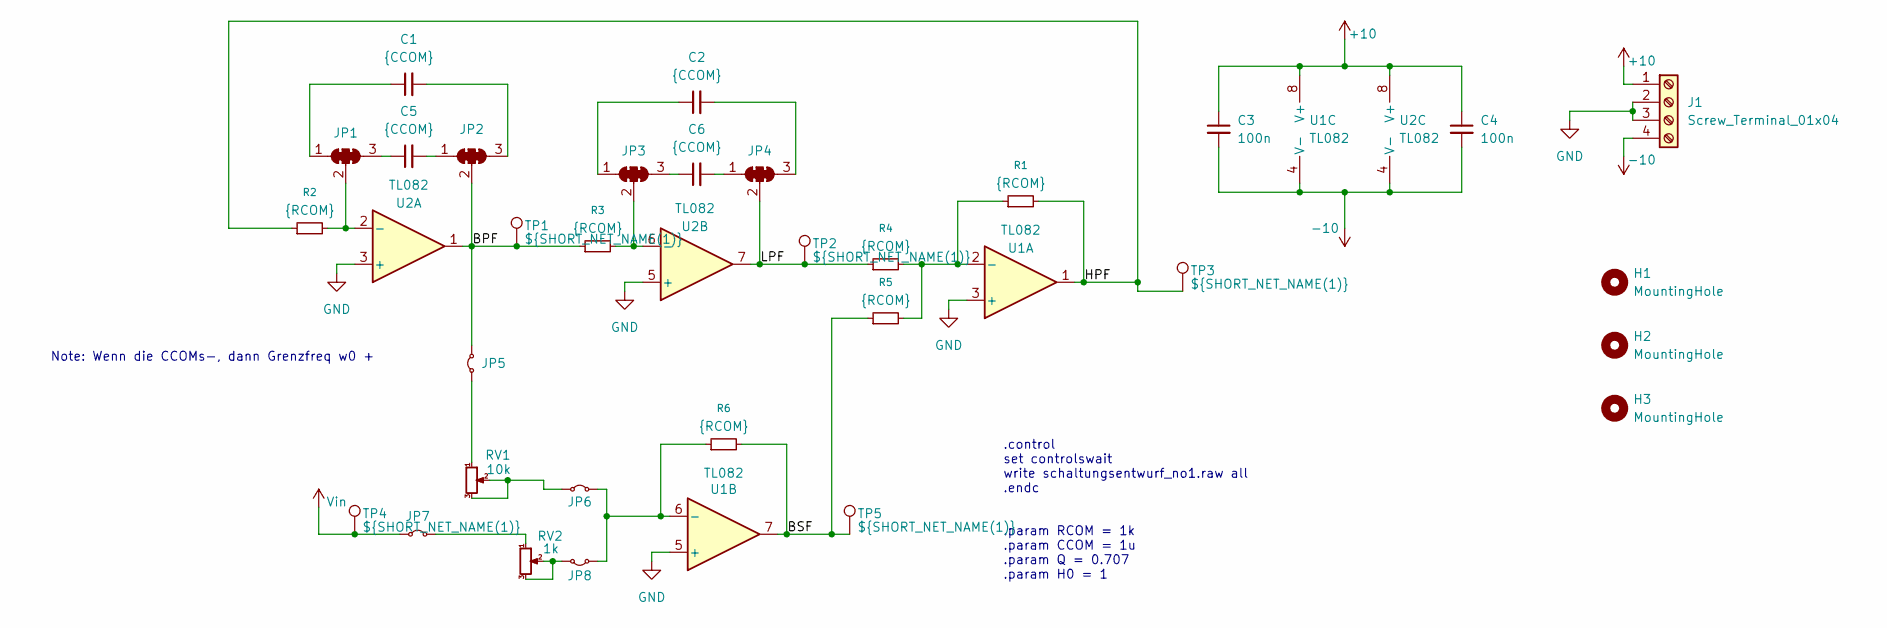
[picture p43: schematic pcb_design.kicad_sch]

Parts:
C1, C2: {CCOM}; 1-10uF
C3, C4: 100n; 100nF
C5, C6: {CCOM}; 100nF
H1, H2, H3: MountingHole; MountingHole_2.2mm_M2_DIN965
J1: Screw_Terminal_01x04; Terminal 4 Pol
JP1, JP2, JP3, JP4: SolderJumper_3_Bridged123; Connector 3 Pin 2,54mm
JP5, JP6, JP7, JP8: Jumper_2_Small_Bridged; Connector 2 Pin 2.54mm
R1, R2, R3, R4, R5, R6: {RCOM}; Resistor
RV1: 10k; Potentiometer_Bourns_3266W_Vertical
RV2: 1k; Potentiometer_Bourns_3266W_Vertical
TP1, TP2, TP3, TP4, TP5: ${SHORT_NET_NAME(1)}; TestPoint; Mouser Part Number 534-5015
U1, U2: TL082; DIP 8

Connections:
+10: C3.1, C4.1, J1.1, U1.8 (V+), U2.8 (V+)
-10: C3.2, C4.2, J1.4, U1.4 (V-), U2.4 (V-)
/BPF: JP2.2 (C), JP5.2 (B), R3.1, TP1.1, U2.1
/BSF: R5.1, R6.2, TP5.1, U1.7
/HPF: R1.2, R2.1, TP3.1, U1.1
/LPF: JP4.2 (C), R4.1, TP2.1, U2.7
GND: J1.2, J1.3, U1.3 (+), U1.5 (+), U2.3 (+), U2.5 (+)
unnamed: C1.1, JP1.1 (A)
unnamed: C5.1, JP1.3 (B)
unnamed: JP1.2 (C), R2.2, U2.2 (-)
unnamed: C5.2, JP2.1 (A)
unnamed: C1.2, JP2.3 (B)
unnamed: C2.1, JP3.1 (A)
unnamed: C6.1, JP3.3 (B)
unnamed: JP3.2 (C), R3.2, U2.6 (-)
unnamed: C6.2, JP4.1 (A)
unnamed: C2.2, JP4.3 (B)
unnamed: JP5.1 (A), RV1.1
unnamed: JP6.1 (A), RV1.2, RV1.3
unnamed: JP6.2 (B), JP8.1 (A), R6.1, U1.6 (-)
unnamed: JP7.2 (B), RV2.1
unnamed: JP8.2 (B), RV2.2, RV2.3
unnamed: R1.1, R4.2, R5.2, U1.2 (-)
Vin: JP7.1 (A), TP4.1

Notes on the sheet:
.param RCOM = 1k .param CCOM = 1u .param Q = 0.707 .param H0 = 1
Note: Wenn die CCOMs-, dann Grenzfreq w0 +
.control set controlswait write schaltungsentwurf_no1.raw all .endc

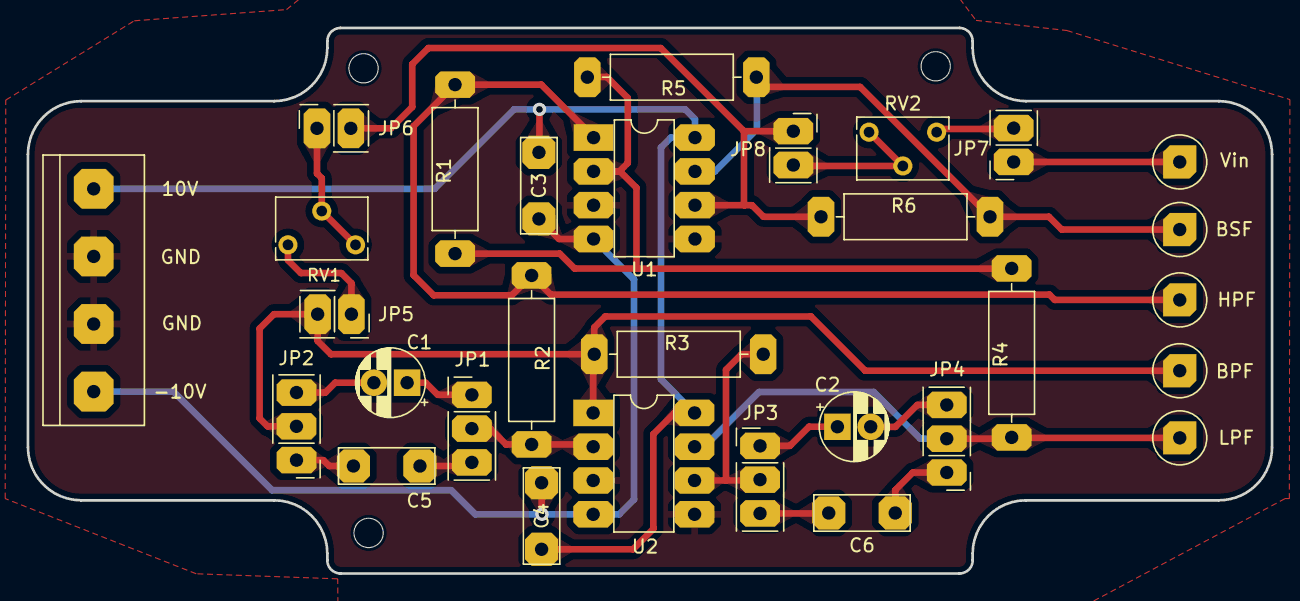
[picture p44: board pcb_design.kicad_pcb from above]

Board: 2 copper layers, 93.5 x 41.0 mm, 34 parts (0 on the bottom side), 24 nets.

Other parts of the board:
H4: MountingHole; MountingHole_2.2mm_M2_DIN965

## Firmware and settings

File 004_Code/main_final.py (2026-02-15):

import math
from machine import Pin, SPI, Timer
import rp2
import network
import socket
import time

# --- HOCHSCHULE BREMEN | BACHELORARBEIT | NILS RENNER | 2025/26 ---

led = Pin("LED", Pin.OUT)

# 1. Start-Check: LED blinkt 5 mal schnell
for _ in range(5):
    led.value(1)
    time.sleep(0.1)
    led.value(0)
    time.sleep(0.1)

led.value(1) # LED bleibt an -> WLAN wird gestartet

# =================================================================
# PIO FREQUENZZÄHLER KONFIGURATION
# =================================================================
@rp2.asm_pio()
def pulse_counter():
    mov(x, invert(null))     
    label("loop")
    wait(1, pin, 0)          
    wait(0, pin, 0)          
    jmp(x_dec, "loop")       

INPUT_PIN = 21
pin_in = Pin(INPUT_PIN, Pin.IN, Pin.PULL_DOWN)
sm = rp2.StateMachine(0, pulse_counter, in_base=pin_in)
MAX_COUNT = 0xFFFFFFFF

frequency_history = [0, 0, 0, 0, 0]
last_measured_freq = 0

KALIBRIERUNGS_FAKTOR = 1.007  
TORZEIT_MS = 2000 
TORZEIT_SEK = TORZEIT_MS / 1000

def measure_tick(t):
    global last_measured_freq
    sm.active(0)
    sm.exec("mov(isr, x)")
    sm.exec("push()")
    raw_value = sm.get()
    
    sm.exec("mov(x, invert(null))")
    sm.active(1)
    
    pulses = MAX_COUNT - raw_value
    korrigierte_freq = (pulses / TORZEIT_SEK) * KALIBRIERUNGS_FAKTOR
    
    if pulses < 1: 
        last_measured_freq = 0
    else:
        last_measured_freq = round(korrigierte_freq, 0) 
    
    frequency_history.insert(0, last_measured_freq)
    if len(frequency_history) > 5:
        frequency_history.pop()

sm.active(1)
freq_timer = Timer(-1)
freq_timer.init(period=TORZEIT_MS, mode=Timer.PERIODIC, callback=measure_tick)

# =================================================================
# FILTER LOGIK (AUF WIDERSTANDS-EINGABE ANGEPASST)
# =================================================================

### Initialisierung
# Startwerte
freq0 = 1000  # Jetzt als Widerstandswert (R) in Ohm interpretiert
Q_val = 1
H0_val = 1

# Digitalpoti-Parameter
max_step = 255
r_ges = 9.65e3
wiper_r = 4 

freq_wiper = 0
freq_r     = 0
Q_wiper = 0
Q_r     = 0
H0_wiper = 0
H0_r     = 0

def clamp_and_round(x):
    return int(round(max(0, min(255, x))))

# Frequenz-zu-Bit Berechnung auskommentiert
# def freq_2_bit(freq0):
#     freq_c = 1e-6
#     wfreq0 = freq0 * 2 * math.pi
#     freq_r = 1/(wfreq0 * freq_c)
#     freq_wiper = max_step * (1 - freq_r/r_ges) + wiper_r    
#     return clamp_and_round(freq_wiper), freq_r                                      

def Q_2_bit(Q_val):
    r_opv = 1000
    Q_r = Q_val * r_opv
    Q_wiper = max_step * (1 - Q_r/r_ges) + wiper_r
    return clamp_and_round(Q_wiper), Q_r

def H0_2_bit(H0_val):
    r_opv = 1000
    H0_r = r_opv/H0_val
    H0_wiper = max_step * (1 - H0_r/r_ges) + wiper_r
    return clamp_and_round(H0_wiper), H0_r

def bit_2_res(bit):
    res = r_ges * (1 - (bit-wiper_r)/max_step)      
    return res

def update_filter(r_val, q_v, h_v):
    global freq_wiper, freq_r, Q_wiper, Q_r, H0_wiper, H0_r, freq0, Q_val, H0_val
    freq0, Q_val, H0_val = r_val, q_v, h_v
    
    # Direkte Berechnung des Wiper-Werts aus dem Widerstand (r_val)
    freq_r = r_val
    freq_wiper = clamp_and_round(max_step * (1 - freq_r/r_ges) + wiper_r)
    
    Q_wiper,    Q_r    = Q_2_bit(Q_val)
    H0_wiper,   H0_r   = H0_2_bit(H0_val)

    set_wiper0(cs1, freq_wiper)
    set_wiper1(cs1, freq_wiper)
    set_wiper0(cs2, Q_wiper)
    set_wiper1(cs2, H0_wiper)

### SPI und Pins Initialisieren
spi = SPI(0, baudrate=1_000_000, polarity=0, phase=0, bits=8, firstbit=SPI.MSB,
    sck=Pin(18), mosi=Pin(19), miso=Pin(16))

cs1 = Pin(17, Pin.OUT, value=1) 
cs2 = Pin(20, Pin.OUT, value=1) 

def mcp_write(cs_pin, command, value):
    cs_pin.value(0)           
    spi.write(bytes([command & 0xFF, value & 0xFF]))  
    cs_pin.value(1)           

def set_wiper0(cs_pin, value):  
    cmd = 0x00                 
    mcp_write(cs_pin, cmd, value)

def set_wiper1(cs_pin, value):    
    cmd = 0x10                 
    mcp_write(cs_pin, cmd, value)

update_filter(freq0, Q_val, H0_val)

ap = network.WLAN(network.AP_IF)
ap.active(True)
ap.config(essid="Pico-Filter", password="filter123")
ap.ifconfig(("192.168.4.1", "255.255.255.0", "192.168.4.1", "8.8.8.8"))

s = socket.socket(socket.AF_INET, socket.SOCK_STREAM)
s.bind(('', 80))
s.listen(5)

while True:
    conn, addr = s.accept()
    request = conn.recv(1024).decode('utf-8')
    
    if "/set?" in request:
        try:
            params = request.split(' ')[1].split('?')[1].split('&')
            new_r = freq0
            new_q = Q_val
            new_h = H0_val
            for p in params:
                k, v = p.split('=')
                if k == 'res': new_r = float(v)
                if k == 'Q':   new_q = float(v)
                if k == 'H0':  new_h = float(v)
            update_filter(new_r, new_q, new_h)
        except:
            pass

    history_rows = "".join([f"<tr><td>{f} Hz</td></tr>" for f in frequency_history])

    html = f"""
    <!DOCTYPE html>
    <html>
    <head>
        <title>Pico Filter Control</title>
        <meta charset="UTF-8">
        <meta http-equiv="refresh" content="15">
        <style>
            body {{ font-family: 'Segoe UI', Arial, sans-serif; margin: 0; padding: 20px; background: #eceff1; color: #333; }}
            .container {{ max-width: 1000px; margin: auto; }}
            .header {{ 
                background: #263238; color: white; padding: 20px; border-radius: 8px; 
                margin-bottom: 20px; text-align: center; box-shadow: 0 4px 6px rgba(0,0,0,0.1); 
            }}
            .layout {{ display: flex; gap: 25px; flex-wrap: wrap; }}
            .card {{ background: white; padding: 20px; border-radius: 8px; box-shadow: 0 2px 4px rgba(0,0,0,0.05); flex: 1; min-width: 300px; }}
            h2 {{ color: #0078d7; border-bottom: 2px solid #eee; padding-bottom: 10px; margin-top: 0; }}
            table {{ border-collapse: collapse; margin-top: 15px; width: 100%; }}
            th, td {{ border: 1px solid #e0e0e0; padding: 10px; text-align: center; }}
            th {{ background: #f5f5f5; font-weight: 600; }}
            .freq-display {{ font-size: 3em; color: #0078d7; font-weight: bold; margin: 15px 0; text-align: center; }}
            .btn {{ background: #0078d7; color: white; border: none; padding: 12px 20px; border-radius: 4px; cursor: pointer; font-size: 16px; width: 100%; }}
            .btn:hover {{ background: #005a9e; }}
            input {{ padding: 10px; border: 1px solid #ccc; border-radius: 4px; margin-bottom: 15px; width: 90%; }}
            label {{ font-weight: bold; font-size: 0.9em; }}
        </style>
    </head>
    <body>
        <div class="container">
            <div class="header">
                <h1 style="margin:0; font-size: 2.2em; letter-spacing: 1px;">
                    Self-Tuned Biquad-Filter
                </h1>
                
                <p style="margin: 8px 0 15px 0; font-size: 1.1em; color: #81d4fa; font-weight: 300;">
                    Digitale Parametersteuerung & Echtzeit-Validierung via RP2350
                </p>
                
                <div style="height: 1px; background: rgba(255,255,255,0.2); width: 60%; margin: 10px auto;"></div>
                
                <p style="margin: 10px 0 0 0; font-size: 0.9em; opacity: 0.9; word-spacing: 2px;">
                    <strong>Hochschule Bremen</strong> &nbsp;•&nbsp; 
                    Bachelorarbeit &nbsp;•&nbsp; 
                    <strong>Nils Renner</strong> &nbsp;•&nbsp; 
                    2025/26
                </p>
            </div>

            <div class="layout">
                <div class="card">
                    <h2>Filter-Parameter</h2>
                    <form action="/set" method="get">
                        <label>Soll-Widerstand (f<sub>0</sub>-bestimmend) [&Omega;]:</label><br>
                        <input type="number" name="res" value="{freq0}">
                        <label>Güte (Q):</label><br>
                        <input type="number" name="Q" step="0.1" value="{Q_val}"><br>
                        <label>Verstärkung (H0):</label><br>
                        <input type="number" name="H0" step="0.1" value="{H0_val}"><br>
                        <input type="submit" class="btn" value="Werte an Filter senden">
                    </form>

                    <h2 style="margin-top:20px;">Aktuelle Wiper-Konfiguration</h2>
                    <table>
                        <tr><th>Parameter</th><th>Soll</th><th>Wiper (Bit)</th><th>R-Ist</th></tr>
                        <tr><td>Widerstand R</td><td>{freq0} &Omega;</td><td>{freq_wiper}</td><td>{bit_2_res(freq_wiper):.1f} &Omega;</td></tr>
                        <tr><td>Güte (Q)</td><td>{Q_val}</td><td>{Q_wiper}</td><td>{bit_2_res(Q_wiper):.1f} &Omega;</td></tr>
                        <tr><td>Verstärkung (H0)</td><td>{H0_val}</td><td>{H0_wiper}</td><td>{bit_2_res(H0_wiper):.1f} &Omega;</td></tr>
                    </table>
                </div>

                <div class="card">
                    <h2>Frequenzerfassung</h2>
                    <div class="freq-display">{last_measured_freq} Hz</div>
                    <table>
                        <tr><th>Letzte 5 Messungen</th></tr>
                        {history_rows}
                    </table>
                    <p style="text-align:center; color: #666; font-size: 0.8em; margin-top: 30px;">
                        🔄 Automatischer Refresh alle 15 Sekunden
                    </p>
                </div>
            </div>
        </div>
    </body>
    </html>
    """
    
    conn.send('HTTP/1.1 200 OK\r\nContent-Type: text/html\r\n\r\n')
    conn.send(html)
    conn.close()

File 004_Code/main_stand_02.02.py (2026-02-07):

import math
from machine import Pin, SPI
#import machine

import network
import socket
import time


led = Pin("LED", Pin.OUT)

# 1. Start-Check: LED blinkt 5 mal schnell
for _ in range(5):
    led.value(1)
    time.sleep(0.1)
    led.value(0)
    time.sleep(0.1)

led.value(1) # LED bleibt an -> WLAN wird gestartet




###   Initialisierung
# Sollwerte
freq0 = 160  # Bauteilbedingte Grenzfrequenz in Hz
Q_val = 1
H0_val = 1

# Digitalpoti-Parameter
max_step = 255
r_ges = 9.65e3
wiper_r = 4  #2  # wiper_r von ca 70 Ohm


freq_wiper = 0
freq_r     = 0

Q_wiper = 0
Q_r     = 0

H0_wiper = 0
H0_r     = 0


# Werte berechnen
def clamp_and_round(x):
    return int(round(max(0, min(255, x))))

def freq_2_bit(freq0):
    freq_c = 1e-6   #1uF
    #vielleicht einzelne rges für jeden wiper?
    wfreq0 = freq0 * 2 * math.pi
    freq_r = 1/(wfreq0 * freq_c)
    freq_wiper = max_step * (1 - freq_r/r_ges) + wiper_r    # mein R in der Gleichung
    return clamp_and_round(freq_wiper), freq_r                                      

def Q_2_bit(Q_val):
    r_opv = 1000
    Q_r = Q_val * r_opv
    Q_wiper = max_step * (1 - Q_r/r_ges) + wiper_r
    return clamp_and_round(Q_wiper), Q_r

def H0_2_bit(H0_val):
    r_opv = 1000
    H0_r = r_opv/H0_val
    H0_wiper = max_step * (1 - H0_r/r_ges) + wiper_r
    #H0_wiper = int(round(H0_wiper))
    return clamp_and_round(H0_wiper), H0_r

def bit_2_res(bit):
    res = r_ges * (1 - (bit-wiper_r)/max_step)      #vorher bit-wiper_r
    return res

def update_filter(freq0, Q_val, H0_val):
    global freq_wiper, freq_r, Q_wiper, Q_r, H0_wiper, H0_r
    freq_wiper, freq_r = freq_2_bit(freq0)
    Q_wiper,    Q_r    = Q_2_bit(Q_val)
    H0_wiper,   H0_r   = H0_2_bit(H0_val)

    set_wiper0(cs1, freq_wiper)
    set_wiper1(cs1, freq_wiper)
    set_wiper0(cs2, Q_wiper)
    set_wiper1(cs2, H0_wiper)

    print("Filter aktualisiert:")
    print(" freq =", freq0, "->", freq_wiper, "(", bit_2_res(freq_wiper), "Ohm )")
    print(" Q    =", Q_val, "->", Q_wiper,    "(", bit_2_res(Q_wiper),    "Ohm )")
    print(" H0   =", H0_val, "->", H0_wiper,   "(", bit_2_res(H0_wiper),   "Ohm )")


### SPI und Pins Initialisieren
# SPI Channel 0 auf GPIO18/19/16
spi = SPI(0, baudrate=1_000_000, polarity=0, phase=0, bits=8, firstbit=SPI.MSB,
    sck=Pin(18), mosi=Pin(19), miso=Pin(16))

# Chip-Selects (aktiv low)
cs1 = Pin(17, Pin.OUT, value=1) #Mittenfreqzenzbestimmend
cs2 = Pin(20, Pin.OUT, value=1) #Für Q und H0 wiper0 = Q

# Befehlswort aufbauen
def mcp_write(cs_pin, command, value):
    cs_pin.value(0)           # CS low -> Chip wird angesprochen
    spi.write(bytes([command & 0xFF, value & 0xFF]))  # 16 Bit: [Cmd|Data]
    cs_pin.value(1)           # CS high -> Chip wird freigegeben


def set_wiper0(cs_pin, value):  # Immer Wiper0 des Chips
    cmd = 0x00                 # 0000 00xx = Wiper 0 Adresse + Write
    mcp_write(cs_pin, cmd, value)

def set_wiper1(cs_pin, value):  # Immer Wiper1 des Chips  
    cmd = 0x10                 # 0001 00xx = Wiper 1 Adresse + Write
    mcp_write(cs_pin, cmd, value)
    
        
    
    
# eigenes WLAN aufbauen statt WLAN verbinden

ap = network.WLAN(network.AP_IF)
ap.active(True)

ap.config(
    essid="Pico-Filter",
    password="filter123"
)

# Feste IP setzen
ap.ifconfig(("192.168.4.1", "255.255.255.0", "192.168.4.1", "8.8.8.8"))

print("Access Point aktiv")
print("SSID: Pico-Filter")
print("IP:", ap.ifconfig()[0])
time.sleep(1)

#HTTP Server
addr = socket.getaddrinfo("0.0.0.0", 80)[0][-1]
server = socket.socket()
server.setsockopt(socket.SOL_SOCKET, socket.SO_REUSEADDR, 1) # sonst startet der gleiche Server beim reupload nicht
server.bind(addr)
server.listen(1)

print("HTTP Server läuft...")
AP_IP = ap.ifconfig()[0]
print("http://%s/filter" % AP_IP)

update_filter(freq0, Q_val, H0_val)


# Frequenzzähler
INPUT_PIN = 21
freq_pin = Pin(INPUT_PIN, Pin.IN, Pin.PULL_DOWN)
pulse_count = 0
last_measured_freq = 0

def handle_interrupt(pin):
    global pulse_count
    pulse_count += 1

freq_pin.irq(trigger=Pin.IRQ_RISING, handler=handle_interrupt)

history = []



###         Mailoop
while True:
    # 1. Torzeit: 1 Sekunde lang Impulse zählen (blockiert hier kurz)
    pulse_count = 0      
    time.sleep(1.0)      
    last_measured_freq = pulse_count
    
    # Historie aktualisieren (neuester Wert oben)
    history.insert(0, last_measured_freq)
    if len(history) > 5:
        history.pop()

    try:
        # Wichtig: Timeout, damit der Loop nicht bei accept() hängen bleibt
        server.settimeout(0.1) 
        client, remote_addr = server.accept()
        request = client.recv(1024).decode()

        if "GET /set?" in request:
            line = request.split("\r\n")[0]
            path = line.split(" ")[1]
            query = path.split("?")[1]
            params = query.split("&")

            for p in params:
                key, value = p.split("=")
                if key == "freq":
                    freq0 = float(value)
                elif key == "Q":
                    Q_val = float(value)
                elif key == "H0":
                    H0_val = float(value)
            
            update_filter(freq0, Q_val, H0_val)

        # HTML für die Frequenz-Tabelle generieren
        history_rows = ""
        for val in history:
            history_rows += f"<tr><td>{val} Hz</td></tr>"

        html = f"""
        <!DOCTYPE html>
        <html>
        <head>
            <title>Pico Filter UI</title>
            <meta charset="UTF-8">
            <style>
                body {{ font-family: sans-serif; margin: 20px; }}
                .layout {{ display: flex; gap: 50px; }}
                table {{ border-collapse: collapse; margin-top: 10px; }}
                th, td {{ border: 1px solid #999; padding: 8px; text-align: center; }}
                th {{ background: #eee; }}
            </style>
        </head>
        <body>
            <h1>Pico Filter Steuerung</h1>

            <div class="layout">
                <div>
                    <h2>Parameter setzen</h2>
                    <form action="/set" method="get">
                        <label>Freq (Hz):</label><br>
                        <input type="number" name="freq" step="1" value="{freq0}"><br><br>
                        <label>Q:</label><br>
                        <input type="number" name="Q" step="0.1" value="{Q_val}"><br><br>
                        <label>H0:</label><br>
                        <input type="number" name="H0" step="0.1" value="{H0_val}"><br><br>
                        <input type="submit" value="Setzen">
                    </form>
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

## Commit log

2025-09-09 Kopie der Auto Messwertaufnahme erstellt
2025-09-16 Simulation muss aufgrund von neuistallation von KiCad neu gemaucht werden, 1/2 fertig
    [selfe_tuned_filter.kicad_sch]
2025-09-20 chore:add untracked files
    [Zeitplan_b.ods, analog_multiplier.kicad_pcb, analog_multiplier.kicad_sch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]
2025-09-20 chore: aufgeräumt
    [Zeitplan_b.ods]
2026-02-01 pcb_version_2, new pcb holder
    [Schaltungsentwurf_v2.kicad_pcb, Schaltungsentwurf_v2.kicad_sch]
2026-02-07 PD-Vermessung und Sprungantwortsimulation
    [Schaltungsentwurf_v2.kicad_pcb, Schaltungsentwurf_v2.kicad_sch, WFM02.CSV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]
2026-02-11 Durchführung von Simulationen am Gesamtsystem
    [self_tuned_filter.kicad_sch]
2026-02-15 Weiterarbeit an UI und Nulldurchgangszähler
2026-02-23 aktueller Stand
    [FIN_12.CSV, FIN_13.CSV, FIN_200.CSV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]
2026-02-24 Ordnerstruktur verbessert
    [pcb_holder.FCStd, pcb_holder.stl]
2026-02-27 Hinzufügen der PDF
    [Schaltungsentwurf_v2.kicad_sch]
